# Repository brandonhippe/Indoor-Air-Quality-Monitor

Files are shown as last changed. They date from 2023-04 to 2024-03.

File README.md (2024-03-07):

# 412AirQualityCapstone
2023 Portland State University ECE 412 Air Quality Capstone Project
<br>
<p>
We spend most of our lives indoors, but most of us lack the tools to assess the quality of the air
we breathe in those environments. Personal tools are available, albeit expensive, and must be
inconveniently carried with us along with all the other tools of our daily lives. Instead, we want to
make it easy to instrument buildings, continuously monitor the indoor environment, and report
data back to us. We can make it easy by making cheap, reliable devices that don't need
recharging for a long time. Three features of indoor air are expected to be monitored: 2.5 μm
particle count or PM2.5, carbon dioxide (CO2) concentration, and ventilation air speed.</p>
<br>
<p>
Regarding CO2, Statistically significant decrements occurred in cognitive performance
(decision making, problem resolution) starting at 1000 ppm . It is also a
good proxy for ventilation; high CO2 levels mean the room is poorly ventilated, which increases
the risk of passing airborne diseases such as COVID. After I finish Zoom meeting in a closed
room at home, the CO2 level is often over 1200!</p>
<br>
<p>
Regarding PM2.5, the WHO recommends an upper limit of 5 ug/m3 (microgram per cubic
meter) average annually and 15 ug/m3 average over a 24 hour period. As this project
document is being written, the outdoor air in Portland is over 30 ug/m3!</p>
<br>
<p>
An air speed sensor, or anemometer, can help us calculate how much air is flowing into or out of
a room and help understand why CO2 is high. The system should report an invalid value (e.g.,
not zero because zero airflow is a valid value) if the anemometer is not connected.</p>
<br>
<p>The system will be based on components past capstone teams have successfully incorporated
such as the TI MSP430 (including super low-power sleep modes). In this iteration, we will aim to
replace the closed-source proprietary SmartMesh IP wireless system with the OpenWSN
open-source wireless networking system.</p>
<br>
<h3>Project Goals</h3>
<br>
<p>Produce a fully wireless sensor data logger incorporating as many open-source components as
possible and able to be produced at a very low cost. A particular goal of this project is very low
power performance: sensors, communication system, and the microcontroller should be in as
low a power state as possible when not in use such that batteries need to be changed, at most,
annually. (The lifetime of a smoke detector would be even better!)</p>
<br>
<p>Data should be temporarily logged locally and wirelessly communicated to base station(s) as
appropriate. A stretch goal includes visualization dashboard to present the logged data
graphically for at-a-glance use. The device should be mechanically integrated into as small a
form-factor as is practical and contained in a robust housing appropriate for indoor
environments.</p>

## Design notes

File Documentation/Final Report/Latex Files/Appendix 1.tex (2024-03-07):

\begin{table}[htbp]
  \centering
  \small
  \renewcommand{\arraystretch}{1.2}
  \begin{adjustbox}{max width=\textwidth}
      \begin{tabular}{|l|l|l|r|r|}
        \hline
        Quantity & Model \# and description & Manufacturer & Price per unit & Total Price \\ 
        \hline
        1 & CG-Anem (Wind Sensor With I2C Interface) & Climate Guard & \$23 & \$23 \\ 
        \hline
        1 & SGP30: (eCO$_2$ Sensor) & Adafruit & \$17.50 & \$17.50 \\ 
        \hline
        1 & US-100 Ultrasonic Distance Sensor Module & Adafruit & \$6.95 & \$6.95 \\ 
        \hline
        1 & SPS30 (PM2.5 Sensor)  & Sensirion & \$50.25 & \$50.25 \\ 
        \hline
        4 & P Channel Mosfet & Alpha-Omega & \$0.35 & \$1.40 \\ 
        \hline
        2 & N Channel Mosfet & Alpha-Omega & \$0.33 & \$0.66 \\ 
        \hline
        6 & 47k Resistor & Yageo & \$0.04 & \$0.24 \\ 
        \hline
        3 & 0 ohm Resistor & Yageo & \$0.05 & \$0.15 \\ 
        \hline
        9 & Pin Header & Sullins & \$0.57 & \$5.13 \\ 
        \hline
        2 & Pin Header Male & Molex & \$0.67 & \$1.34 \\ 
        \hline
        1 & MSP-EXP430FR2355 & Texas Instruments & \$15.33 & \$15.33 \\ 
        \hline
        4 & LI18650JL PROTECTED & Jauch Quartz & \$13.05 & \$52.20 \\ 
        \hline
        1 & BK-18650-PC8 (4 cell 18650 battery holder) & MPD & \$8.06 & \$8.06 \\ 
        \hline
        1 & DC9003A-C (SmartMesh) & Analog Devices & \$642 & \$642 \\ 
        \hline
      \end{tabular}
  \end{adjustbox}
\end{table}

\begin{table}[htbp]
  \centering
  \small
  \renewcommand{\arraystretch}{1.2}
  \begin{adjustbox}{max width=\textwidth}
    \begin{tabular}{|l|l|}
        \hline
        Model \# and description & Link \\ \hline
        CG-Anem (Wind Sensor With I2C Interface)          & \url{https://www.tindie.com/products/climateguard/wind-sensor-with-i2c-anemometr-arduino/} \\ \hline
        SGP30: (eCO$_2$ Sensor)                           & \url{https://www.digikey.com/en/products/detail/adafruit-industries-llc/3709/8258468} \\ \hline
        US-100 Ultrasonic Distance Sensor Module          & \url{https://www.digikey.com/en/products/detail/adafruit-industries-llc/4019/9808308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} \\ \hline
        SPS30 (PM2.5 Sensor)                              & \url{https://www.digikey.com/en/products/detail/sensirion-ag/SPS30/9598990} \\ \hline
        P Channel Mosfet                                  & \url{https://www.digikey.com/en/products/detail/alpha-omega-semiconductor-inc/AO3401A/1855773} \\ \hline
        N Channel Mosfet                                  & \url{https://www.digikey.com/en/products/detail/alpha-omega-semiconductor-inc/AO3422/1855787} \\ \hline
        47k Resistor                                      & \url{https://www.digikey.com/en/products/detail/yageo/RC1206FR-0747KL/728931} \\ \hline
        0 ohm Resistor                                    & \url{https://www.digikey.com/en/products/detail/yageo/RC1206JR-070RL/729184} \\ \hline
        Pin Header                                        & \url{https://www.digikey.com/en/products/detail/sullins-connector-solutions/PPPC101LFBN-RC/810182} \\ \hline
        Pin Header Male                                   & \url{https://www.digikey.com/en/products/detail/molex/0022284104/313970} \\ \hline
        MSP-EXP430FR2355                                  & \url{https://www.digikey.com/en/products/detail/texas-instruments/MSP-EXP430FR2355/9491427} \\ \hline
        LI18650JL PROTECTED                               & \url{https://www.digikey.com/en/products/detail/jauch-quartz/LI18650JL-PROTECTED/12396970} \\ \hline
        BK-18650-PC8 (4 cell 18650 battery holder)        & \url{https://www.digikey.com/en/products/detail/mpd-memory-protection-devices/BK-18650-PC8/2330515} \\ \hline
        DC9003A-C (Smart Mesh)                            & \url{https://www.mouser.com/ProductDetail/Analog-Devices/DC9003A-C?qs=ytflclh7QUUd5QPivzMO2w\%3D\%3D} \\ \hline
    \end{tabular}
  \end{adjustbox}
\end{table}
\label{tab:BOM}
Total Price: \$166.88 excluding given parts \$182.21 including MSP430

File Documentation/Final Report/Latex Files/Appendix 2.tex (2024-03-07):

\renewcommand{\thesubsection}{2.\arabic{subsection}}
\subsection{Energia Issues}
Make sure “Energia MSP430 boards” is updated to version 1.0.7 or later by going to Tools, then Board, then Board Manager.
\subsection{Java Runtime Environment error}

To solve this issue, You must save Energia to your C: Folder and open it from there each time. The Desktop Shortcut will keep giving you this error. 

\subsection{Sensor Issues}
Sensors drawing too much power:
\\We removed the power and low power LEDs on all of the sensors used as they were drawing too much.
\\CO2 sensor showing 400 PPM or 55K PPM:
\\Stop calibrating, run it for 30 seconds.

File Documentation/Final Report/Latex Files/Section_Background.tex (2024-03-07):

Our team wanted to make it easy to continuously monitor an indoor environment, and report data back to a host. Our aim was to make monitoring easy by making cheap, reliable devices that do not require frequent recharging. Three features of indoor air quality are expected to be monitored: 2.5 µm particle count or PM2.5, carbon dioxide (CO$_2$) concentration, and local air flow rate.\\
\\
Regarding CO$_2$, statistically significant decrements occurred in cognitive performance
(decision making, problem resolution) starting at 1000 ppm.  CO$_2$  concentration is also a
good proxy for ventilation; high CO$_2$ levels mean the room is poorly ventilated, which increases
the risk of passing airborne diseases such as COVID19.\\
\\
Regarding PM2.5, the WHO recommends an upper limit of 5 µg/m3 (microgram per cubic
meter) average annually and 15 µg/m3 average over a 24 hour period . \\
\\
An air speed sensor, or anemometer, can help us calculate how much air is flowing into or out of
a room and help understand why CO$_2$ and/or PM2.5 is high. \\
\\
The system is based on components past capstone teams have successfully incorporated
such as the TI MSP430 (selected for its particularly low-power sleep modes). In this iteration, a goal was to
replace the closed-source proprietary SmartMesh IP wireless system with the OpenWSN open-source wireless networking system.\\
\\

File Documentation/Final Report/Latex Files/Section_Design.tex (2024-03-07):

When selecting sensors for this project, the team had to select PM2.5 and CO$_2$ sensors that were energy efficient, relatively accurate for our setting, and fit within a budget of \$3,000 for all 10 possible nodes. \\
\\
When selecting the CO$_2$ sensor, the team considered selecting a true CO$_2$ sensor like the SCD30 which would produce very accurate readings yet was more expensive than an ECO2 (estimated CO$_2$) sensor which would prove to be less accurate due to its nature of estimating CO$_2$ based on ethanol and H$_2$ levels in the air. Our team ultimately chose to go with the SGP30 (equivalent CO$_2$) sensor as we are merely sensing elevated levels of carbon dioxide and therefore do not need to get incredibly precise readings. Anything over 1,000 PPM would simply be very high and might constitute an evacuation of room or need for more airflow. \\
\\
\begin{table}[h]
\centering
\begin{tabular}{|l|l|l|}
\hline
Sensor             & SGP 30      & SCD 30                   \\ \hline
Type               & eCO$_2$      & CO$_2$                     \\ \hline
Additional sensors & VOC         & temperature and humidity \\ \hline
Range              & 400-60,000 PPM & 400-10,000 PPM              \\ \hline
Accuracy           & $\pm$15\%      & $\pm$30 PPM +3\%              \\ \hline
Price              & \$17.50      & \$58.95                   \\ \hline
\end{tabular}
\caption{CO$_2$ Sensor Finalists}
\label{tab:CO_2 Sensor Finalists}
\end{table}
\\
\subsection{PM2.5 Sensor}
For the PM2.5 sensor, the team decided to go with the SPS30 as it was the least power hungry among our options at the time. It was also the most readily available, and was sourced from Sensirion like the SGP30 which would cut costs if this product were to be mass produced. The PM2.5 Sensor Finalists table below shows the specific trade offs our team considered when selecting this sensor.\\
\\
\begin{table}[h]
\centering
\resizebox{\textwidth}{!}{%
\begin{tabular}{|l|p{4cm}|p{4cm}|p{4cm}|}
\hline
Sensor                      & PMS5003                                                                & PAS-IN-01                                & SPS30                                    \\ \hline
Range (concentration)       & 0-500 ug/m\textasciicircum{}3            & 0-1500 ug/m\textasciicircum{}3           & 0-1000 ug/m\textasciicircum{}3           \\ \hline
Accuracy                    & ±10\% or ±10 ug/m3, whichever is greater &  ±10\% or ±10 ug/m3, whichever is greater & ±10\% or ±10 ug/m3, whichever is greater \\ \hline
Power Consumption (on)      & $\sim$500mW                                                        & $\sim$350mW                              & $\sim$275mW                              \\ \hline
Price                       & \$39.95                                                                & \$19                                     & \$49.53                                  \\ \hline
Accurate data & 30 seconds                                                           & 15 seconds                               & 10 seconds                               \\ \hline
\end{tabular}
}
\caption{PM2.5 Sensor Finalists}
\label{tab:PM2.5 Sensor Finalists}
\end{table}
\subsection{Anemometer}
When selecting an anemometer, we originally preferred the concept of designing and building an ultrasonic anemometer as it was significantly more energy efficient than hot wire anemometer options. Due to issues with building a custom sensor as well as difficulties with procuring parts in a speedy manner, we decided to pivot to a hot wire anemometer. This selection produced a drastic detriment to our anticipated battery life. We originally calculated that we could complete the project with just 1 battery, however we needed to add 3 more batteries to achieve the same battery life of a year with the substitution of a hot wire anemometer. To accommodate for the increased temperature, we also had to give the part extra space and keep it as far away from our other sensors as possible. We suggest future builds expand upon our ultrasonic anemometer research, implementation and documentation in an attempt to prevent the use of hot wire anemometers in this setting. \\
% Please add the following required packages to your document preamble:
% \usepackage{graphicx}
\begin{table}[h]
\centering
\resizebox{\textwidth}{!}{%
\begin{tabular}{|l|l|l|}
\hline
Sensor                 & Custom Ultrasonic Anemometer & PAS-OUT-01Wind Sensor Rev. C                                 \\ \hline
Range                  & Unknown and size dependent   & 0-60 MPH                                                     \\ \hline
Power consumption (on) & $\sim$14.52mW                & $\sim$150mW                                                  \\ \hline
Accuracy               & Unknown and size dependent   & Can detect "small puff of air at a distance of 18-24 inches" \\ \hline
Price                  & \$7.90                       & \$21.95                                                      \\ \hline
Relative size          & $\sim$25-36 cm apart         & .68" x 1.59" x .25"                                          \\ \hline
\end{tabular}%
}
\caption{Anemometer Sensor Finalists}
\label{tab:Anemometer Sensor Finalists}
\end{table}
\\
\begin{figure}[H]
    \centering
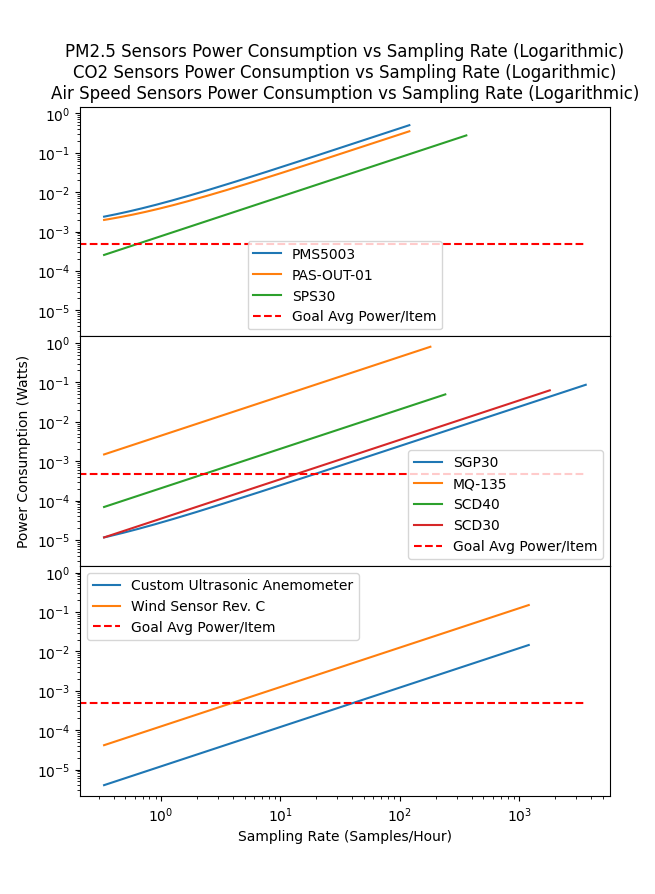
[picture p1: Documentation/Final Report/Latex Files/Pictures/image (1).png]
    
    \caption[Power consumption measurements with sensor options]{Power consumption measurements with sensor options} 
    \label{fig:part1commrin}
\end{figure}
In Figure 2, the team created a python script to calculate the power consumption based on listed values from the specification sheets of the sensors. The python script can be found under the power testing folder in the documentation folder. The python script is titled \texttt{powerEstimation.py}. The link for the team Github page can be found in the project resources section. The red line shows the sampling rate needed to hit 1 year of battery life based on the estimates. \\
\\
%Below are some links to the sites we used when determining the ideal location for
%the sensors Sensor installation. FORMAT LINK
\\
\subsection{Enclosure}
When deciding on our enclosure. We wanted to minimize our SWaP-C, which stands size, weight, power, and cost. For our first iteration, we built a system utilizing Portland State University’s 3D printing. The 3D printer at the time only offered SLA. The helpers at the Electronics Prototyping Lab (EPL) recommended we switch to laser cutting acrylic as it is much cheaper, faster, and is clear. To cut the enclosure, we used MakerCase (https://www.makercase.com/\#/) as recommended by the EPL. The laser cutter utilized at the time of project was the QD-1390. \\
\\
\begin{figure}[H]
    \centering
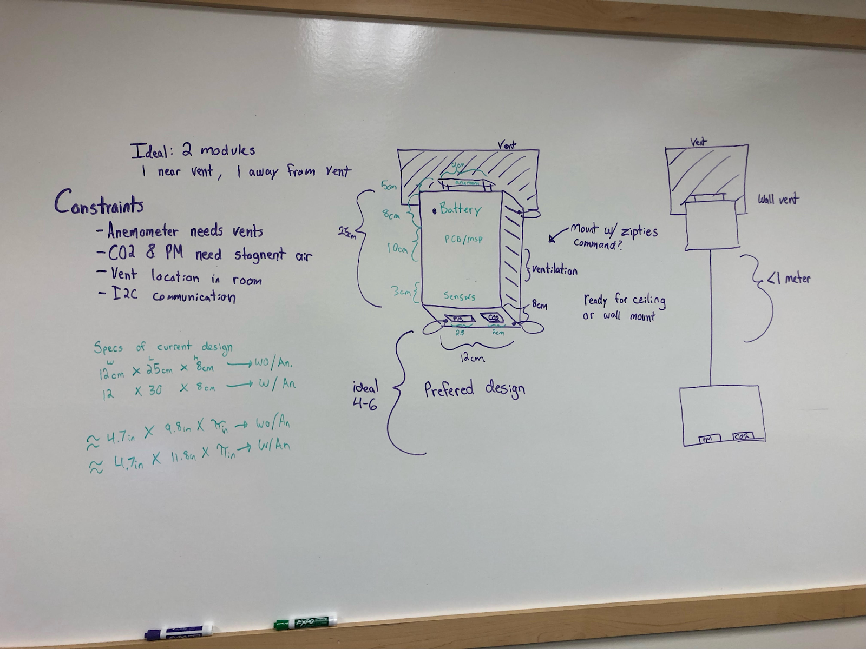
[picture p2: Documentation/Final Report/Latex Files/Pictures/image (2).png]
    
    \caption[Original concepts for enclosure]{Original concepts for enclosure} 
    \label{fig:part1commrin}
\end{figure}
When designing the enclosure, we originally came up with the two ideas shown above. The rightmost diagram represented 2 enclosures separated by an I2C cable. This would allow us to get accurate readings for CO$_2$ and PM2.5 in the bottom enclosure, and accurate anemometer readings in the above enclosure. Having two nodes seperated by an I2C cable would allow for the anemometer to be placed near a vent while the CO$_2$ and PM2.5 sensors could be placed in the desired range for accurate readings. This design proved to be infeasible because we were limited by the maximum 1 meter length for an I2C cable. We switched to the design on the left focusing on increased ventilation and allowing for proper separation of parts to ensure no damage is caused by the batteries. We also aligned the sensors to face downwards while the anemometer could face sideways towards the vent. Final dimensions came out to be 
12 x 25 x 8 cm without an anemometer and
12 x 30 x 8 cm with an anemometer. This design requires several modules to be placed in one room, with an anemometer node being placed in front of an air vent while a second node without an anemometer could be placed in a stagnant area of the room. This accounts for both air entering the room as well as an accurate measurement of the air quality in the room. The non anemometer node should ideally be placed four to six feet above the ground as according the Environmental Protection Agency (EPA) for the most accurate CO$_2$ and PM2.5 readings

\subsection{System Design}
At the highest level view our system design started very simple. We have our microcontroller that communicates and receives data from all of our sensors, we have that microcontroller communicate with smartmesh to send out our measured data, and lastly we have a battery powering it all. We ended up having to make this system more complicated in order to extend our battery life and make the system generally more robustly. We added pmos transistors in order to cut off power and put our sensors in a deeper sleep then their internal circuits would allow. We added nmos transistors in order to perform logic level conversion for our 5V sensors. We added 3.3V and 5V power conversion in order to better supply off of our 3.7V batteries. Lastly, we added further functionality to our circuit with hardware system low battery warnings. Combined we now have a a fair amount of added resistors, voltage dividers, mosfets, and breakouts that allow for a more user friendly experience.
\begin{figure}[H]
    \centering
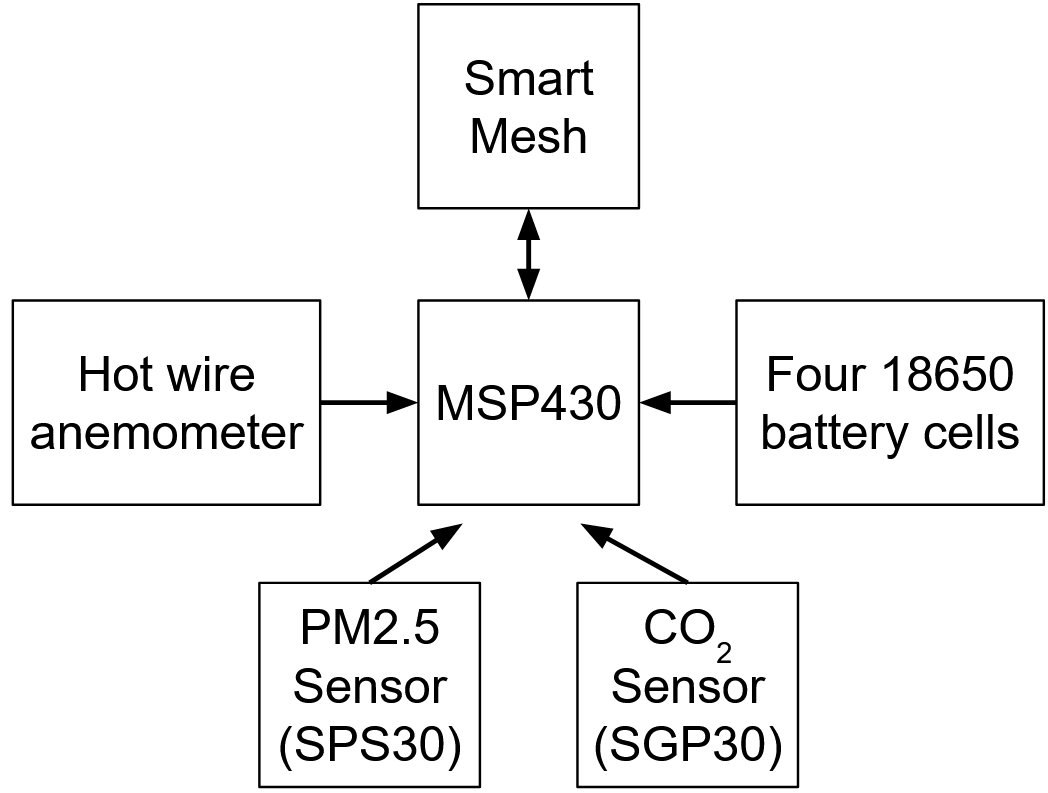
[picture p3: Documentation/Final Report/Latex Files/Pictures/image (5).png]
    
    \caption[Block Diagram of individual Node]{Block Diagram of individual Node} 
    \label{fig:part1commrin}
\end{figure}

\begin{figure}[H]
    \centering
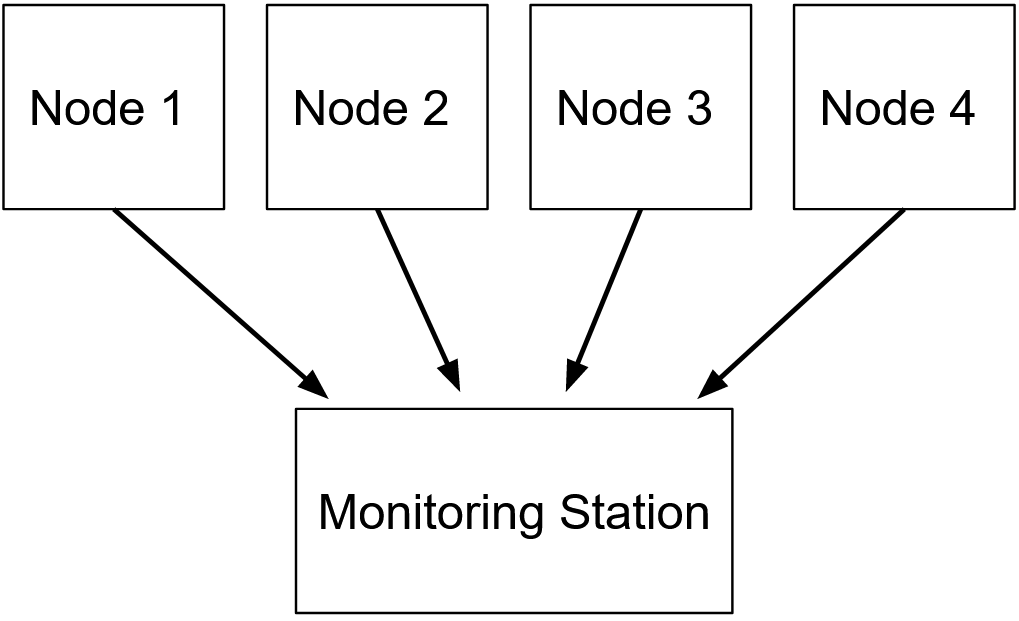
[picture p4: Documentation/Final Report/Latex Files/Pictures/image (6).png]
    
    \caption[Block Diagram of Meshed System]{Block Diagram of Meshed System} 
    \label{fig:part1commrin}
\end{figure}

\subsection{PCB Design}
\begin{figure}[H]
    \centering
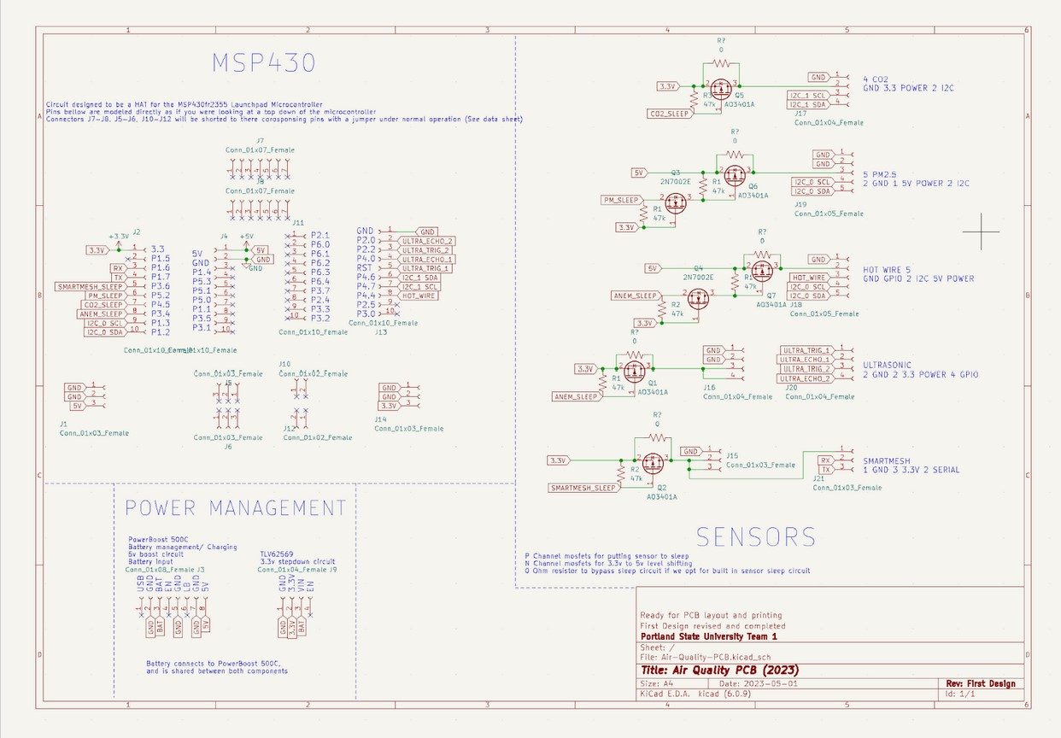
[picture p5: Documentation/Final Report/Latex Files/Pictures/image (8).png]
    
    \caption[PCB Design]{PCB Design} 
    \label{fig:part1commrin}
\end{figure}

For our PCB, we decided that we wanted our system to be as compact and easy to use as possible. In order to make this a reality we made a hat For the MSP430, or in simpler terms a PCB that is placed directly on top of the MSP430 pins. This was a challenge because we were not able to find standard measurements for the MSP430FR2355 microcontroller, and had to take 15 or so measurements using digital calipers. 

Designing a hat as our board design created unique opportunities that allowed us to streamline and simplify connections, and ended up leading to a cleaner looking final design. We were able to position our power management as close to the microcontoller power ports as possible, and place our signal wires extremely close to where the signals originated from, limiting potential losses that we might have had with longer or messier signal routing.

\subsection{Scheduling}
The team Created a followed the following Gantt charts to reflect the schedule for the project beginning in December of 2022 and concluding in June of 2023.
\begin{figure}[H]
    \centering
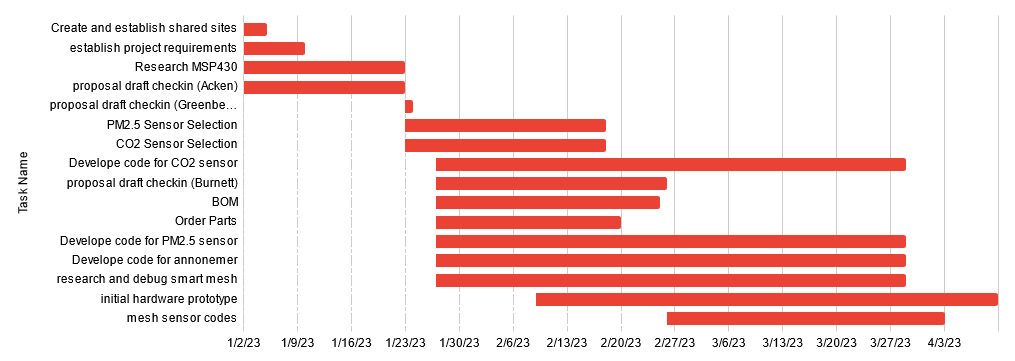
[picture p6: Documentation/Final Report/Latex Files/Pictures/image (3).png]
    
    \caption[Gantt chart for winter term]{Gantt chart for winter term} 
    \label{fig:part1commrin}
\end{figure}
\begin{figure}[H]
    \centering
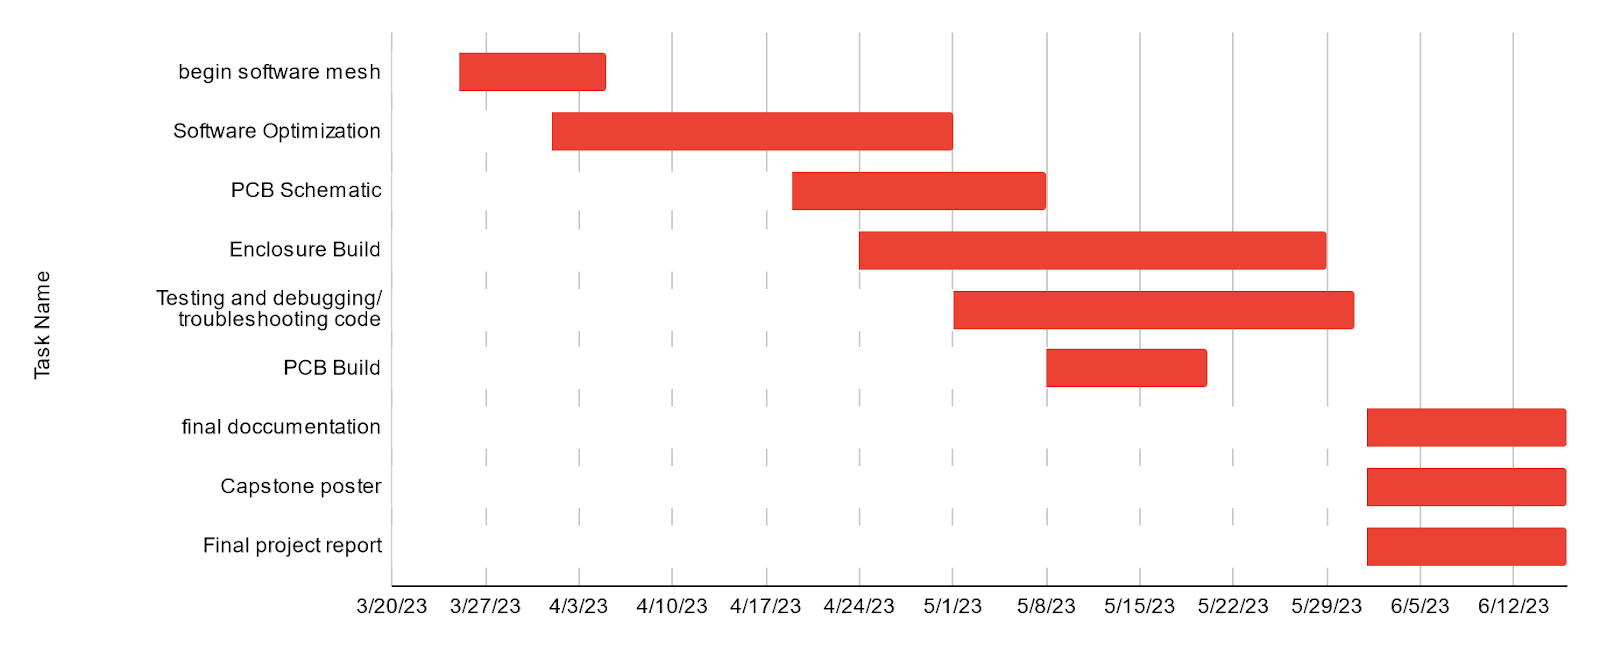
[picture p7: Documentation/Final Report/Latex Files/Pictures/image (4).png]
    
    \caption[Gantt Chart for spring term]{Gantt Chart for spring term} 
    \label{fig:part1commrin}
\end{figure}

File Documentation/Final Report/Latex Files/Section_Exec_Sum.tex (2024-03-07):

Air quality is very important for safe working conditions. In every indoor space there should be a monitoring system for environmental risks and air pollutants such as CO$_2$ and fine particulate matter (PM2.5), as well as ventilation rates. Our team’s goal was to build a device to monitor elevated or dangerous quantities of these pollutants using as many commercial off-shelf components and open-source software as possible. Our aim was to create 3 to 10 wireless, battery powered initial prototypes that each have at least one year life span.\\
\\
This project is sponsored by the Wireless Environmental Sensor Technologies (WEST) Lab in the Electrical and Computer Engineering Department at Portland State, run by Dr. David C. Burnett. The project’s faculty advisor is Dr. John M. Acken.\\
\\
This project will be improving on the project from spring of 2022\cite{leon2023networked} to report readings of carbon dioxide, particulate matter, and airflow in an indoor environemnt instead of N$_2$O, temperature, and humidity in an outdoor environment.\\
\\
The team was successful in the project. We completed the project with 4 working nodes that communicate with each other using SmartMesh IP. The units can achieve a battery life of a year with reasonable capture times. Each unit is also equipped with the SGP30 CO$_2$ sensor, SPS30 PM2.5 sensor, and ClimateGuard Hotwire Anemometer to collect data. The system is housed in a cut acrylic box that can be mounted on walls or ceilings.\\
\\
This report details the background of this project, project requirements, and our approach to tackling this project. We also included appendices that contain the operation manual, issues we faced and solutions, and the components and software we used throughout the project.

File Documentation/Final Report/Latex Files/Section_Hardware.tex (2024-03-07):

\subsection{Part 1: Building PCB}
\begin{enumerate}

\item Go to GitHub Repository and save all the .gbr files under the Air-Quality-PCB folder. 

\begin{figure}[h]
    \centering
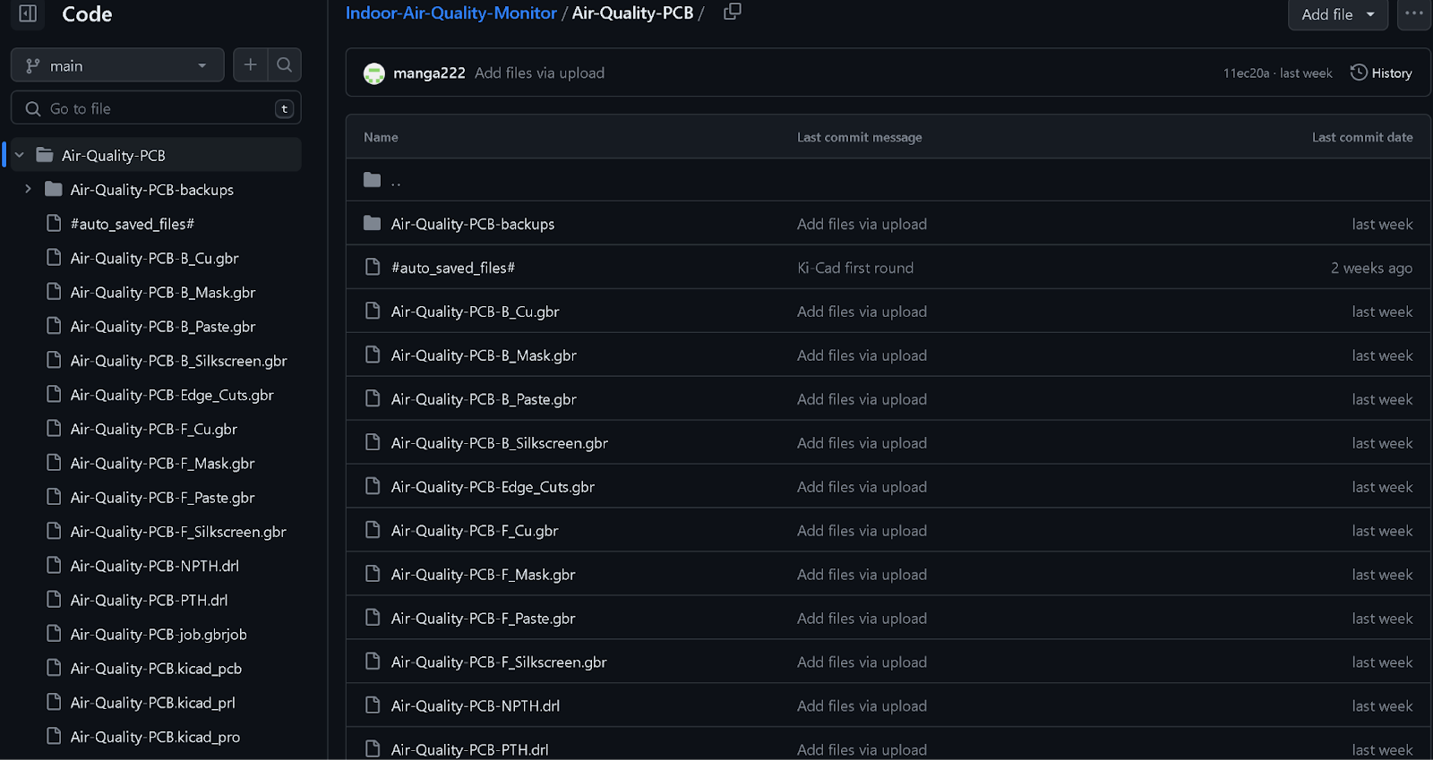
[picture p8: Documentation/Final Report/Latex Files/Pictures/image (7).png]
    
    \caption[GitHub Repository]{GitHub Repository} 
    \label{fig:part1commrin}
\end{figure}

\item Open the website of your PCB manufacturer and go to their ordering page
\item We used JLCPCB for the project as they were the cheapest and fastest at the time. Link can be found in the project resources section
\item Drag and drop all the .gbr files 
\item Select your options 
\item We selected the default options at time but chose to go with faster delivery 
\item Solder on connection points so the MSP430 can be seated onto the PCB
\item Solder pins onto powerboost charger as well as the 3.3V converter 
\item We ended up removing LED (power and Low indicators) since they consumed too much power and were always on
\end{enumerate}

\subsection{Part 2: Building Enclosure}
\begin{enumerate}

\item Using a laser cutter, cut out the file \texttt{box\_v2.dxf}. It is designed to be cut out of $\frac{1}{{8}}$ inch thick acrylic, but any other $\frac{1}{{8}}$ inch thick material should work. For different thickness materials, the enclosure would have to be redesigned. For reference, a 16 inch x 24 inch sheet is enough to cut out parts for one enclosure. Alternatively, a pre-built plastic enclosure of a similar size could be used, with holes cut for sensors at the same size as our enclosure holes.
\item The batteries and anemometer must be placed as far away from the PM2.5 and CO$_2$ sensor as possible. 
\item The PM2.5 and CO$_2$ must be mounted at the bottom of the enclosure to ensure that they are not susceptible to particle build up. Mount the PM2.5 sensor so that the green side is facing out and away from the wall when mounted.
\item Hot glue the sides of the enclosure while placing the components in the box as it is being assembled. Do not hot glue the lid on. Use clear tape to secure the lid.
\end{enumerate}

\subsection{Part 3: Mounting the Enclosure}
\begin{enumerate}
    \item Once the enclosure build is complete, attach 4 Command Picture Hanging Velco Strips, 1 to each corner of the back wall of the enclosure.
    \item Select a wall to mount enclosure to. For the Anemometer enclosure, mount the unit near air source or vent. For enclosures without an anemometer, mount away from doors, windows or vents. Mount enclosures without anemometers approximately 4-6 feet above ground. 
    \item When batteries need to be changed, detach system. Reattach system when batteries are replaced by again securing system to wall via velcro. 
\end{enumerate}

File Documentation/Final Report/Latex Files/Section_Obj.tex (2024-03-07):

The following represent deliverables our team identified as significant to doccument the project:
\begin{itemize}
\item Complete documentation:
\begin{itemize}
\item Project proposal
\item Weekly Progress Reports
\item Final report
\item ECE Capstone Poster Session poster
\end{itemize}
\item Summary project report in the style of an IEEE conference paper
\item Bill of materials
\item System schematic and functional diagram
\item Design files for any custom mechanical components or PCBs
\item Source code
\item Operation guide
\item Demonstration of hardware
\item Three to ten sensor system prototypes
\end{itemize}

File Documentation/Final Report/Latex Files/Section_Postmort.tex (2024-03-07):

In retrospect, we feel our project was very successful. Our team was able to collaborate in order to execute this project. Our team played to each of our specific talents which made for an excellent work environment.

Our team faced a variety of challenges in regards to using MSP430s, SmartMesh, enclosure building and PCB design. Connecting each team member to their respective MSP430 proved to be more challenging than many of us had anticipated. Documentation surrounding MSP430 was scarce and oftentimes unhelpful. Most of our team members needed to delete Energia files and redownload before each use to connect with the MSP430. SmartMesh also had many problems that previous teams have not encountered. Our original ultrasonic anemometer proved to be much harder to work with which is why we switched to the hotwire option despite the huge discrepancy in power use.

The combination of all these problems and our approach to doing each part separately proved unfruitful as we had not built a prototype by the midpoint of the timeline. This is when we switched to dedicating a set time to work on the project weekly, in person, as a team. This proved to accelerate our progress as it allowed us to help each other at roadblocks. We also learned that some of our MSP430s were much more prone to having issues than others. This allowed us to rapidly prototype a working node on the fastest system and MSP430. This also allowed different members to shift rapidly to complete auxiliary projects like reports and presentations.

Many thanks to our industry sponsor and faculty advisor who requested that we present our progress a several times throughout our project as well as requesting an updated Gantt chart weekly. This allowed us to compile our progress and have a clear path at a glance. Weekly meetings with at least 1 of the advisor or sponsor also proved necessary to work through a multitude of problems and is credited to keeping us working on the requirements. 

Documentation was something that we excelled at throughout the project. Notes of weekly meetings were documented on the team’s Trello board. Weekly reports and any documentation was copied to the team’s Google Drive, Github repository, Trello board, and emailed to the advisor and sponsor. We also built a website to host some of this information.

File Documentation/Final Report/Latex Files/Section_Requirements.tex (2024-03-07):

The sensor system must:
\begin{itemize}[label=$\bullet$]
  \item Sense PM2.5 and CO$_2$ often enough and accurately enough to ascertain indoor air quality relevant to occupants
  \item Include at least one node capable of sensing airspeed
  \item Maximize its battery life for sustained operation
  \item Locally store its measurement data
  \item Use as many commercial off-the-shelf components as possible
  \item Have an enclosure
  \item Wirelessly share its measurement data with a central monitoring system with communication range of at least 10 meters
  \item Utilize SmartMesh IP
  \item Have 3 iterations that cost no more than \$1,000 total
\end{itemize}

The sensor system should:
\begin{itemize}[label=$\bullet$]
  \item Include capability for any node to sense airspeed
  \item Have a battery life of at least 1 year
  \item Be open-source to the extent possible when using commercial off-the-shelf components
  \item Upgrade SmartMesh IP to utilize a low-power Wireless Sensor Network (WSN) system like OpenWSN 
  \item Utilize Texas Instruments MSP430/432 class microcontroller unit
  \item Have 10 iterations that cost no more than \$3,000 total
  \item Utilize 18650 lithium-ion battery cell(s)
\end{itemize}

The sensor system may:
\begin{itemize}[label=$\bullet$]
  \item Source all power from a single 18650 battery
  \item Monitor other environmental conditions such as temperature and humidity
  \item Include self-configuration capability to detect which sensors are connected and adjust sampling rates accordingly
  \item Be usable outdoors
  \item Include a visualization dashboard to monitor the data graphically
  \item Be able to incorporate many more (greater than 10) sensor modules
  \item Match the lifetime of a fire detector (approximately 10 years)
\end{itemize}

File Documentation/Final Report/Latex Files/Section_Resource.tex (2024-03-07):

Software links
List of used software and links:
\begin{itemize}
\item Energia (https://energia.nu/download/)
\item Python (https://www.python.org/downloads/)
\item FTDI Drivers (https://ftdichip.com/drivers/)
\item KiCad(https://www.kicad.org/download/)
\item Github Repository (https://github.com/brandonhippe/Indoor-Air-Quality-Monitor) 
\item FreeCAD (https://www.freecad.org/downloads.php) 
\item JLCPCB (https://cart.jlcpcb.com/quote) 
\item MakerCase (https://www.makercase.com)
\end{itemize}
Versions used at time of build:
\begin{itemize}
\item Energia 1.8.10E23
\item Python 3.11
\item KiCad 7.0.2
\item FreeCAD 0.20.2
\end{itemize}

Website: 
https://web.cecs.pdx.edu/~dburnett/capstone2023/

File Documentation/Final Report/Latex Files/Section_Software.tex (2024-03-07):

\subsection{Setting up the Host Node}
\begin{enumerate}
\item Download Python. Links to download as well as versions used at the time can be found in the project resources section of this report. Install matplotlib and PySerial using the command \texttt{pip install <module name>} in a Python terminal.

\begin{figure}[H]
    \centering
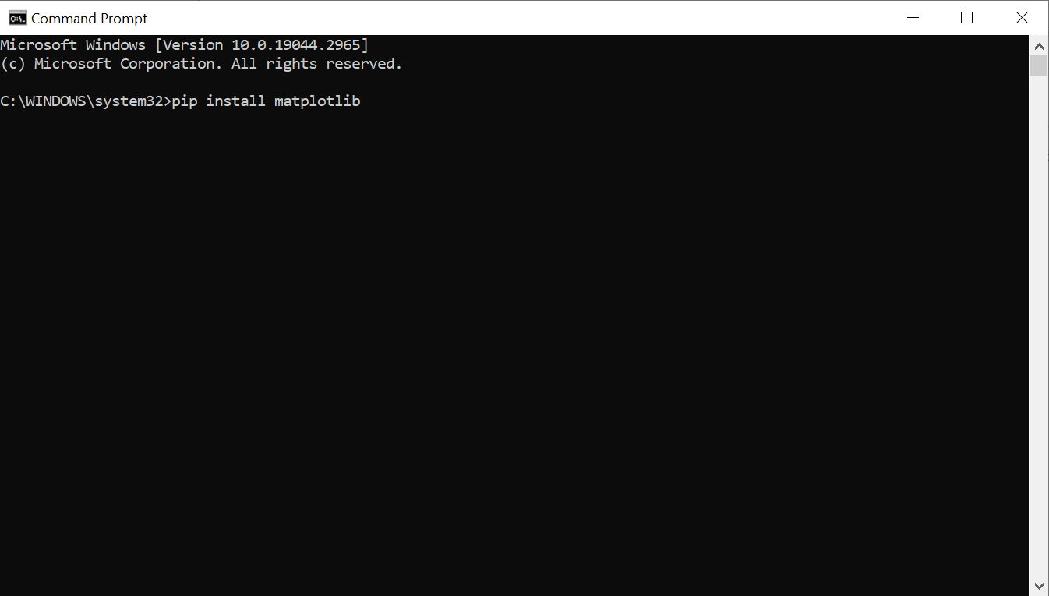
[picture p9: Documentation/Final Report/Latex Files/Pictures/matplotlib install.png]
    
    \caption[Installing matplotlib]{Installing matplotlib} 
    \label{fig:part1commrin}
\end{figure}

\begin{figure}[H]
    \centering
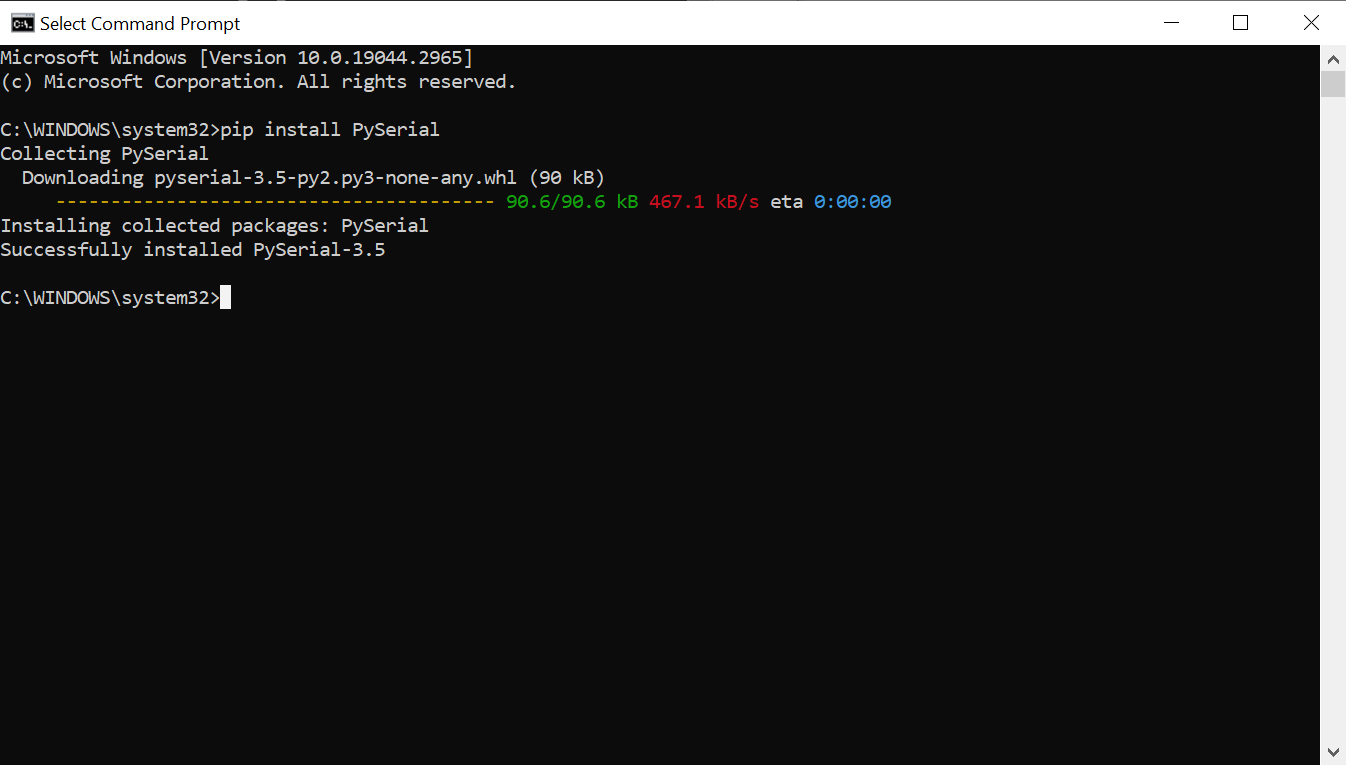
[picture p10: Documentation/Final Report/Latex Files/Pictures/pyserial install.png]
    
    \caption[Installing PySerial]{Installing PySerial} 
    \label{fig:part1commrin}
\end{figure}

\item Clone or download the GitHub repository as a .zip file. If downloaded as a .zip file, extract all of its contents.

\begin{figure}[H]
    \centering
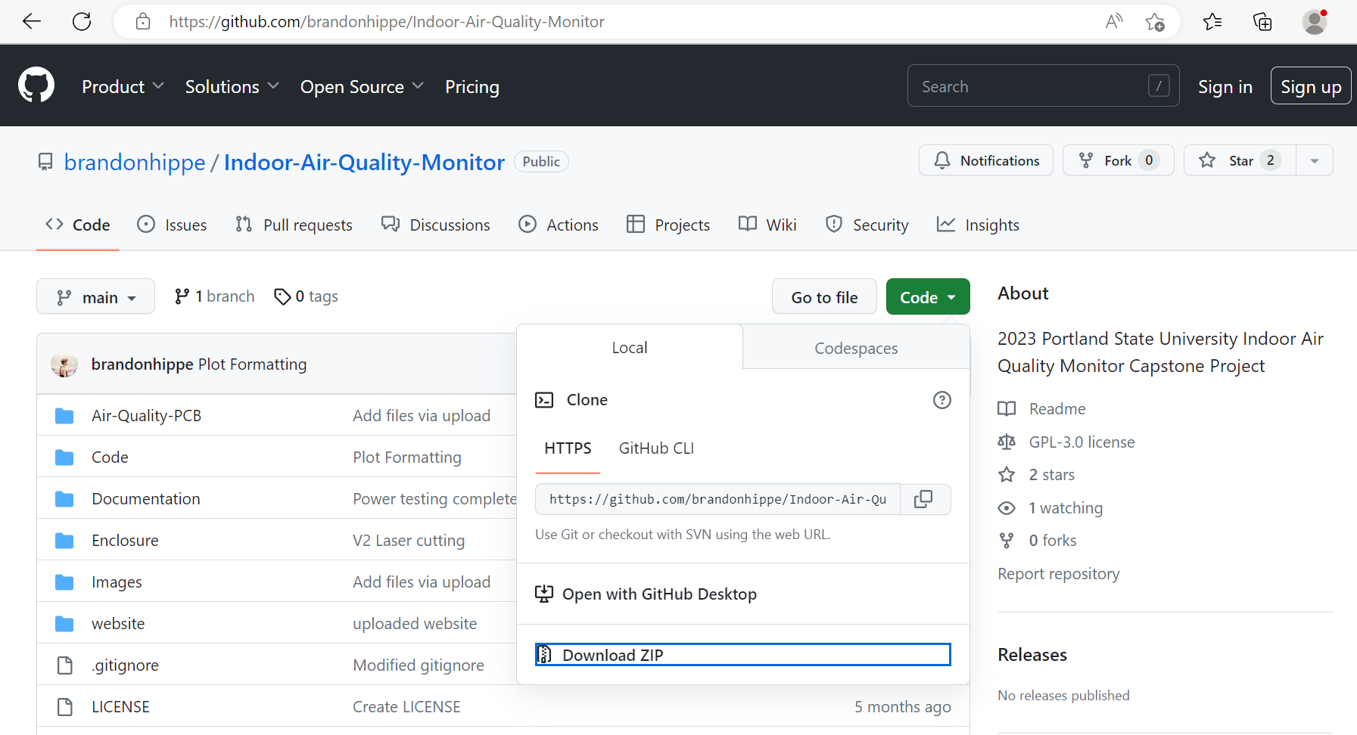
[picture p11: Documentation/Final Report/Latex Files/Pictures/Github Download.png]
    
    \caption[Github Download Page]{Github Download Page} 
    \label{fig:part1commrin}
\end{figure}

\item Open Device Manager and expand the Ports drop-down. Plug the DC2274A-A manager into the computer. Four new COM ports will appear. Take note of the largest of these new ports.

\begin{figure}[H]
    \centering
    
    \caption[Before plugging in manager]{Before plugging in manager} 
    \label{fig:part1commrin}
\end{figure}

\begin{figure}[H]
    \centering
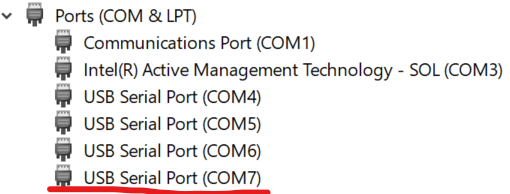
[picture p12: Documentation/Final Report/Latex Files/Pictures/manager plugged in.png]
    
    \caption[After plugging in manager]{After plugging in manager. Note: 4th COM port is underlined} 
    \label{fig:part1commrin}
\end{figure}

\item Navigate to the \texttt{Code/Host Node/app/SensorDataReceiver} folder. Run the \texttt{SensorDataReceiver.py} script. In the popup window, under the port name, type in the COM port from step 3, including "COM." Click connect, and the box should turn green to indicate a successful connection.

\begin{figure}[H]
    \centering
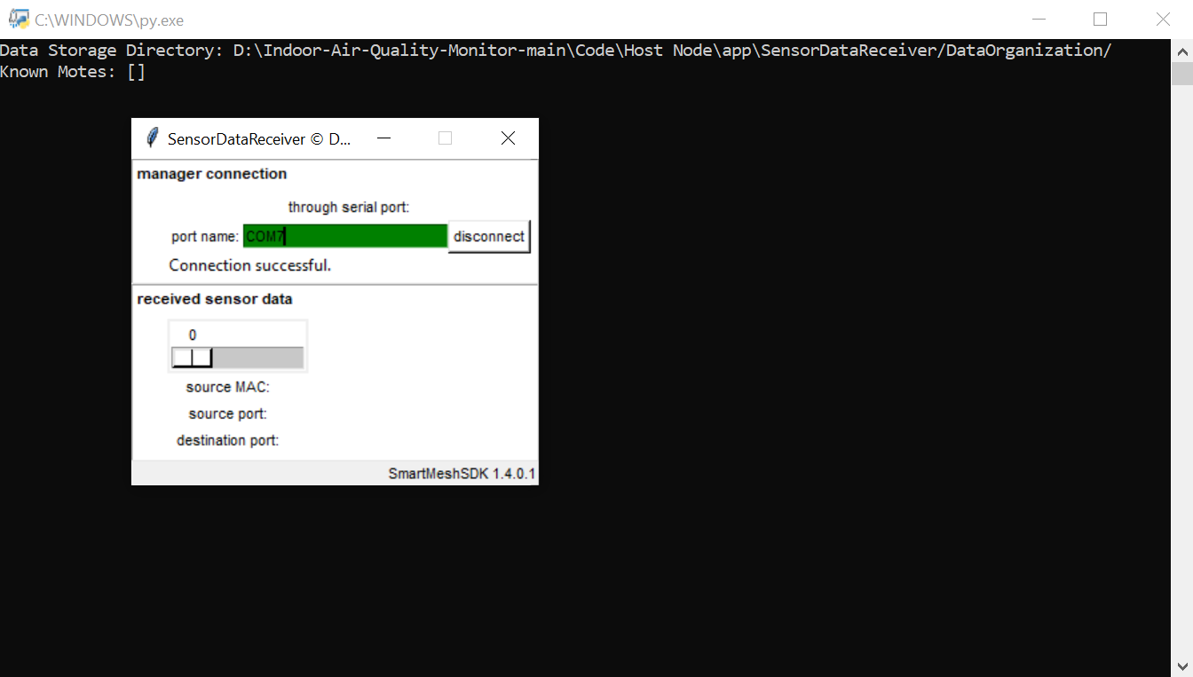
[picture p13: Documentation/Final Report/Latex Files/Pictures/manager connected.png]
    
    \caption[Manager Connected]{Manager Connected} 
    \label{fig:part1commrin}
\end{figure}

\item From the same folder, run the \texttt{iaqGraphing.py} script. A window with three plots should appear on the screen. At the bottom, click the "Plot Example" button. Example data should be plotted in each of the plots.

\begin{figure}[H]
    \centering
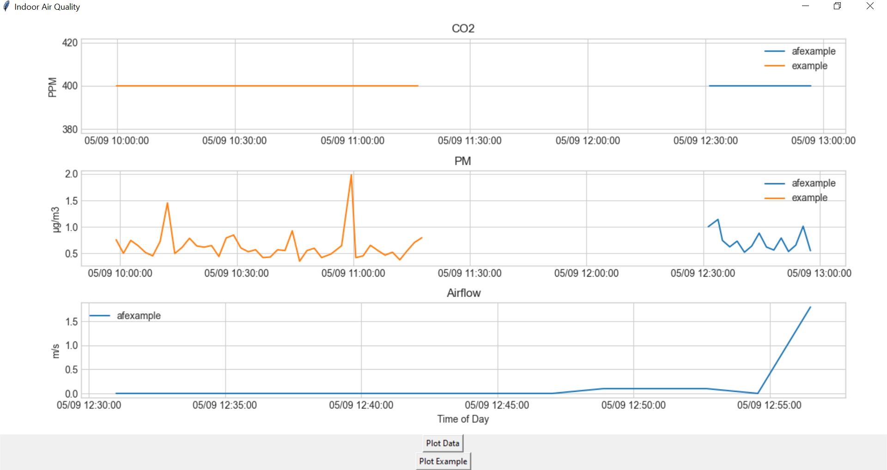
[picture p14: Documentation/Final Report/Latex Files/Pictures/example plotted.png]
    
    \caption[Example data plotted]{Example data plotted} 
    \label{fig:part1commrin}
\end{figure}

\item Now click on the "Plot Data" button. The graph will now plot new data received from the sensors approximately every 10 seconds and display all the data over the last 24 hours.

\begin{figure}[H]
    \centering
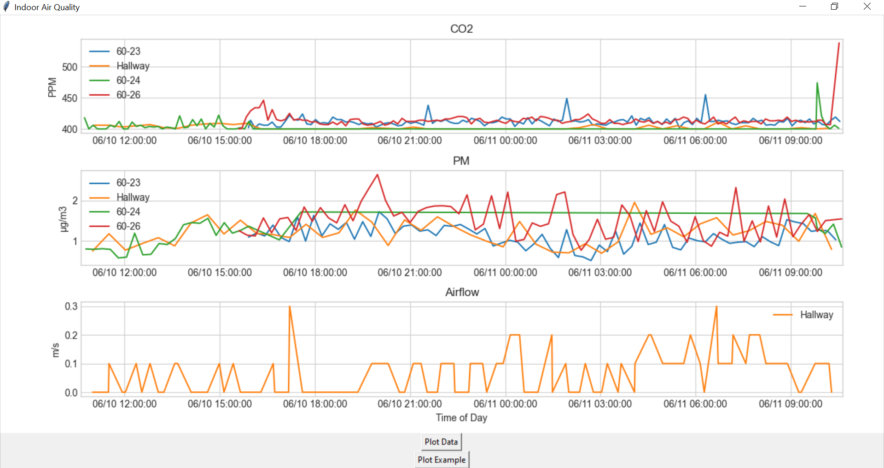
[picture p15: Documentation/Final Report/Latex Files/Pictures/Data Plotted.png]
    
    \caption[Sensor Data Plotted]{Sensor Data Plotted} 
    \label{fig:part1commrin}
\end{figure}

\end{enumerate}

\subsection{Setting up Sensor Nodes}
\begin{enumerate}
\item Download Energia. Links to download as well as versions used at the time can be found in the project resources section of this report.
\item Open the \texttt{Code/Sensor Mote/libraries} folder in the downloaded repository. Copy the contents of this folder into the library folder of your Energia installation (for easiest use, move the Energia folder to the C drive, so the path is something like \texttt{C:\textbackslash energia-1.8.10E23}).

\begin{figure}[H]
    \centering
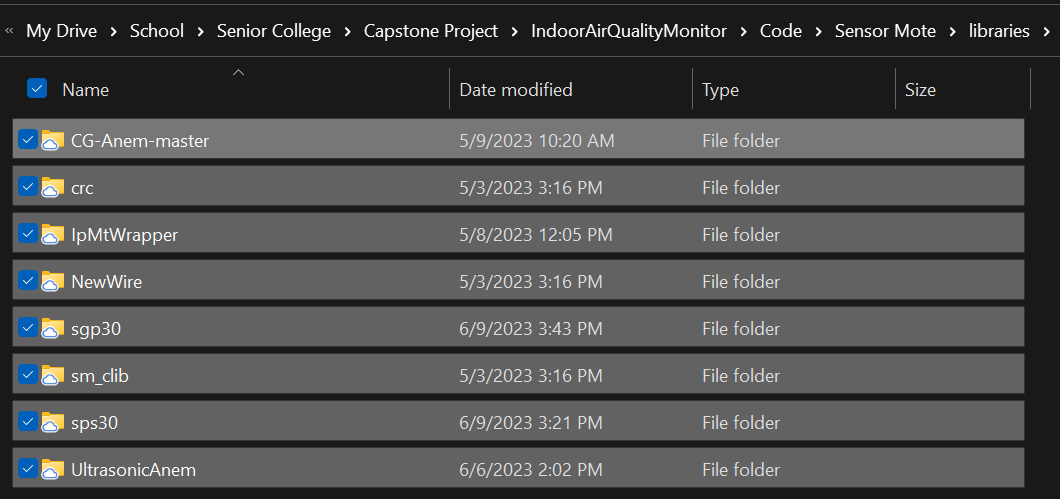
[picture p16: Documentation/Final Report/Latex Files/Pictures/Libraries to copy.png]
    
    \caption[Energia libraries needed]{Energia libraries needed} 
    \label{fig:part1commrin}
\end{figure}

\begin{figure}[H]
    \centering
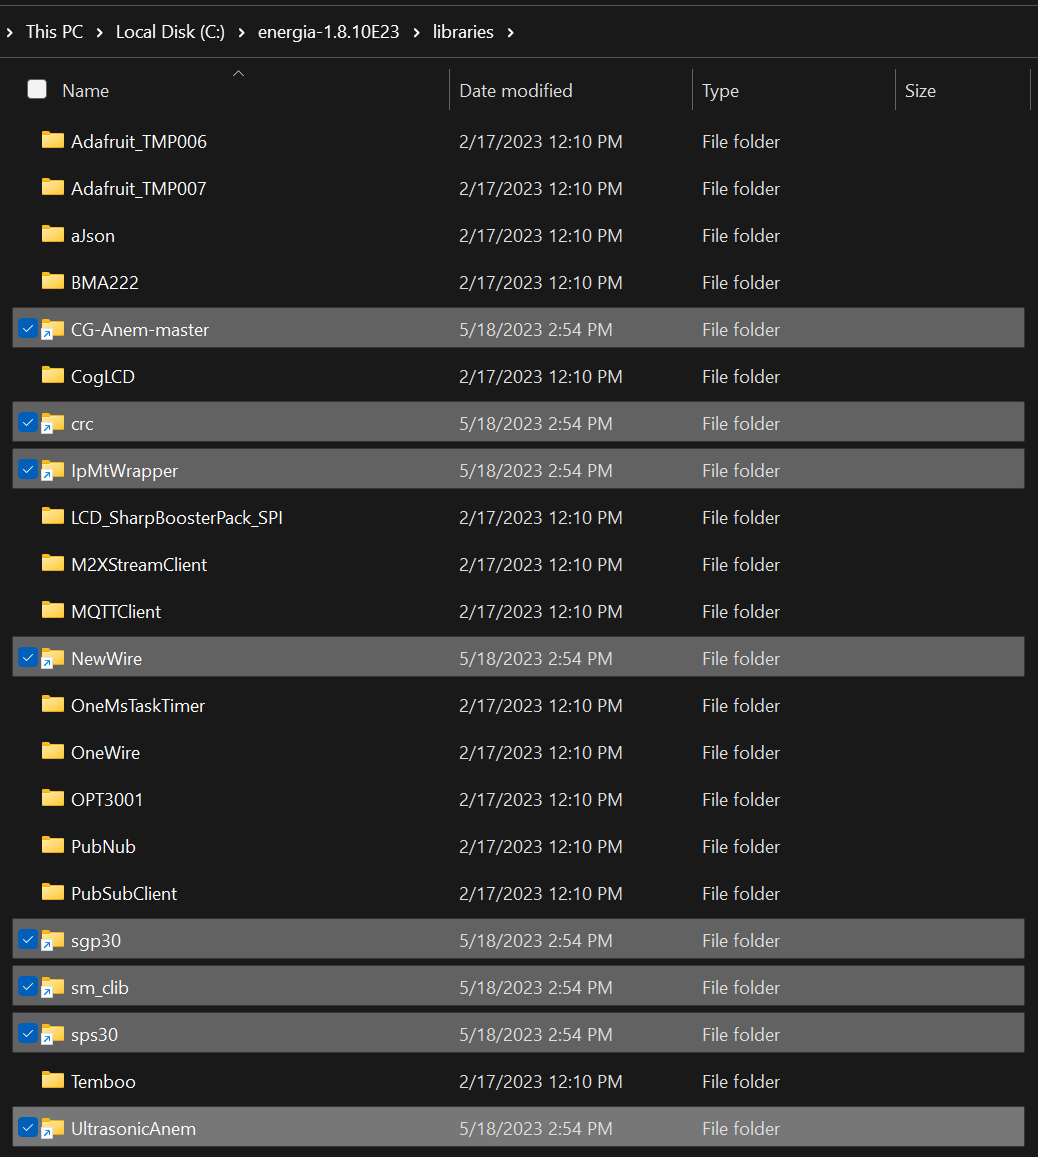
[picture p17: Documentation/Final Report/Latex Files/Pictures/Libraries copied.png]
    
    \caption[Libraries copied]{Libraries copied to \texttt{C:\textbackslash energia-1.8.10E23\textbackslash libraries} folder} 
    \label{fig:part1commrin}
\end{figure}

\item Launch Energia and make sure to select the "MSP-EXP430FR2355LP" in the board section under the Tools tab.

\begin{figure}[H]
    \centering
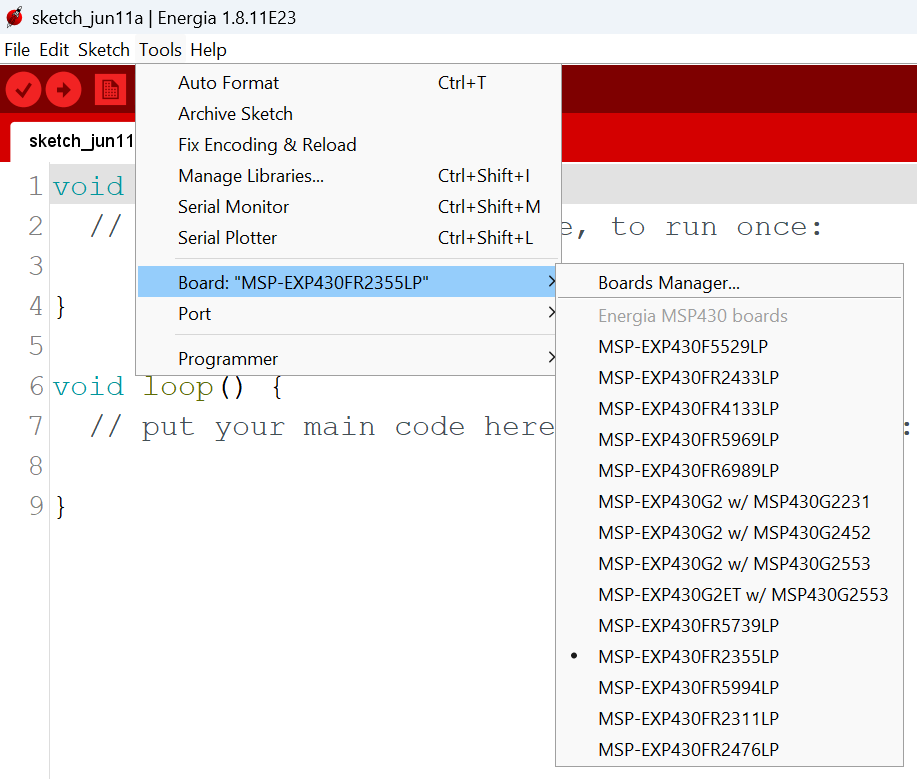
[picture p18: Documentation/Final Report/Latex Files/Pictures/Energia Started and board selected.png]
    
    \caption[MSP430FR2355 Selected]{MSP430FR2355 Selected} 
    \label{fig:part1commrin}
\end{figure}

\item Under File, press open, then navigate to the downloaded repository. Navigate to \texttt{Code/Sensor Mote/indoor\_air\_quality\_v2} and open \texttt{indoor\_air\_quality\_v2.ino}.
\item Click on the red checkmark to verify the code and make sure it compiles without errors.

\begin{figure}[H]
    \centering
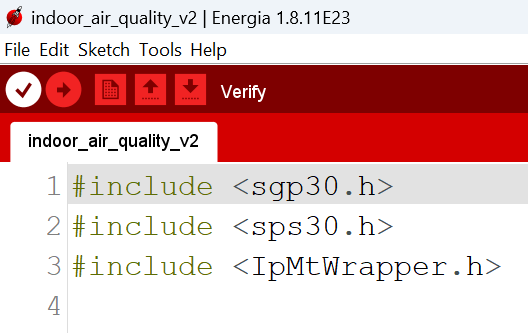
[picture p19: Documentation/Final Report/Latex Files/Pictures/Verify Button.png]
    
    \caption[Verify button]{Verify button} 
    \label{fig:part1commrin}
\end{figure}

\begin{figure}[H]
    \centering
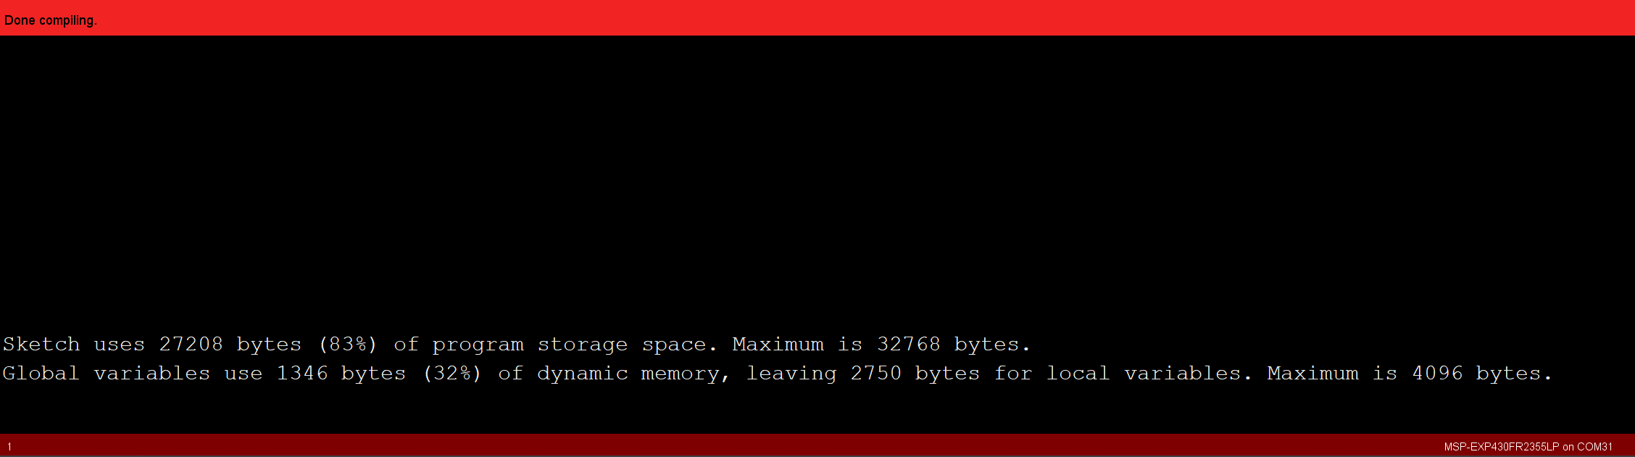
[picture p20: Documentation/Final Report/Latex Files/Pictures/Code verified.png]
    
    \caption[Code compiled]{Code compiled without errors} 
    \label{fig:part1commrin}
\end{figure}

\item Remove the lid of the sensor node.
\item Plug the other end of the USB cable plugged into the MSP430 into the computer.
\item Open Device Manager and check under the Ports drop-down for a device named "MSP Application UART 1" and take note of the COM port number associated with it.

\begin{figure}[H]
    \centering
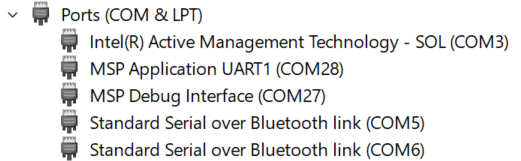
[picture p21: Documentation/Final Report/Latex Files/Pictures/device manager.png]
    
    \caption[MSP430 in device manager]{MSP430 in device manager} 
    \label{fig:part1commrin}
\end{figure}

\item In Energia, select the COM port from step 10 in the Port section under the Tools tab.

\begin{figure}[H]
    \centering
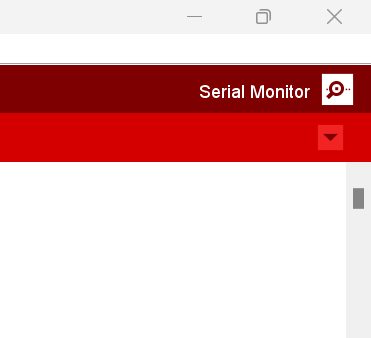
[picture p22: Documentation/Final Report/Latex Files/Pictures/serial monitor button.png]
    
    \caption[Serial monitor button]{Serial monitor button} 
    \label{fig:part1commrin}
\end{figure}

\item Open the Serial Monitor by clicking on the magnifying glass in the top-right corner. Have this visible to see debug output after programming the MSP430.
\item Click the red right arrow next to the checkmark to upload the code to the MSP430.

\begin{figure}[H]
    \centering
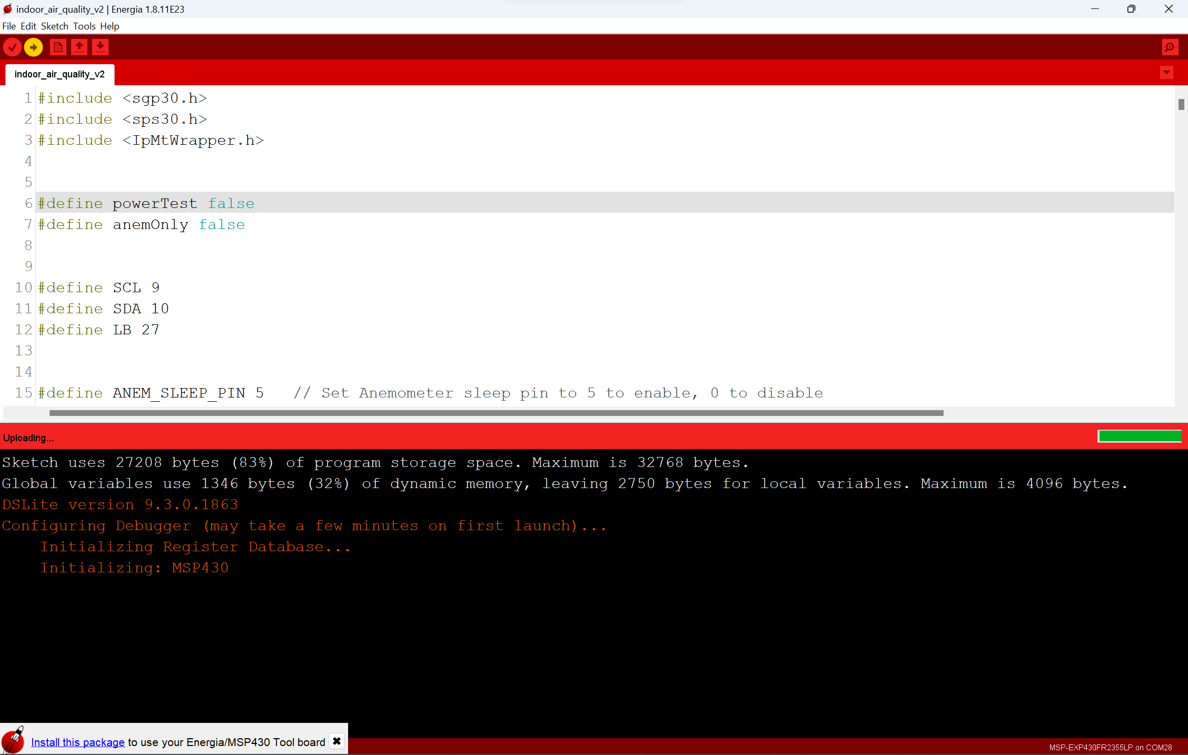
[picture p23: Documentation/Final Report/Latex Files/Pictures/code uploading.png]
    
    \caption[Code uploading to MSP430]{Code uploading to MSP430} 
    \label{fig:part1commrin}
\end{figure}

\item Watch the Serial Monitor. You should see messages related to the SmartMesh system connecting to the host node. Once it connects, you'll see each of the installed sensors take their first measurements and send them to the host node.
\item On the SensorDataReceiver.py terminal, verify that the first measurements from the sensors are received. It is now safe to unplug the USB cable from the computer, place it back in the sensor node, close the sensor node, and mount the node wherever you'd like to collect indoor air quality data.

\begin{figure}[H]
    \centering
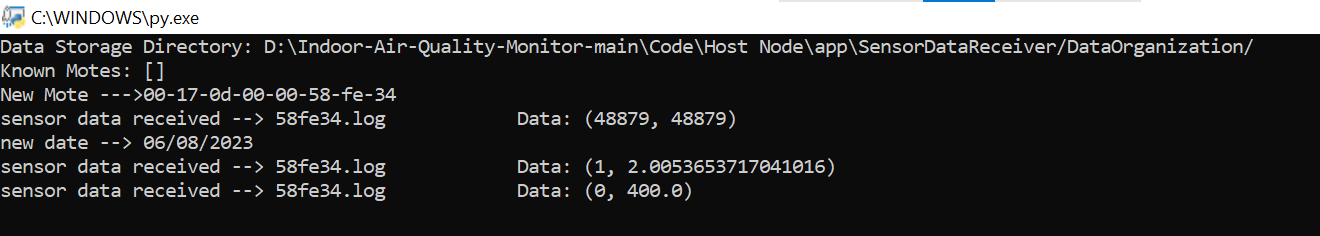
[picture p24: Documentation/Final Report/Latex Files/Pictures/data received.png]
    
    \caption[Data received by host node]{Data received by host node} 
    \label{fig:part1commrin}
\end{figure}

\item Repeat steps 7-14 for any additional sensor nodes.
\end{enumerate}

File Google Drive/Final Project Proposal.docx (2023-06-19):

Open Source Wireless Sensor System for Indoor Air Quality Monitoring

ECE 412 / 413

Sponsor: Dr David Burnett

Advisor: Dr John Acken

Team: Adam Dezay, Manuel Garcia, Brandon Hippe, Mercedes Newton

# Table of Contents

Table of Contents 1

1. Executive Summary 2

2. Background 2

3. Project Overview 2

4. Product Design Specification 3

4.1 Concept of Operation / User stories 3

4.2 Stakeholders 3

4.3 Requirements 4

4.4 Deliverables 5

4.5 Initial Product Design 5

4.6 Verification plans 8

5. Project Management Plan 9

5.1 Timeline, with milestones 9

5.2 Budget and Resources 10

5.3 Intellectual Property Discussion 10

5.4 Team and development process 11

6. Appendices 12

6.1 Configurations sorted by lowest power consumption / sampling rate 12

6.2 CO2 Sensor Comparisons 16

6.3 PM2.5 Sensor Comparisons 17

6.4 Airflow Sensor Comparisons 19

Proposal Outline and Discussion

## 1. Executive Summary

Air quality is very important for safe working conditions. There should be a monitoring system for environmental risks and air pollutants such as CO2 and fine particulate matter (PM2.5), as well as ventilation rates. This can be similar to smoke detectors. This team’s goal is to build a device to monitor elevated or dangerous quantities of these pollutants using as many commercial off-shelf components as possible. The aim is to create 3 to 10 wireless, battery powered initial prototypes that have at least one year life span.

## 2. Background

The team wants to make it easy to continuously monitor an indoor environment, and report data back to a host. The aim is to make it easy by making cheap, reliable devices that don't need recharging for a long time. Three features of indoor air are expected to be monitored: 2.5 μm particle count or PM2.5, carbon dioxide (CO2) concentration, and ventilation air speed.

Regarding CO2, statistically significant decrements occurred in cognitive performance

(decision making, problem resolution) starting at 1000 ppm[^1]. It is also a

good proxy for ventilation; high CO2 levels mean the room is poorly ventilated, which increases

the risk of passing airborne diseases such as COVID.

Regarding PM2.5, the WHO recommends an upper limit of 5 µg/m³ [^2](microgram per cubic

meter) average annually and 15 µg/m³ average over a 24 hour period .

An air speed sensor, or anemometer, can help us calculate how much air is flowing into or out of

a room and help understand why CO2 and/or PM2.5 is high.

The system will be based on components past capstone teams have successfully incorporated

such as the TI MSP430 (including super low-power sleep modes). In this iteration, a goal is to

replace the closed-source proprietary SmartMesh IP wireless system with the OpenWSN open-source wireless networking system.

This project is sponsored by the Wireless Environmental Sensor Technologies (WEST) Lab in the Electrical and Computer Engineering Department at Portland State, run by Dr. David Burnett. The project’s faculty advisor is Dr. John Acken.

## 3. Project Overview

From project description document:

Produce a fully wireless sensor data logger incorporating as many open-source components as

possible and able to be produced at a very low cost. A particular goal of this project is very low

power performance: sensors, communication system, and the microcontroller should be in as

low a power state as much as possible when not in use such that batteries need to be changed, at most, annually. (The lifetime of a smoke detector would be even better!)

Data should be temporarily logged locally and wirelessly communicated to base station(s) as appropriate. A stretch goal includes a visualization dashboard to present the logged data graphically for at-a-glance use. The device should be mechanically integrated into as small a

form-factor as is practical and contained in a robust housing appropriate for indoor

Environments.

The team anticipates the project consisting of two phases:

Phase 1: Select, implement, and assess performance of sensors. In particular this includes

energy consumption characterization, and investigation of whether sensors can be put into deep

sleep mode between use. If their deep sleep mode is deemed not low-power enough, the team will investigate whether they are tolerant to total power disconnect (via, e.g., MOSFET switches)

when not in use. In other words, does it save enough energy to totally disconnect the sensors?

Phase 2: Make it wireless. Incorporate sensor implementations into a complete system that

periodically wakes up, takes measurements, transmits them wirelessly, and goes back to sleep.

This phase will include overall system energy profiling to determine how much battery power will

be required for at least 1 year of operation.

## 4. Product Design Specification

### 4.1 Concept of Operation / User stories

For use, the user should be able to place many sensor systems throughout the environment they want to monitor. The systems should be able to automatically sense their surroundings and communicate their measurements between sensor systems and a central monitoring/data collection system. The sensor systems should be able to be set up and forgotten, requiring little maintenance such as battery charging, for ideally around a year.

### 4.2 Stakeholders

Industry Sponsor : Dr. David Burnett (Principal Investigator of WEST Lab at Portland State University)

Faculty Advisor: Dr. John Acken

Engineers:

- Adam Dezay
- Manuel Garcia
- Brandon Hippe
- Mercedes Newton

Customer: Any business in need of monitoring changing air quality conditions and their employees.

### 4.3 Requirements

The sensor system must:

- Sense PM2.5, CO2 often enough and accurately enough to ascertain indoor air quality relevant to occupants
- Include at least one node capable of sensing airspeed
- Maximize its battery life for sustained operation
- Locally store its measurement data
- Use as many commercial off-shelf components as possible
- Have an enclosure
- Wirelessly share its measurement data with a central monitoring system with communication range of at least 10 meters
- Utilize SmartMesh IP
- Have 3 iterations that cost no more than $1,000 total

The sensor system should:

- Include capability for any node to sense airspeed
- Have a battery life of at least 1 year
- Be open-source to the extent possible when using commercial off-the-shelf components
- Upgrade SmartMesh IP to Utilize a low-power Wireless Sensor Network (WSN) system like OpenWSN
- Utilize Texas Instruments MSP430/432 class microcontroller unit
- Have 10 iterations that cost no more than $3,000 total
- Utilize 18560 lithium ion battery cell/s

The sensor system may:

- Incorporate a single 18650 battery
- Monitor other environmental conditions such as temperature and humidity
- Include self-configuration capability to detect which sensors are connected and adjust sampling rates accordingly
- Be usable outdoors
- Include a visualization dashboard to monitor the data graphically
- Be able to incorporate many more (>10) sensor modules
- Match lifetime of a fire detector (~10 years)

### 4.4 Deliverables

- Complete documentation
  - Project proposal
  - Weekly Progress Reports
  - Final report
  - ECE Capstone Poster Session poster
- Summary project report in the style of an IEEE conference paper as linked to in the "Manuscript Template" section of this page: https://ieee-sensors.org/sensors-letters/
- Bill of materials
- System schematic & functional diagram
- Design files for any custom mechanical components or PCBs
- Source code
- Operation guide
- Demonstration hardware
- Three to ten sensor system prototypes

These deliverables will be shared via Canvas assignment portal if available, otherwise it will be shared with Sponsor and Advisor via email. A combination Google Drive folder and Github repository will also be maintained to have all of the aforementioned documentation.

### 4.5 Initial Product Design

There are a few other open source air quality monitoring systems that already exist, such as EnviroMonitor[^3] and AirGradient[^4]. Our system will be unique in that it is intended to be used as a network of sensor nodes each operating with long battery life.

Our design takes inspiration from smoke detectors. The goal is that each sensor node will be a small, self-contained unit that can be placed somewhere, set up, and then essentially forgotten. The team will design a custom PCB to handle connections between the MCU, sensors, and battery components inside of the node, and all the components will be housed in a custom designed 3d printable enclosure.

The hardware components will include:

- Texas Instruments MSP430/432 class microcontroller unit (MCU)
- 2.5 μm fine particulate matter (PM2.5) sensor
- CO2 sensor (Or equivalent CO2 sensor)
- Optional anemometer
- Custom PCB
- 18650 Lithium Ion Battery Cell(s)

Code for the nodes will be developed using Energia IDE/Code Composer Studio. For the host system, code will be based on the work of the 2022 Capstone team, who developed their host software in Python.

The L1 Block Diagram for the nodes and for the sensor network are as follows:


[Diagram: L1 Block Diagrams]

The team has done some initial research and estimations into power consumption versus sampling rate for each of the researched components. Below are three graphs showing this data, one for each type of sensor. The dotted red line on each graph represents the average power consumption of each sensor to obtain 1 year battery life on a single 18650 Lithium Ion battery cell.


The team has also completed some estimates about whole system battery life for potentially viable sensor configurations. Information on these configurations is available in section 6.1. The only sensors included in this summary are the ones that reach low enough power consumption at any point in the above graphs. Each sensor also has a different sampling rate, which is noted in the information. The configurations are sorted by lowest average power consumption per sampling rate (i.e., lower power consumption is better and sampling more frequently is better).

From these calculations, it should be feasible to reach 1 year battery life, given enough batteries and/or low enough sampling rates.

For the duration of the project, the team is going to be performing cost-benefit analysis on several aspects of our product to determine tradeoffs in battery life as compared to project quality. The first aspect that the team is weighing that has a major impact on our project's battery life is the system’s wake up rate to pull data from our sensors. The team plans on continuing to graph and analyze this data in order to find a comfortable balance. The second important tradeoff is power consumption with respect to the quality of our sensor, where some lower quality sensors project a better energy profile, but trade off accuracy or extra features. The team will be in constant communication with Professor Burnett in order to make sure any decisions made in these respects still align with our project's goals.

### 4.6 Verification plans

To test our project, the team is planning to run a 24-hour test run on our initial batch of 3-4 nodes, and then again later on our final batch. During these tests, which will take place during week 10 of spring quarter, the team hopes to see the data being collected, logged, and transmitted correctly. The team also will be monitoring the power consumption of each node using EnergyTrace. Testing for 24 hours should give us a good sanity check that our design should be able to run continuously for long periods of time, both from a maintenance and battery life standpoint. This test is planned to take place in the WEST Lab in FAB 60-24.

## 5. Project Management Plan

### 5.1 Timeline, with milestones


[Timelines of project - Winter]


[Timeline of Project - Spring]

Full Excel of Gantt Chart (https://github.com/brhttps://github.com/brandonhippe/412AirQualityCapstone/blob/main/Documentation/412_GanttChart.xlsxandonhippe/412AirQualityCapstone/blob/ma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)

### 5.2 Budget and Resources

To start, the budget for this project will be $1000 with the goal of building 3-4 prototype nodes. From there, The total estimate is a cost of $300 per node, with a goal of building 10 nodes for $3000.

The team will be utilizing several spaces on the Portland State University campus including but not limited to: the EPL (Electronics Prototyping Lab) for 3D printing and project assembly, Dr Burnett's research lab for meetings and project assembly, locker space in the Engineering building for project storage, and the third floor lobby of the Fariborz Maseeh Hall building for in person planning/documentation meetings. The team will also utilize Zoom for meetings with our industry sponsor and our faculty advisor. For communication platforms, the team will be using email to communicate with Dr Burnett and Dr Acken, and group communication will be completed via text messages, Discord, and Trello to ensure completion of projects. The team will also use Github as our version control system, with a group Google Drive to share other miscellaneous items.

### 5.3 Intellectual Property Discussion

This sensor system is intended to be open source. The design, including code, schematics, guides, and other necessary design files, will be protected under the GNU General Public License v3.0, and will be freely available on the project’s github repository.

### 5.4 Team and development process

Team Members and Skills/Project Interests:

- Adam Dezay: Documentation, Github, Wiki, Soldering, Gantt Chart, CO2 sensor prototyping.
- Manuel Garcia: KiCad Schematic & Board Layout, Programming, Web Development, General Hardware/Software Hacking, FreeCad, SmartMesh Prototyping
- Brandon Hippe: Coding, Sensor implementation, wireless networking implementation, 3D printing, GUI development in Python and MATLAB, Anemometer prototyping, point of contact with sponsor
- Mercedes Newton: Team captain, Weekly report leader, 3D printing, documentation, soldering, hardware implementation, power calculations, PM2.5 sensor prototyping, private consulting.

The team will be utilizing collaboration tools such as Trello, Github, Google Drive and Zoom. Our point person for communicating with our industry sponsor and advisor is Brandon Hippe, and our team leader is Mercedes Newton.

## 6. Appendices

### 6.1 Configurations sorted by lowest power consumption / sampling rate

1.

PM2.5 Sensors: Sensirion SPS30

Time On: 10 seconds

Time Off: 5990 seconds

Sleep Power %: 0.00%

Percent of Total Power: 30.74%

CO2 Sensors: Sensirion SGP30

Time On: 1 seconds

Time Off: 239 seconds

Sleep Power %: 0.98%

Percent of Total Power: 24.49%

Air Speed Sensors: Custom Ultrasonic Anemometer

Time On: 3 seconds

Time Off: 117 seconds

Sleep Power %: 0.00%

Percent of Total Power: 24.35%

Micro Controllers: MSP430

Time On: 157 seconds

Time Off: 5843 seconds

Sleep Power %: 3.39%

Percent of Total Power: 20.43%

Power Consumption: 1.491 mW

Cost: $81.32

Battery Life on single 18650 cell: 352.11 days

2.

PM2.5 Sensors: Sensirion SPS30

Time On: 10 seconds

Time Off: 5990 seconds

Sleep Power %: 0.00%

Percent of Total Power: 28.98%

CO2 Sensors: Sensirion SCD30

Time On: 2 seconds

Time Off: 298 seconds

Sleep Power %: 0.00%

Percent of Total Power: 26.43%

Air Speed Sensors: Custom Ultrasonic Anemometer

Time On: 3 seconds

Time Off: 117 seconds

Sleep Power %: 0.00%

Percent of Total Power: 22.95%

Micro Controllers: MSP430

Time On: 177 seconds

Time Off: 5823 seconds

Sleep Power %: 3.01%

Percent of Total Power: 21.63%

Power Consumption: 1.581 mW

Cost: $122.77

Battery Life on single 18650 cell: 331.99 days

3.

PM2.5 Sensors: Sensirion SPS30

Time On: 10 seconds

Time Off: 5990 seconds

Sleep Power %: 0.00%

Percent of Total Power: 28.49%

CO2 Sensors: Sensirion SCD40

Time On: 15 seconds

Time Off: 1785 seconds

Sleep Power %: 0.00%

Percent of Total Power: 25.64%

Air Speed Sensors: Custom Ultrasonic Anemometer

Time On: 3 seconds

Time Off: 117 seconds

Sleep Power %: 0.00%

Percent of Total Power: 22.56%

Micro Controllers: MSP430

Time On: 584 seconds

Time Off: 17416 seconds

Sleep Power %: 2.73%

Percent of Total Power: 23.32%

Power Consumption: 1.609 mW

Cost: $113.77

Battery Life on single 18650 cell: 326.30 days

4.

PM2.5 Sensors: Sensirion SPS30

Time On: 10 seconds

Time Off: 5990 seconds

Sleep Power %: 0.00%

Percent of Total Power: 32.90%

CO2 Sensors: Sensirion SGP30

Time On: 1 seconds

Time Off: 239 seconds

Sleep Power %: 0.98%

Percent of Total Power: 26.21%

Air Speed Sensors: Modern Device Wind Sensor Rev. C

Time On: 13 seconds

Time Off: 4187 seconds

Sleep Power %: 0.00%

Percent of Total Power: 33.33%

Micro Controllers: MSP430

Time On: 354 seconds

Time Off: 41646 seconds

Sleep Power %: 9.98%

Percent of Total Power: 7.56%

Power Consumption: 1.393 mW

Cost: $95.37

Battery Life on single 18650 cell: 376.88 days

5.

PM2.5 Sensors: Sensirion SPS30

Time On: 10 seconds

Time Off: 5990 seconds

Sleep Power %: 0.00%

Percent of Total Power: 28.20%

CO2 Sensors: Prana Air CO2 Sensor

Time On: 15 seconds

Time Off: 3285 seconds

Sleep Power %: 0.00%

Percent of Total Power: 27.97%

Air Speed Sensors: Custom Ultrasonic Anemometer

Time On: 3 seconds

Time Off: 117 seconds

Sleep Power %: 0.00%

Percent of Total Power: 22.34%

Micro Controllers: MSP430

Time On: 1990 seconds

Time Off: 64010 seconds

Sleep Power %: 2.94%

Percent of Total Power: 21.50%

Power Consumption: 1.625 mW

Cost: $82.82

Battery Life on single 18650 cell: 323.03 days

6.

PM2.5 Sensors: Sensirion SPS30

Time On: 10 seconds

Time Off: 5990 seconds

Sleep Power %: 0.00%

Percent of Total Power: 31.21%

CO2 Sensors: Sensirion SCD30

Time On: 2 seconds

Time Off: 298 seconds

Sleep Power %: 0.00%

Percent of Total Power: 28.47%

Air Speed Sensors: Modern Device Wind Sensor Rev. C

Time On: 13 seconds

Time Off: 4187 seconds

Sleep Power %: 0.00%

Percent of Total Power: 31.62%

Micro Controllers: MSP430

Time On: 438 seconds

Time Off: 41562 seconds

Sleep Power %: 8.20%

Percent of Total Power: 8.70%

Power Consumption: 1.468 mW

Cost: $136.82

Battery Life on single 18650 cell: 357.54 days

7.

PM2.5 Sensors: Sensirion SPS30

Time On: 10 seconds

Time Off: 5990 seconds

Sleep Power %: 0.00%

Percent of Total Power: 31.11%

CO2 Sensors: Sensirion SCD40

Time On: 15 seconds

Time Off: 1785 seconds

Sleep Power %: 0.00%

Percent of Total Power: 28.00%

Air Speed Sensors: Modern Device Wind Sensor Rev. C

Time On: 13 seconds

Time Off: 4187 seconds

Sleep Power %: 0.00%

Percent of Total Power: 31.51%

Micro Controllers: MSP430

Time On: 1430 seconds

Time Off: 124570 seconds

Sleep Power %: 7.58%

Percent of Total Power: 9.37%

Power Consumption: 1.473 mW

Cost: $127.82

Battery Life on single 18650 cell: 356.36 days

8.

PM2.5 Sensors: Sensirion SPS30

Time On: 10 seconds

Time Off: 5990 seconds

Sleep Power %: 0.00%

Percent of Total Power: 30.86%

CO2 Sensors: Prana Air CO2 Sensor

Time On: 15 seconds

Time Off: 3285 seconds

Sleep Power %: 0.00%

Percent of Total Power: 30.61%

Air Speed Sensors: Modern Device Wind Sensor Rev. C

Time On: 13 seconds

Time Off: 4187 seconds

Sleep Power %: 0.00%

Percent of Total Power: 31.26%

Micro Controllers: MSP430

Time On: 4000 seconds

Time Off: 458000 seconds

Sleep Power %: 9.73%

Percent of Total Power: 7.26%

Power Consumption: 1.485 mW

Cost: $96.87

Battery Life on single 18650 cell: 353.53 days

### 6.2 CO2 Sensor Comparisons

| SGP 30 (https://www.adafruit.com/product/3709) | SCD 30 (https://www.adafruit.com/product/4867)
Type | E CO2 | CO2
Additional sensors | VOC | - Temp - Humidity
Range | 400-60k PPM | 0-40k PPM
Accuracy | ±15% | ±30PPM +3%
Power Consumption (On) | ~86 mW | ~63 mW
Power Consumption (Off) | ~3.6 μW | ~20 mW (likely requires full shutoff)
Price ($) | 17.50 | 58.95
Relative Size | Size of quarter | Double size

Average outdoor PPM is 414 PPM

Cities have PPM between 600-900

OSHA permits up to 5K PPM per 8 hour exposure

40K PPM is where it gets to the deadly range

ANSI recommends below 700 PPM outdoor and 1200 PPM Indoor

Sources:

USDA (https://www.fsis.usda.gov/sites/default/files/media_file/2020-08/Carbon-Dioxide.pdf)

SGP30 Overview/datasheet/tutorial...etc (https://learn.adafruit.com/adafruit-sgp30-gas-tvoc-eco2-mox-sensor/overview)

SCD 30 Overview/datasheet/tutorial...etc (https://learn.adafruit.com/adafruit-scd30)

### 6.3 PM2.5 Sensor Comparisons

| PMS5003 (https://shop.pimoroni.com/products/pms5003-particulate-matter-sensor-with-cable?variant=29075640352851) | PAS-OUT-01 (https://www.pranaair.com/us/air-quality-sensor/outdoor-pm-sensor/) | PAS-IN-01 (https://www.pranaair.com/air-quality-sensor/indoor-pm-sensor/) | SPS30 (https://sensirion.com/products/catalog/SPS30/)
Range (concentration) | 0-500 ug/m³ | 0-31000 ug/m³ | 0-1500 ug/m³ | 0-1000 ug/m³
Accuracy | ±10% or ±10 ug/m³, whichever is greater | ±10% or ±10 ug/m³, whichever is greater | ±1ug/m³, | ±10% or ±10 ug/m³, whichever is greater
Power Consumption (On) | ~500 mW | ~350 mW | ~350mW | ~275 mW
Power Consumption (Off) | ~1 mW (likely requires full shutoff) | 0 mW (no sleep mode, full shut off) | 0 mW (no sleep mode, full shut off) | ~0.2 mW
Price ($) | 39.95 | Request Quote, student discount | Request Quote, student discount | 49.53
Notes | 30 seconds before accurate data, needs calibration every 30 days | 30 seconds before accurate data | 15 seconds before accurate data, | 10 seconds before accurate data

### 6.4 Airflow Sensor Comparisons

| Custom Ultrasonic Anemometer (https://hackaday.com/2013/08/21/ultrasonic-anemometer-for-an-absurdly-accurate-weather-station/) | Wind Sensor Rev. C (https://moderndevice.com/products/wind-sensor)
Type | Ultrasonic | Hotwire
Range | Unknown and depends on size (will build and test) | 0-60 MPH
Accuracy | Unknown and depends on size (will build and test) | Can detect “small puff of air at a distance of 18-24 inches”
Power Consumption (On) | ~14.52 mW | ~150 mW
Power Consumption (Off) | 0 mW (no sleep mode, full shut off)
Price ($) | 7.90 | 21.95
Relative Size | ~25-36 cm apart | .68″ × 1.590″ × .25″
Notes | Requires custom design | 10 second warm-up time

[^1] https://www.co2meter.com/blogs/news/co2-levels-at-home
[^2] https://apps.who.int/iris/bitstream/handle/10665/345329/9789240034228-eng.pdf
[^3] https://www.davisinstruments.com/pages/airlink
[^4] https://www.airgradient.com/

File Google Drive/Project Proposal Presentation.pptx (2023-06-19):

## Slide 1

Open Source Air Quality Monitor Proposal

Adam Dezay, Manny Garcia, Brandon Hippe, and Mercedes Newton

Portland State University Logo

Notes: Adam

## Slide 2

Executive Summary

Executive Summary

We aim to build a device to monitor elevated or dangerous qualities of pollutants such as PM 2.5 and CO2 as well as measuring airspeed using as many open source components as possible. We aim to create 10 wireless, battery powered initial prototypes with at least 1 year of life span.

‹#›

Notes: Adam

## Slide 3

Background

Background

What we’re monitoring

CO2 | Fine Particulate Matter (PM2.5) | Airflow


- The WHO recommends an upper limit of 5 ug/m3 (microgram per cubic meter) average annually and 15 ug/m3 average over a 24 hour period[1] .
- OSHA permits up to 5K PPM per 8 hour exposure with 400-600 being average CO2 [2]
sources
[1]https://www.epa.gov/criteria-air-pollutants/naaqs-table
[2]https://www.fsis.usda.gov/sites/default/files/media_file/2020-08/Carbon-Dioxide.pdf

‹#›

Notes: Adam

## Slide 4

Background

Background

The System

- Based on last year’s capstone project
- Upgrade to OpenWSN wireless system
- Measure CO2 and PM2.5 instead of N2O
- Better Battery life
- 10 working nodes


‹#›

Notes: Adam
The system will be based on components past capstone teams have successfully incorporated such as the TI MSP430 (including super low-power sleep modes).
In this iteration, we will aim to replace the closed-source proprietary SmartMesh IP wireless system with the OpenWSN open-source wireless networking system.

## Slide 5

Section Title / Topic

Project Overview

- Produce a wireless, within budget, and long life project
- A particular goal of this project is very low power performance
- Data should be temporarily logged locally and wirelessly communicated to base station(s) as appropriate.
- A stretch goal includes a visualization dashboard to present the logged data graphically for at-a-glance use.
- The device should be mechanically integrated into as small a form-factor as is practical and contained in a robust housing appropriate for indoor environments.

‹#›

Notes: Adam

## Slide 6

Section Title / Topic

Project Overview

Phase 1

- Select, Implement, and assess performance of sensors
- Particular focuses include power consumption, cost and accuracy

Phase 2

- Make it Wireless
- Incorporate into system that wakes up, takes measurement , transmit wirelessly, then go back to sleep

‹#›

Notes: Mercedes

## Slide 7

Section Title / Topic

Timeline

Winter and Spring Term Project Timelines


‹#›

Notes: Mercedes

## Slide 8

Section Title / Topic

Product Design Specification

Stakeholders

- Industry Sponsor : Dr. David Burnett (Principle Investigator of WEST Lab at Portland State University)
- Faculty Advisor: Dr. John Acken
- Engineers:
  - Adam Dezay
  - Manuel Garcia
  - Brandon Hippe
  - Mercedes Newton
- Customer: Any business in need of monitoring changing air quality conditions and their employees.

‹#›

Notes: Mercedes

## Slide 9

Section Title / Topic

Requirements

Must
- Sense PM2.5, CO2
- Maximize its battery life for sustained operation
- Locally store its measurement data
- Use as many open-source components as possible
Should
- Sense airspeed and direction
- Have a battery life of at least 1 year
- Wirelessly share its measurement data with other sensor systems and central monitoring system
- Be entirely open-source
- Must have an enclosure
May
- Monitor other environmental conditions
- Be usable outdoors
- Include a visualization dashboard to monitor the data graphically

‹#›

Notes: Mercedes

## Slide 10

Section Title / Topic

Specifications

- The sensor system must:
  - Have 3 iterations that cost no more than $1,000 total
- The sensor system should:
  - Have 10 iterations that cost no more than $3,000 total
  - Utilize 18560 lithium ion battery cell/s
  - Utilize Texas Instruments MSP430/432 class microcontroller unit
  - Utilize Smart mesh
  - Utilize Wireless Sensor Network (WSN)
- The sensor may:
  - Be able to incorporate many more (>10) sensor modules
  - Match lifetime of a fire detector (~10 years)

‹#›

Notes: Mercedes

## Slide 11

Section Title / Topic

Deliverables

- Complete documentation
- Project proposal
- Weekly Progress Reports
- Final report
- ECE Capstone Poster Session poster
- Summary project report in the style of an academic paper
- Bill of materials
- System schematic & functional diagram
- Design files for any custom mechanical components or PCBs
- Source code
- Operation guide
- Demonstration hardware
- 10 sensor system prototypes

‹#›

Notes: Brandon

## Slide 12

Section Title / Topic

Initial Product Design

Our design takes inspiration from smoke detectors. The goal is that each sensor node will be a small, self-contained unit that can be placed somewhere, set up, and then essentially forgotten. We will design a custom PCB to handle connections between the MCU, sensors, and battery components inside of the node, and all the components will be housed in a custom designed 3d printable enclosure.
The hardware components will include:
- Texas Instruments MSP430/432 class microcontroller unit (MCU)
- 2.5 μm fine particulate matter (PM 2.5) sensor
- CO2 sensor (or equivalent CO2 sensor)
- Optional anemometer
- Smartmesh networking
- Custom PCB
- 18650 Lithium Ion Battery Cell(s)
Code for the nodes will be developed using Energia IDE/Code Composer Studio. For the host system, we plan to base our code on the work of the 2022 Capstone team, who developed their host software in Python.

‹#›

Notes: Brandon

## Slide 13

Section Title / Topic

L1 Diagram

Node Diagram and Mesh Network Diagram


‹#›

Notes: Brandon

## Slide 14

Section Title / Topic


Sensor Choices

Sensor Power Consumption vs Sampling Rate

We have conducted initial research for each of the different sensors to be incorporated into this device. Taking into consideration active and sleep mode power consumption, the graphs to the right show average power consumption vs sampling rate for each of the sensors under consideration. The red line represents the average power consumption of each sensor necessary to achieve 1 year battery life on a single 18650 cell. Only the sensors that reach this benchmark will be considered for this project.

‹#›

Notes: Brandon

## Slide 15

Section Title / Topic

Sensor Choices (CO2)

| SGP 30 (https://www.adafruit.com/product/3709) | SCD 30 (https://www.adafruit.com/product/4867)
Type | E CO2 | CO2
Additional sensors | VOC | Temp Humidity
Range | 400-60k PPM | 0-40k PPM
Accuracy | ±15% | ±30PPM +3%
Power Consumption (On) | ~86 mW | ~63 mW
Price ($) | 17.50 | 58.95
Relative Size | Size of quarter | Double size
Notes | Can be more accurate with Humidity sensor Uses H2 to get CO2 | 2-1800s sampling range

- Average outdoor PPM is 414 PPM
- Cities have PPM between 600-900
- OSHA permits up to 5K PPM per 8 hour exposure
- 40K PPM is where it gets to the deadly range
- ANSI recommends below 700 PPM outdoor and 1200 PPM Indoor
Sources:
USDA (https://www.fsis.usda.gov/sites/default/files/media_file/2020-08/Carbon-Dioxide.pdf)
SGP30 Overview/datasheet/tutorial...etc (https://learn.adafruit.com/adafruit-sgp30-gas-tvoc-eco2-mox-sensor/overview)
SCD 30 Overview/datasheet/tutorial...etc (https://learn.adafruit.com/adafruit-scd30)

‹#›

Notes: Adam

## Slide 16

Section Title / Topic

Sensor Choices (PM2.5)

| PMS5003 (https://shop.pimoroni.com/products/pms5003-particulate-matter-sensor-with-cable?variant=29075640352851) | PAS-OUT-01 (https://www.pranaair.com/us/air-quality-sensor/outdoor-pm-sensor/) | PAS-IN-01 (https://www.pranaair.com/air-quality-sensor/indoor-pm-sensor/) | SPS30 (https://sensirion.com/products/catalog/SPS30/)
Range (concentration) | 0-500 ug/m³ | 0-31000 ug/m³ | 0-1500 ug/m³ | 0-1000 ug/m³
Accuracy | ±10% or ±10 ug/m³, whichever is greater | ±10% or ±10 ug/m³, whichever is greater | ±1ug/m³, | ±10% or ±10 ug/m³, whichever is greater
Power Consumption (On) | ~500 mW | ~350 mW | ~350mW | ~275 mW
Price ($) | 39.95 | Request Quote, student discount | Request Quote, student discount | 49.53
Notes | 30 seconds before accurate data, needs calibration every 30 days | 30 seconds before accurate data | 15 seconds before accurate data, | 10 seconds before accurate data

‹#›

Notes: Mercedes

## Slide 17

Section Title / Topic


Sensor Choices (Airflow)

| Custom Ultrasonic Anemometer (https://hackaday.com/2013/08/21/ultrasonic-anemometer-for-an-absurdly-accurate-weather-station/) | Wind Sensor Rev. C (https://moderndevice.com/products/wind-sensor)
Type | Ultrasonic | Hotwire
Range | Unknown and depends on size (will build and test) | 0-60 MPH
Accuracy | Unknown and depends on size (will build and test) | Can detect “small puff of air at a distance of 18-24 inches”
Power Consumption (On) | ~14.52 mW | ~150 mW
Price ($) | 7.90 | 21.95
Relative Size | ~25-36 cm apart | .68″ × 1.590″ × .25″
Notes | Requires custom design | 10 second warm-up time


‹#›

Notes: Brandon

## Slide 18

Section Title / Topic

Budget and Resources

To start, the budget for this project will be $1000 with the goal of building 3-4 prototype nodes. From there, we’re estimating a cost of $300 per node, with a goal of building 10 nodes for $3000.
We will be utilizing several spaces on the Portland State University campus including but not limited to: the EPL (Electronics Prototyping Lab) for 3D printing and project assembly, Dr Burnett's research lab for meetings and project assembly, locker space in the Engineering building for project storage, and the third floor lobby of the Fariborz Maseeh Hall building for in person planning/documentation meetings. We will also utilize Zoom for meetings with our industry sponsor and our faculty advisor. For communication platforms, we will be using email to communicate with Dr Burnett and Dr Acken, and group communication will be completed via text messages, Discord, and Trello to ensure completion of projects. We will also use Github as our version control system, with a group Google Drive to share other miscellaneous items.

‹#›

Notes: man

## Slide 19

Section Title / Topic

Verification plans

To test our project, we’re planning to run a 24-hour test run on our initial batch of 3-4 nodes, and then again later on our final batch. During these tests, we hope to see the data being collected, logged, and transmitted correctly. We also will be monitoring the power consumption of each node using EnergyTrace. Testing for 24 hours should give us a good sanity check that our design should be able to run continuously for long periods of time, both from a maintenance and battery life standpoint. This test is planned to take place in the WEST Lab in FAB 60-24.

‹#›

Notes: man

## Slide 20

Section Title / Topic

Intellectual Property

This sensor system is intended to be open source. The design, including code, schematics, guides, and other necessary design files, will be protected under the GNU General Public License v3.0, and will be freely available on the project’s github repository.
The only intellectual property that we may end up using is the smartmesh wireless protocol, as well as their respective development boards. We do however plan on alleviating this issue by switching to OpenWSN which will make our whole project open source.

‹#›

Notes: man

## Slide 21

Section Title / Topic

Team & Development Process

Team Members and Skills/Project Interests:
- Adam Dezay: Documentation, Github, Wiki, Soldering, Gantt Chart.
- Manuel Garcia: KiCad Schematic & Board Layout, Programming, Web Development, General Hardware/Software Hacking, FreeCad
- Brandon Hippe: Coding, Sensor implementation, wireless networking implementation, 3D printing, GUI development in Python and MATLAB, point of contact with sponsor
- Mercedes Newton: Team captain, Weekly report leader, 3D printing, documentation, soldering, hardware implementation, power calculations, private consulting.
We will be utilizing collaboration tools such as Trello, Github, Google Drive and Zoom. Our point person for communicating with our industry sponsor and advisor is Brandon Hippe, and our team leader is Mercedes Newton.

‹#›

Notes: manuel

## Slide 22

Section Title / Topic

Questions we have

We are currently working on gathering more information in order to more concretely define some of the unknowns in our project. As of now our questions that we have are:
- Which programming environment will be the most user friendly and reproducible
- Specific sensors to use to enable long battery life & accurate sensing
- Enclosure design to enable accurate readings, as well as protection

‹#›

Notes: man

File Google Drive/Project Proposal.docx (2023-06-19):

Open Source Wireless Sensor System

ECE 412 / 413

Sponsor: Dr David Burnett

Advisor: Dr John Acken

Team: Adam Dezay, Manuel Garcia, Brandon Hippe, Mercedes Newton

# Table of Contents

Table of Contents 1

1. Executive Summary 2

2. Background 2

3. Project Overview 2

4. Product Design Specification 3

4.1 Concept of Operation / User stories 3

4.2 Stakeholders 3

4.3 Specifications 4

4.4 Requirements 4

4.5 Deliverables 4

4.6 Initial Product Design 5

4.7 Verification plans 9

5. Project Management Plan 10

5.1 Timeline, with milestones 10

5.2 Budget and Resources 11

5.3 Intellectual Property Discussion 12

5.4 Team and development process 12

6. Appendices 13

6.1 Configurations sorted by lowest power consumption / sampling rate 13

6.2 CO2 Sensor Comparisons 16

6.3 PM2.5 Sensor Comparisons 17

6.4 Airflow Sensor Comparisons 18

Proposal Outline and Discussion

## 1. Executive Summary

Air quality is very important for safe working conditions. Just like we use smoke detectors to monitor our environment for risks, we should be able to monitor other air pollutants, such as CO2 and fine particulate matter (PM 2.5), as well as airspeed and direction. Our goal is to build a device to monitor elevated or dangerous quantities of these pollutants using as many open-source components as possible. We aim to create 10 wireless, battery powered initial prototypes that have at least one year life span.

## 2. Background

We want to make it easy to continuously monitor an indoor environment, and report data back to a host. We can make it easy by making cheap, reliable devices that don't need recharging for a long time. Three features of indoor air are expected to be monitored: 2.5 μm particle count or PM2.5, carbon dioxide (CO2) concentration, and ventilation air speed.

Regarding CO2, Statistically significant decrements occurred in cognitive performance

(decision making, problem resolution) starting at 1000 ppm. It is also a

good proxy for ventilation; high CO2 levels mean the room is poorly ventilated, which increases

the risk of passing airborne diseases such as COVID.

Regarding PM2.5, the WHO recommends an upper limit of 5 ug/m3 (microgram per cubic

meter) average annually and 15 ug/m3 average over a 24 hour period .

An air speed sensor, or anemometer, can help us calculate how much air is flowing into or out of

a room and help understand why CO2 and/or PM2.5 is high.

The system will be based on components past capstone teams have successfully incorporated

such as the TI MSP430 (including super low-power sleep modes). In this iteration, we will aim to

replace the closed-source proprietary SmartMesh IP wireless system with the OpenWSN open-source wireless networking system.

This project is sponsored by the Wireless Environmental Sensor Technologies (WEST) Lab in the Electrical and Computer Engineering Department at Portland State, run by Dr. David Burnett. The project’s faculty advisor is Dr. John Acken.

## 3. Project Overview

From project description document:

Produce a fully wireless sensor data logger incorporating as many open-source components as

possible and able to be produced at a very low cost. A particular goal of this project is very low

power performance: sensors, communication system, and the microcontroller should be in as

low a power state as much as possible when not in use such that batteries need to be changed, at most, annually. (The lifetime of a smoke detector would be even better!)

Data should be temporarily logged locally and wirelessly communicated to base station(s) as appropriate. A stretch goal includes a visualization dashboard to present the logged data graphically for at-a-glance use. The device should be mechanically integrated into as small a

form-factor as is practical and contained in a robust housing appropriate for indoor

Environments.

We anticipate the project consisting of two phases:

Phase 1: Select, implement, and assess performance of sensors. In particular this includes

energy consumption characterization, and investigation of whether sensors can be put into deep

sleep mode between use. If their deep sleep mode is deemed not low-power enough, we will

investigate whether they are tolerant to total power disconnect (via, e.g., MOSFET switches)

when not in use. In other words, does it save enough energy to totally disconnect the sensors?

Phase 2: Make it wireless. Incorporate sensor implementations into a complete system that

periodically wakes up, takes measurements, transmits them wirelessly, and goes back to sleep.

This phase will include overall system energy profiling to determine how much battery power will

be required for at least 1 year of operation.

## 4. Product Design Specification

### 4.1 Concept of Operation / User stories

For use, the user should be able to place many sensor systems throughout the environment they want to monitor. The systems should be able to automatically sense their surroundings and communicate their measurements between sensor systems and a central monitoring/data collection system. The sensor systems should be able to be set up and forgotten, requiring little maintenance such as battery charging, for ideally around a year.

### 4.2 Stakeholders

Industry Sponsor : Dr. David Burnett (Principle Investigator of WEST Lab at Portland State University)

Faculty Advisor: Dr. John Acken

Engineers:

- Adam Dezay
- Manuel Garcia
- Brandon Hippe
- Mercedes Newton

Customer: Any business in need of monitoring changing air quality conditions and their employees.

### 4.3 Specifications

The sensor system must:

- Have 3 iterations that cost no more than $1,000 total

The sensor system should:

- Have 10 iterations that cost no more than $3,000 total
- Utilize 18560 lithium ion battery cell/s
- Utilize Texas Instruments MSP430/432 class microcontroller unit
- Utilize Smart mesh
- Utilize Wireless Sensor Network (WSN)

The sensor may:

- Be able to incorporate many more (>10) sensor modules
- Match lifetime of a fire detector (~10 years)

### 4.4 Requirements

The sensor system must:

- Sense PM2.5, CO2
- Maximize its battery life for sustained operation
- Locally store its measurement data
- Use as many open-source components as possible

The sensor system should:

- Sense airspeed and direction
- Have a battery life of at least 1 year
- Wirelessly share its measurement data with other sensor systems and central monitoring system
- Be entirely open-source
- Must have an enclosure

The sensor system may:

- Monitor other environmental conditions
- Be usable outdoors
- Include a visualization dashboard to monitor the data graphically

### 4.5 Deliverables

- Complete documentation
  - Project proposal
  - Weekly Progress Reports
  - Final report
  - ECE Capstone Poster Session poster
- Summary project report in the style of an academic paper
- Bill of materials
- System schematic & functional diagram
- Design files for any custom mechanical components or PCBs
- Source code
- Operation guide
- Demonstration hardware
- 10 sensor system prototypes

### 4.6 Initial Product Design

There are a few other open source air quality monitoring systems that already exist, such as EnviroMonitor and AirGradient. Our system will be unique in that it is intended to be used as a network of sensor nodes each operating with long battery life.

Our design takes inspiration from smoke detectors. The goal is that each sensor node will be a small, self-contained unit that can be placed somewhere, set up, and then essentially forgotten. We will design a custom PCB to handle connections between the MCU, sensors, and battery components inside of the node, and all the components will be housed in a custom designed 3d printable enclosure.

The hardware components will include:

- Texas Instruments MSP430/432 class microcontroller unit (MCU)
- 2.5 μm fine particulate matter (PM 2.5) sensor
- CO2 sensor (Or equivalent CO2 sensor)
- Optional anemometer
- Custom PCB
- 18650 Lithium Ion Battery Cell(s)

Code for the nodes will be developed using Energia IDE/Code Composer Studio. For the host system, we plan to base our code on the work of the 2022 Capstone team, who developed their host software in Python.

The L1 Block Diagram for the nodes and for the sensor network are as follows:


[Diagram: L1 Block Diagrams]

We have done some initial research and estimations into power consumption versus sampling rate for each of the components we have completed research on. Below are three graphs showing this data, one for each type of sensor. The dotted red line on each graph represents the average power consumption of each sensor to obtain 1 year battery life on a single 18650 Lithium Ion battery cell.


We have also completed some estimates about whole system battery life for potentially viable sensor configurations. Information on these configurations is available in section 6.1. The only sensors included in this summary are the ones that reach low enough power consumption at any point in the above graphs. Each sensor also has a different sampling rate, which is noted in the information. The configurations are sorted by lowest average power consumption per sampling rate (E.g lower power consumption is better and sampling more frequently is better)

From these calculations, it should be feasible to reach 1 year battery life, given enough batteries and/or low enough sampling rates.

For the duration of the project we are going to be performing cost-benefit analysis on several aspects of our product to determine tradeoffs in battery life as compared to project quality. The first aspect that we are weighing that has a major impact on our projects battery life is the rate at which we wake up our system and pull data from our sensors. We plan on continuing to graph and analyze this data in order to find a medium we are comfortable with. The second important tradeoff that we are looking into is power consumption in respect to the quality of our sensor, where some lower quality sensors project a better energy profile, but trade off accuracy or extra features. We will be in constant communication with Professor Burnett in order to make sure any decisions made in these respects still align with our project's goals.

### 4.7 Verification plans

To test our project, we’re planning to run a 24-hour test run on our initial batch of 3-4 nodes, and then again later on our final batch. During these tests, we hope to see the data being collected, logged, and transmitted correctly. We also will be monitoring the power consumption of each node using EnergyTrace. Testing for 24 hours should give us a good sanity check that our design should be able to run continuously for long periods of time, both from a maintenance and battery life standpoint. This test is planned to take place in the WEST Lab in FAB 60-24.

## 5. Project Management Plan

### 5.1 Timeline, with milestones


[Timelines of project - Winter]


[Timeline of Project - Spring]

Full Excel of Gantt Chart (https://github.com/brhttps://github.com/brandonhippe/412AirQualityCapstone/blob/main/Documentation/412_GanttChart.xlsxandonhippe/412AirQualityCapstone/blob/ma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)

### 5.2 Budget and Resources

To start, the budget for this project will be $1000 with the goal of building 3-4 prototype nodes. From there, we’re estimating a cost of $300 per node, with a goal of building 10 nodes for $3000.

We will be utilizing several spaces on the Portland State University campus including but not limited to: the EPL (Electronics Prototyping Lab) for 3D printing and project assembly, Dr Burnett's research lab for meetings and project assembly, locker space in the Engineering building for project storage, and the third floor lobby of the Fariborz Maseeh Hall building for in person planning/documentation meetings. We will also utilize Zoom for meetings with our industry sponsor and our faculty advisor. For communication platforms, we will be using email to communicate with Dr Burnett and Dr Acken, and group communication will be completed via text messages, Discord, and Trello to ensure completion of projects. We will also use Github as our version control system, with a group Google Drive to share other miscellaneous items.

### 5.3 Intellectual Property Discussion

This sensor system is intended to be open source. The design, including code, schematics, guides, and other necessary design files, will be protected under the GNU General Public License v3.0, and will be freely available on the project’s github repository.

### 5.4 Team and development process

Team Members and Skills/Project Interests:

- Adam Dezay: Documentation, Github, Wiki, Soldering, Gantt Chart.
- Manuel Garcia: KiCad Schematic & Board Layout, Programming, Web Development, General Hardware/Software Hacking, FreeCad
- Brandon Hippe: Coding, Sensor implementation, wireless networking implementation, 3D printing, GUI development in Python and MATLAB, point of contact with sponsor
- Mercedes Newton: Team captain, Weekly report leader, 3D printing, documentation, soldering, hardware implementation, power calculations, private consulting.

We will be utilizing collaboration tools such as Trello, Github, Google Drive and Zoom. Our point person for communicating with our industry sponsor and advisor is Brandon Hippe, and our team leader is Mercedes Newton.

## 6. Appendices

### 6.1 Configurations sorted by lowest power consumption / sampling rate

1.

PM2.5 Sensors: SPS30

Time On: 10.0 seconds

Time Off: 5990.0 seconds

Sleep Power %: 0.0 %

Percent of Total Power: 30.73968731061792 %

CO2 Sensors: SGP30

Time On: 1.0 seconds

Time Off: 239.0 seconds

Sleep Power %: 0.9819631044825213 %

Percent of Total Power: 24.485669982102426 %

Air Speed Sensors: Custom Ultrasonic Anemometer

Time On: 3.0 seconds

Time Off: 117.0 seconds

Sleep Power %: 0.0 %

Percent of Total Power: 24.345832350009392 %

Micro Controllers: MSP430

Time On: 157.0 seconds

Time Off: 5843.0 seconds

Sleep Power %: 3.386714080587953 %

Percent of Total Power: 20.42881035727026 %

Power Consumption: 0.0014910149498333334 watts

Cost: $81.32

Battery Life on single 18650 cell: 352.10914555798706 days

2.

PM2.5 Sensors: SPS30

Time On: 10.0 seconds

Time Off: 5990.0 seconds

Sleep Power %: 0.0 %

Percent of Total Power: 28.983076061947816 %

CO2 Sensors: SCD30

Time On: 2.0 seconds

Time Off: 298.0 seconds

Sleep Power %: 0.0 %

Percent of Total Power: 26.43256536849641 %

Air Speed Sensors: Custom Ultrasonic Anemometer

Time On: 3.0 seconds

Time Off: 117.0 seconds

Sleep Power %: 0.0 %

Percent of Total Power: 22.95459624106267 %

Micro Controllers: MSP430

Time On: 177.0 seconds

Time Off: 5823.0 seconds

Sleep Power %: 3.0055627374879723 %

Percent of Total Power: 21.629762328493097 %

Power Consumption: 0.0015813826398333336 watts

Cost: $122.77

Battery Life on single 18650 cell: 331.9879621641295 days

3.

PM2.5 Sensors: SPS30

Time On: 10.0 seconds

Time Off: 5990.0 seconds

Sleep Power %: 0.0 %

Percent of Total Power: 35.594227337736676 %

CO2 Sensors: SGP30

Time On: 1.0 seconds

Time Off: 239.0 seconds

Sleep Power %: 0.9819631044825213 %

Percent of Total Power: 28.35254942748567 %

Air Speed Sensors: Wind Sensor Rev. C

Time On: 3.0 seconds

Time Off: 1197.0 seconds

Sleep Power %: 0.0 %

Percent of Total Power: 29.122549639966373 %

Micro Controllers: MSP430

Time On: 42.0 seconds

Time Off: 5958.0 seconds

Sleep Power %: 11.78666394512847 %

Percent of Total Power: 6.930673594811294 %

Power Consumption: 0.0012876619823333332 watts

Cost: $95.37

Battery Life on single 18650 cell: 407.71569495952923 days

4.

PM2.5 Sensors: SPS30

Time On: 10.0 seconds

Time Off: 5990.0 seconds

Sleep Power %: 0.0 %

Percent of Total Power: 33.71825288123783 %

CO2 Sensors: SCD30

Time On: 2.0 seconds

Time Off: 298.0 seconds

Sleep Power %: 0.0 %

Percent of Total Power: 30.7510466276889 %

Air Speed Sensors: Wind Sensor Rev. C

Time On: 3.0 seconds

Time Off: 1197.0 seconds

Sleep Power %: 0.0 %

Percent of Total Power: 27.587661448285495 %

Micro Controllers: MSP430

Time On: 52.0 seconds

Time Off: 5948.0 seconds

Sleep Power %: 9.726029993110862 %

Percent of Total Power: 7.943039042787777 %

Power Consumption: 0.0013593033273333333 watts

Cost: $136.82

Battery Life on single 18650 cell: 386.22726027599697 days

5.

PM2.5 Sensors: SPS30

Time On: 10.0 seconds

Time Off: 5990.0 seconds

Sleep Power %: 0.0 %

Percent of Total Power: 28.486206436466095 %

CO2 Sensors: SCD40

Time On: 15.0 seconds

Time Off: 1785.0 seconds

Sleep Power %: 0.0 %

Percent of Total Power: 25.637585792819483 %

Air Speed Sensors: Custom Ultrasonic Anemometer

Time On: 3.0 seconds

Time Off: 117.0 seconds

Sleep Power %: 0.0 %

Percent of Total Power: 22.561075497681145 %

Micro Controllers: MSP430

Time On: 584.0 seconds

Time Off: 17416.0 seconds

Sleep Power %: 2.7321854445696663 %

Percent of Total Power: 23.315132273033278 %

Power Consumption: 0.0016089658493333332 watts

Cost: $113.77

Battery Life on single 18650 cell: 326.2965464540662 days

6.

PM2.5 Sensors: SPS30

Time On: 10.0 seconds

Time Off: 5990.0 seconds

Sleep Power %: 0.0 %

Percent of Total Power: 33.272272921131076 %

CO2 Sensors: SCD40

Time On: 15.0 seconds

Time Off: 1785.0 seconds

Sleep Power %: 0.0 %

Percent of Total Power: 29.94504562901796 %

Air Speed Sensors: Wind Sensor Rev. C

Time On: 3.0 seconds

Time Off: 1197.0 seconds

Sleep Power %: 0.0 %

Percent of Total Power: 27.222768753652694 %

Micro Controllers: MSP430

Time On: 194.0 seconds

Time Off: 17806.0 seconds

Sleep Power %: 7.957193813706362 %

Percent of Total Power: 9.559912696198278 %

Power Consumption: 0.001377523364333333 watts

Cost: $127.82

Battery Life on single 18650 cell: 381.1187625511377 days

### 6.2 CO2 Sensor Comparisons

| SGP 30 (https://www.adafruit.com/product/3709) | SCD 30 (https://www.adafruit.com/product/4867)
Type | E CO2 | CO2
Additional sensors | VOC | - Temp - Humidity
Range | 400-60k PPM | 0-40k PPM
Accuracy | ±15% | ±30PPM +3%
Power Consumption (On) | ~86 mW | ~63 mW
Price ($) | 17.50 | 58.95
Relative Size | Size of quarter | Double size

Average outdoor PPM is 414 PPM

Cities have PPM between 600-900

OSHA permits up to 5K PPM per 8 hour exposure

40K PPM is where it gets to the deadly range

ANSI recommends below 700 PPM outdoor and 1200 PPM Indoor

Sources:

USDA (https://www.fsis.usda.gov/sites/default/files/media_file/2020-08/Carbon-Dioxide.pdf)

SGP30 Overview/datasheet/tutorial...etc (https://learn.adafruit.com/adafruit-sgp30-gas-tvoc-eco2-mox-sensor/overview)

SCD 30 Overview/datasheet/tutorial...etc (https://learn.adafruit.com/adafruit-scd30)

### 6.3 PM2.5 Sensor Comparisons

| PMS5003 (https://shop.pimoroni.com/products/pms5003-particulate-matter-sensor-with-cable?variant=29075640352851) | PAS-OUT-01 (https://www.pranaair.com/us/air-quality-sensor/outdoor-pm-sensor/) | PAS-IN-01 (https://www.pranaair.com/air-quality-sensor/indoor-pm-sensor/) | SPS30 (https://sensirion.com/products/catalog/SPS30/)
Range (concentration) | 0-500 ug/m³ | 0-31000 ug/m³ | 0-1500 ug/m³ | 0-1000 ug/m³
Accuracy | ±10% or ±10 ug/m³, whichever is greater | ±10% or ±10 ug/m³, whichever is greater | ±1ug/m³, | ±10% or ±10 ug/m³, whichever is greater
Power Consumption (On) | ~500 mW | ~350 mW | ~350mW | ~275 mW
Price ($) | 39.95 | Request Quote, student discount | Request Quote, student discount | 49.53
Notes | 30 seconds before accurate data, needs calibration every 30 days | 30 seconds before accurate data | 15 seconds before accurate data, | 10 seconds before accurate data

### 6.4 Airflow Sensor Comparisons

| Custom Ultrasonic Anemometer (https://hackaday.com/2013/08/21/ultrasonic-anemometer-for-an-absurdly-accurate-weather-station/) | Wind Sensor Rev. C (https://moderndevice.com/products/wind-sensor)
Type | Ultrasonic | Hotwire
Range | Unknown and depends on size (will build and test) | 0-60 MPH
Accuracy | Unknown and depends on size (will build and test) | Can detect “small puff of air at a distance of 18-24 inches”
Power Consumption (On) | ~14.52 mW | ~150 mW
Price ($) | 7.90 | 21.95
Relative Size | ~25-36 cm apart | .68″ × 1.590″ × .25″
Notes | Requires custom design | 10 second warm-up time

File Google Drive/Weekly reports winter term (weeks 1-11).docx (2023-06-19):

The following represents the 11 weekly reports we, Team 1, have submitted to our Industry Sponsor and Academic Advisor. The reports below are presented in the original form with the respective week and date bolded for easy viewing.

Team 1 Open Source Air Quality Monitoring

Week 1: January 2nd 2022 - January 9th 2022

Sponsor: Dr David Burnett

Advisor: Dr John Acken

Team Members: Adam Dezay, Manuel Garcia, Brandon Hippe, Mercedes Newton

Team Review:

- Team established meeting times.
  - Team will meet with John Acken every Monday at 4:30.
  - Team will meet independently every Tuesday at 6:35.
- Team scheduled a meeting for Monday January 16th with Dr. Burnett to discuss questions and project proposals.
- Team established a shared drive, github and trello for record keeping and collaboration.
- Team curated questions and discussed our project proposal in preparation for our first meeting with Dr. Burnett. Questions listed below:
  - What percent accuracy do we require for our CO2 sensor?
  - Should we use Eco2 to estimate CO2 or a Real CO2 sensor?
  - Can we use the other microcontroller or should we use MSP430?
- Team conducted initial research and began brainstorming potential solutions.

Individual Review

Adam Dezay: Agreed to create wiki for team Github.

Brandon Hippe: Began python script for component power consumption estimations.

Manuel Garcia: Conducted initial research and began weighting benefits of specific components.

Mercedes Newton: Curated team Report.

Team 1 Open Source Air Quality Monitoring

Week 2: January 10th 2022 - January 17th 2022

Sponsor: Dr David Burnett

Advisor: Dr John Acken

Team Members: Adam Dezay, Manuel Garcia, Brandon Hippe, Mercedes Newton

Team Review:

- Team further curated questions and discussed our project proposal in preparation for our first meeting with Dr. Burnett. Questions listed below:
  - Size constraints? (Will affect battery life)
  - Sensor accuracy requirements, Eco2 vs Real CO2?
    - Our current constraints are that the Ec02 sensors we have looked into require extensive autocalibration and would have too long of start ups for a low power application.
  - Anemometer implementation?
    - Indoor applications will have low air speed so traditional anemometers might not make sense unless we placed it in an air duct.
  - Micro controller requirements?
    - We are currently looking at the esp32 because it has built in wifi and a deep sleep.
  - Web server preferences?
    - Current thoughts are to use a raspberry pi, running a web server, that we are able to access remotely.
  - Should we use open WSN and if so what microcontroller should be implemented?
    - Our team would prefer not to.
  - What is our budget? What will be provided by our sponsor?
    - We will require a maximum of $300 to create 1 unit, factoring varying prices and component requirements.
- Team conducted research and began brainstorming potential solutions.
- Team discussed power consumption in components
- Team developed rough draft of project proposal
- Team delegated tasks for the current week with emphasis on the project proposal and research, specific tasks are listed below.

Individual Review

Adam Dezay: Developing project Gantt chart, documented project in the project proposal

Manuel Garcia: Conducted initial research and began weighting benefits of specific components, assisted in documenting projects in the project proposal.

Brandon Hippe: Further developed python script for component power consumption estimations, sensor research, assisted in documenting project in the project proposal

Mercedes Newton: Curated team Report, further documented project in the project proposal

Team 1 Open Source Air Quality Monitoring

Week 3: January 16th 2022 - January 23th 2022

Sponsor: Dr David Burnett

Advisor: Dr John Acken

Team Members: Adam Dezay, Manuel Garcia, Brandon Hippe, Mercedes Newton

Team Review:

This week, we met with Dr. Burnett for the first time

- After our first class meeting and meeting with our industry advisor, our team has come to the following decisions
  - We must produce 3 prototypes, with a chance of producing the initially requested 10 due to funding.
  - We shall further research and discuss how frequently our sensors take in data as informed by power requirements.
  - Spreadsheet and protocol was established for obtaining equipment from both Dr. Burnett’s lab and the EPL.
  - Team established another meeting time and workshop time.
  - Team assigned Brandon as point person and Mercedes as leader.
  - Team created a discord for communication.
- Gantt chart was revised to be more informative.
- Using a CO2 vs ECO2 sensor is still being debated.
- Team assigned each member with a sensor to specialize in.
- Team finished rough draft of project proposal
- Team delegated tasks for the current week with emphasis on the research and planning.

Individual Review

Adam Dezay: Created and revised gantt chart during team meeting, began CO2 sensor research

Manuel Garcia: Continued Smart mesh and kicad research

Brandon Hippe: Finished python component power analysis script. Graphs and text outputs are available on github. Started basic tests on viability of custom ultrasonic anemometer, will continue and develop final anemometer pending results.

Mercedes Newton: Reached out to faculty about HVAC system used at PSU, began PM sensor research. Organized team trello/documentation.

Team 1 Open Source Air Quality Monitoring

Week 4: January 23rd 2022 - January 30th 2022

Sponsor: Dr. David Burnett

Advisor: Dr. John Acken

Team Members: Adam Dezay, Manuel Garcia, Brandon Hippe, Mercedes Newton

Team Review:

- Team submitted project proposal draft to Dr. Acken.
- Team reviewed rough draft of the project proposal and made adjustments according to the feedback from Dr. Acken.
- Team submitted rough draft of project proposal to Andrew Greenberg before our final review.
- Team received feedback from Dr. Elliott Gall in regards to HVAC systems in PSU.
- Team delegated tasks for the current week with emphasis on the research.
- Continued HVAC research and discussed the possibility of scheduling a tour with engineering building facilities, this will be a topic during our 4:30 meeting with Dr. Acken.
- Checked with EPL for parts availability, found sensors not available. How should we go about purchasing sensors? We’re currently building spreadsheet(s) with our necessary components, would we be able to send that information to Dr. Burnett for him to order?

Individual Review

Adam Dezay: Continued CO2 sensor research.

Manuel Garcia: Continued Smart mesh and kicad research.

Brandon Hippe: Started basic tests on viability of custom ultrasonic anemometer. Continues to develop final anemometer pending results.

Mercedes Newton: Reached out to faculty about HVAC system used at PSU, continued PM sensor research. Organized team trello/documentation.

Team 1 Open Source Air Quality Monitoring

Week 5: January 31st 2022 - February 6th 2022

Sponsor: Dr. David Burnett

Advisor: Dr. John Acken

Team Members: Adam Dezay, Manuel Garcia, Brandon Hippe, Mercedes Newton

Team Review:

- Team submitted project proposal to Dr. Burnett.
- Team prepared project proposal presentation for Dr. Acken.
- Team continued prototype sensor/smartmesh development.
- Checked part availability in the EPL.

Individual Review

Adam Dezay: Continued CO2 sensor research. Worked on presentation.

Manuel Garcia: Continued Smart mesh and kicad research. Worked on presentation.

Brandon Hippe: Continued ultrasonic anemometer research and design. Worked on presentation.

Mercedes Newton: Continued PM sensor research. Organized team trello/documentation. Worked on presentation.

Team 1 Open Source Air Quality Monitoring

Week 6: February 6th 2022 - February 13th 2022

Sponsor: Dr. David Burnett

Advisor: Dr. John Acken

Team Members: Adam Dezay, Manuel Garcia, Brandon Hippe, Mercedes Newton

Team Review:

- Conducted first team check in with professor Greenberg.
- Further solidified sensor choices, aim to order sensors during Monday meeting.
- Looked into alternate microcontrollers that would fit our application better.
- Worked on getting example code working on our MSP 430s
- Working towards getting list of components ready to purchase
- Making final tweaks to project proposal before submission by Friday noon

Questions for moving forward

- Can we get the template for submitting order requests so we can order components soon?
- Is there any chance of using the STM32 L series chip?
- When is our next meeting with Dr. Burnett?

Individual Review

Adam Dezay: Continued CO2 sensor research. Updated wiki

Manuel Garcia: Continued Smart mesh and kicad research, worked on initial MSP430/ Energia / Code Composer Studio setup, Researched other microcontrollers that may fit our application better

Brandon Hippe: Continued to develop final anemometer pending results.

Mercedes Newton: Continued PM sensor research. Organized team trello/documentation.

Team 1 Open Source Air Quality Monitoring

Week 7: February 13th 2022 - February 20th 2022

Sponsor: Dr. David Burnett

Advisor: Dr. John Acken

Team Members: Adam Dezay, Manuel Garcia, Brandon Hippe, Mercedes Newton

Team Review:

- Conducted first in person team check in with Dr. Burnett.
- Solidified sensor choices.
- Worked on getting example code working on our MSP 430.
- Achieved working MSP 430/energia on ¾ team member computers.
- Created a list of components ready to purchase.
- Making final tweaks to the project proposal before submission by Monday the 20th.

Individual Review

Adam Dezay: Continued CO2 sensor research, decided on SGP30, worked on final project proposal, updated Wiki, Started on CO2 code, Updated final proposal.

Manuel Garcia: Continued Smart mesh and kicad research, worked on initial MSP430/ Energia / Code Composer Studio setup, assisted teammates with MSP 430.

Brandon Hippe: Continued to develop final anemometer pending results, organized ordering spreadsheet, updated proposal, assisted teammates with MSP 430.

Mercedes Newton: Continued PM sensor research, decided on SPS30. Organized team trello/documentation.

Team 1 Open Source Air Quality Monitoring

Week 8: February 20th 2022 - February 27th 2022

Sponsor: Dr. David Burnett

Advisor: Dr. John Acken

Team Members: Adam Dezay, Manuel Garcia, Brandon Hippe, Mercedes Newton

Team Review:

- Worked on getting example code working on our MSP 430.
- Achieved working MSP 430/energia on ¾ team member computers.
- Enhanced gantt chart
- Submitted final project proposal
- Began parts ordering process
- Discussed potential of moving team meetings to better accommodate schedules.
- Canceled in person friday meeting due to ice and snow
- Waiting on order to arrive

Individual Review

Adam Dezay: Continued CO2 sensor research, decided on SGP30, worked on final project proposal, updated Wiki, Started on CO2 code, Updated final proposal.

Manuel Garcia: Continued Smart mesh and kicad research, worked on initial MSP430/ Energia / Code Composer Studio setup, assisted teammates with MSP 430.

Brandon Hippe: Continued to develop final anemometer pending results, organized ordering spreadsheet, updated proposal, assisted teammates with MSP 430.

Mercedes Newton: Continued PM sensor research, decided on SPS30. Organized team trello/documentation.

Team 1 Open Source Air Quality Monitoring

Week 9: February 28th 2022 - March 6th 2022

Sponsor: Dr. David Burnett

Advisor: Dr. John Acken

Team Members: Adam Dezay, Manuel Garcia, Brandon Hippe, Mercedes Newton

Team Review:

- All 4 members have access to Energia
- Ordered and received all sensors
- Began working individually on sensors/components
  - Adam - CO2
  - Manuel - SmartMesh
  - Brandon - Anemometer
  - Mercedes - PM

Upcoming week:
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

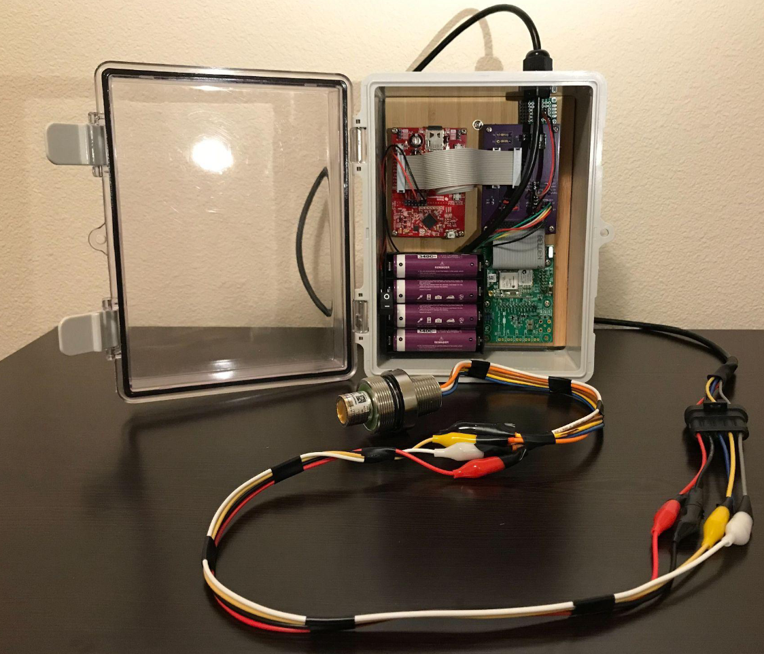
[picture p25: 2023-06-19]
Documentation/Final Report/Latex Files/Pictures/prevproj.png

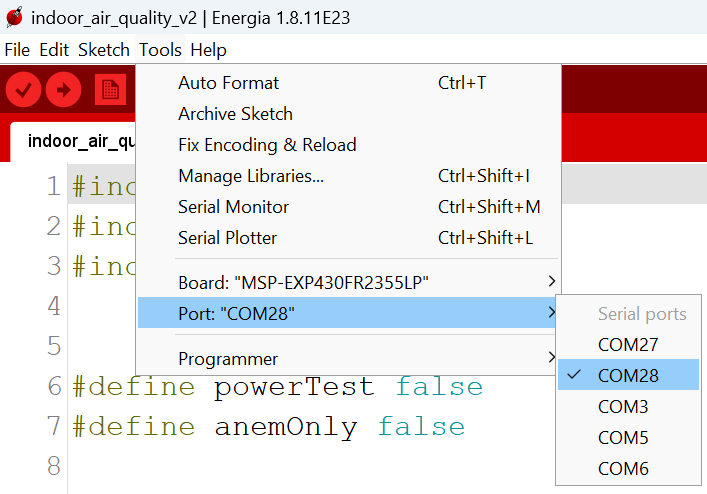
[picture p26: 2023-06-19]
Documentation/Final Report/Latex Files/Pictures/COM port selected.png

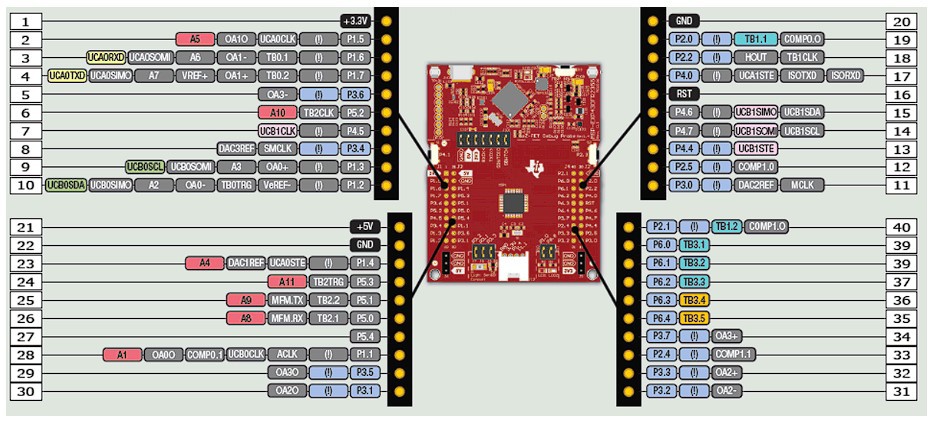
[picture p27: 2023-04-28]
Google Drive/website/PICS/pinout.jpg

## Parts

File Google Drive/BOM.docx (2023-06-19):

Quantity | Manufacturer | Model # | Link | Description | Price ($) | Notes
1 | Modern Device | Wind Sensor Rev. C | https://moderndevice.com/products/wind-sensor | Ultrasonic Anemometer Verification | 21.95
1 | AdaFruit | SGP30 | https://www.digikey.com/en/products/detail/adafruit-industries-llc/3709/8258468 | eCO2 Sensor | 17.5
1 | AdaFruit | US-100 Ultrasonic Distance Sensor Module | https://www.digikey.com/en/products/detail/adafruit-industries-llc/4019/9808308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 | Ultrasonic Anemometer | 6.95
1 | Sensirion | SPS30 | https://www.digikey.com/en/products/detail/sensirion-ag/SPS30/9598990 | PM 2.5 Sensor | 50.25
20 | Alpha-Omega | P-channel mosfet | https://www.digikey.com/en/products/detail/alpha-omega-semiconductor-inc/AO3401A/1855773 | | 0.346
10 | Alpha-Omega | N-Channel mosfet | https://www.digikey.com/en/products/detail/alpha-omega-semiconductor-inc/AO3422/1855787 (https://www.adafruit.com/product/4711) | | 0.331
40 | Yageo | 47k resistor | https://www.digikey.com/en/products/detail/yageo/RC1206FR-0747KL/728931 | | 0.038
40 | Yageo | 0 ohm resistor | https://www.digikey.com/en/products/detail/yageo/RC1206JR-070RL/729184 | | 0.05
30 | Sullins | Pin Header | https://www.digikey.com/en/products/detail/sullins-connector-solutions/PPPC101LFBN-RC/810182 | | 0.57
8 | Molex | Pin Header Male | https://www.digikey.com/en/products/detail/molex/0022284104/313970 | | 0.67

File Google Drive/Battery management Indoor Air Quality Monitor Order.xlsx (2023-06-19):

Item description | Quantity | Unit price ($) | Link to item on vendor website | Notes (optional)
P-channel mosfet | 20 | 0.346 | https://www.digikey.com/en/products/detail/alpha-omega-semiconductor-inc/AO3401A/1855773 (https://www.adafruit.com/product/1944)
N-Channel mosfet | 10 | 0.331 | https://www.digikey.com/en/products/detail/alpha-omega-semiconductor-inc/AO3422/1855787 (https://www.adafruit.com/product/4711)
47k resistor | 40 | 0.038 | https://www.digikey.com/en/products/detail/yageo/RC1206FR-0747KL/728931
0 ohm resistor | 40 | 0.05 | https://www.digikey.com/en/products/detail/yageo/RC1206JR-070RL/729184
Pin Header | 30 | 0.57 | https://www.digikey.com/en/products/detail/sullins-connector-solutions/PPPC101LFBN-RC/810182
Pin Header Male | 8 | 0.67 | https://www.digikey.com/en/products/detail/molex/0022284104/313970

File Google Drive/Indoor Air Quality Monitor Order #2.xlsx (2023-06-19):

Item description | Quantity | Unit price ($) | Link to item on vendor website | Notes (optional)
Wind Sensor with I2C | 1 | 23 | https://www.tindie.com/products/climateguard/wind-sensor-with-i2c-anemometr-arduino/#specs
Breadboard to JST-ZHR Cable - 5-pin x 1.5mm Pitch | 4 | 3.5 | https://www.sparkfun.com/products/15108 | For PM2.5 Sensor

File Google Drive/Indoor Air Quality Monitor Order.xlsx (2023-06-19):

Item description | Quantity | Unit price ($) | Link to item on vendor website | Notes (optional)
Wind Sensor Rev. C | 1 | 21.95 | https://moderndevice.com/products/wind-sensor | Ultrasonic Anemometer Verification
SGP30 | 4 | 17.5 | https://www.digikey.com/en/products/detail/adafruit-industries-llc/3709/8258468 | eCO2 Sensor
US-100 Ultrasonic Distance Sensor Module | 8 | 6.95 | https://www.digikey.com/en/products/detail/adafruit-industries-llc/4019/9808308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 | Ultrasonic Anemometer
SPS30 | 3 | 50.25 | https://www.digikey.com/en/products/detail/sensirion-ag/SPS30/9598990 | PM 2.5 Sensor

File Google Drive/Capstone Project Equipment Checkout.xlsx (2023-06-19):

Item | Amount | By | Picture
MSP430 | 1 | Adam
MSP430 | 1 | Brandon
MSP430 | 1 | Mercedes
MSP430 | 1 | Manny
Smart Mesh Board | 1 | Manny
Fan | 1 | Brandon
Wall AC to Molex Adapter | 1 | Brandon

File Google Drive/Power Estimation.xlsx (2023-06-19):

Micro Controllers | (Time on and Time off not necessary)
Name | Cost | Typical Power Consumption (On) | Voltage (On) | Typical Current (On) |  | Typical Power Consumption (Off) | Voltage (Off) | Typical Current (Off) |  | Notes
MSP430 (https://www.ti.com/tool/MSP-EXP430FR2355#tech-docs) | 12.99 |  | 3.3 V | 142 uA |  |  | 3.3 V | 1.43 uA |  | Calculated using Active Mode Supply Current per MHz
STM32 (https://www.st.com/en/microcontrollers-microprocessors/stm32-ultra-low-power-mcus.html#documentation) | 12.99 |  | 3.3 V | 185 uA |  |  | 3.3 V | 1.4 uA |  | Cost is a placeholder
PM2.5 Sensors
Name | Cost | Typical Power Consumption (On) | Voltage (On) | Typical Current (On) | Time (On) | Typical Power Consumption (Off) | Voltage (Off) | Typical Current (Off) | Time (Off) | Notes
Plantower PMS5003 (https://www.adafruit.com/product/3686) | 39.95 |  | 5 V | 100 mA | 30 s |  | 5 V | 200 uA | 270 s | Stable data 30sec after startup
Prana Air PAS-OUT-01 (https://www.pranaair.com/us/air-quality-sensor/outdoor-pm-sensor/) | 19 |  | 5 V | 70 mA | 30 s |  | 5 V | 200 uA | 270 s | Assuming stable data after 30 sec
Sensirion SPS30 (https://sensirion.com/products/catalog/SPS30/) | 42.93 |  | 5 V | 55 mA | 10 s |  | 0 V | 0 uA | 5990 s
Prana Air PAS-IN-01 (https://www.pranaair.com/air-quality-sensor/indoor-pm-sensor/) | 19 |  | 5 V | 70 mA | 15 s |  | 5 V | 0 uA | 270 s | Assuming stable data after 30 sec
CO2 Sensors
Name | Cost | Typical Power Consumption (On) | Voltage (On) | Typical Current (On) | Time (On) | Typical Power Consumption (Off) | Voltage (Off) | Typical Current (Off) | Time (Off) | Notes
Sensirion SGP30 (https://www.adafruit.com/product/3709) | 17.5 |  | 1.8 V | 48.2 mA | 1 s |  | 1.8 V | 2 uA | 299 s | eCO2
MQ-135 (https://www.makerfabs.com/mq135-gas-sensor-for-air-quality.html) | 1.5 | 800 mW |  |  | 20 s |  | 0 V | 0 mA | 280 s | eCO2
Sensirion SCD40 (https://www.adafruit.com/product/5187) | 49.95 |  | 3.3 V | 15 mA | 15 s |  | 0 V | 0 mA | 1785 s | True CO2
Sensirion SCD30 (https://www.adafruit.com/product/4867) | 58.95 |  | 3.3 V | 19 mA | 20 s |  | 0 V | 0 mA | 298 s | True CO2
Prana Air CO2 Sensor (https://www.pranaair.com/air-quality-sensor/carbon-dioxide-co2-sensor/) | 19 |  | 5 V | 20 mA | 15 s |  | 0 V | 0 mA | 285 s | True CO2
Air Speed Sensors
Name | Cost | Typical Power Consumption (On) | Voltage (On) | Typical Current (On) | Time (On) | Typical Power Consumption (Off) | Voltage (Off) | Typical Current (Off) | Time (Off) | Notes
Custom Ultrasonic Anemometer (https://www.digikey.com/en/products/detail/adafruit-industries-llc/4007/9857020) | 7.9 |  | 3.3 V | 4.4 mA | 3 s |  | 0 V | 0 mA | 87 s | The wind gust peak is usually averaged over 3 seconds (historical from the time constant of cup anemometers).
Modern Device Wind Sensor Rev. C (https://moderndevice.com/products/wind-sensor) | 21.95 |  | 5 V | 30 mA | 13 s |  | 0 V | 0 mA | 1187 s | Dynamically adjust sensor rate with airspeed (need to do HVAC research)

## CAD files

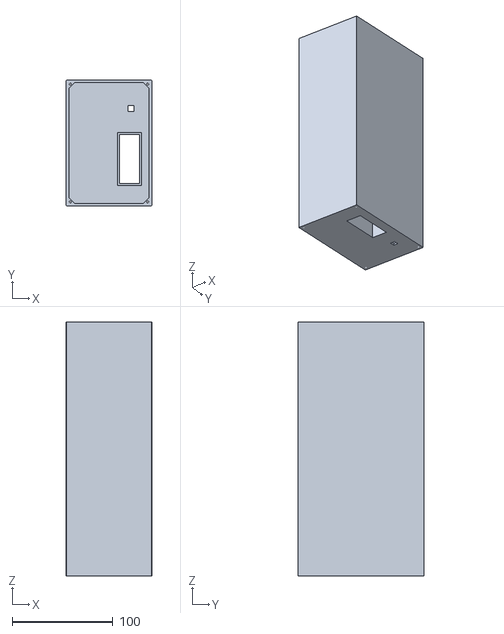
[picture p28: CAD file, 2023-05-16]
Enclosure/EnclosurePrintWHoles.stl
85.0 x 125.0 x 252.5

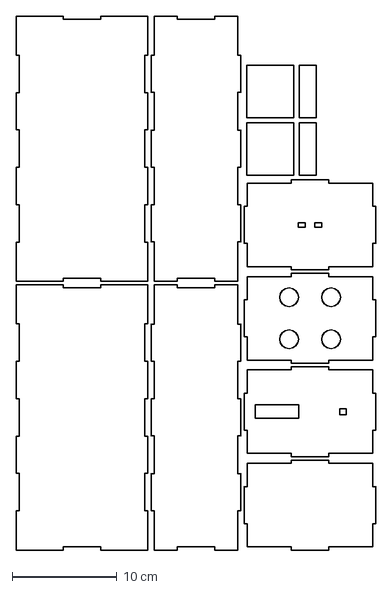
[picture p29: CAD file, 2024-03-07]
Enclosure/box_v2.dxf
34.3 x 50.9 cm

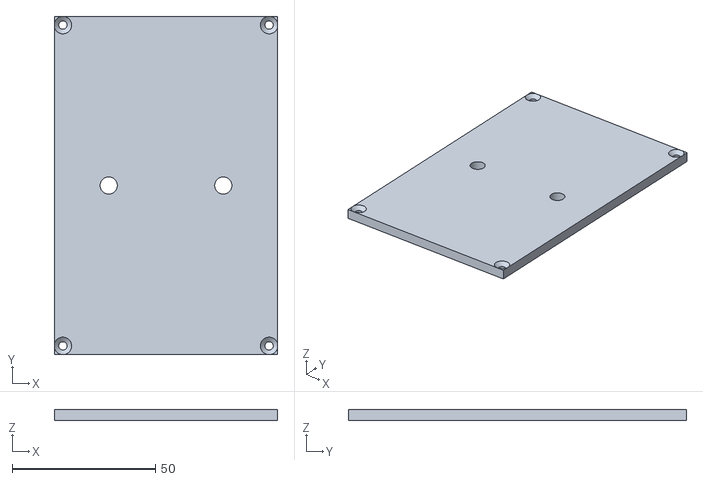
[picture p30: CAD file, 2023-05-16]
Enclosure/2holeLid.stl
78.0 x 118.0 x 4.00

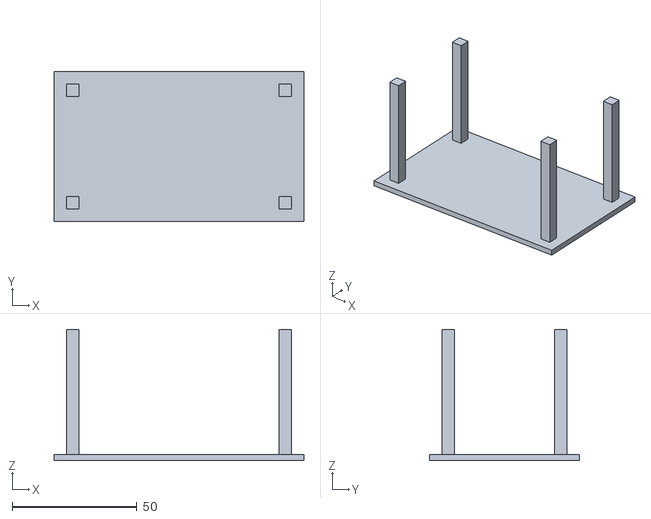
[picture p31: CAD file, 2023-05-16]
Enclosure/TableOnly.stl
100.0 x 60.0 x 52.5

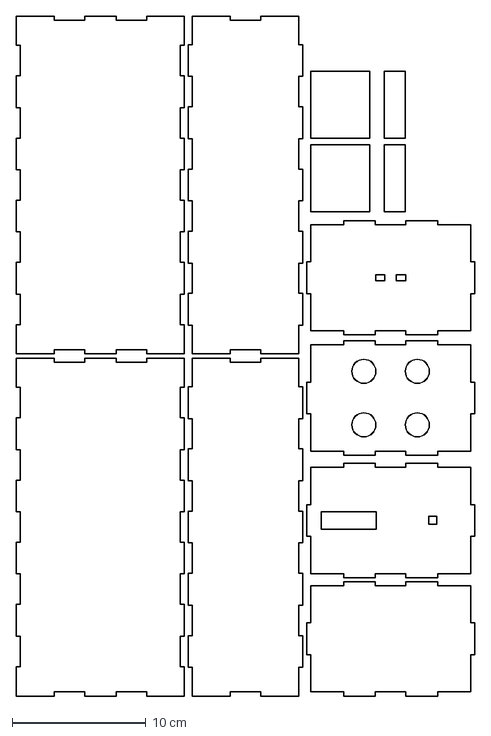
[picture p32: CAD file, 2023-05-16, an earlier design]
Enclosure/box.dxf
34.2 x 50.8 cm

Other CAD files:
Enclosure/PlainLid.stl
Enclosure/4holeLid.stl

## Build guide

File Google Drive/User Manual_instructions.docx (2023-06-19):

# Software

1. Download Energia, KiCAD, and FreeCAD. Links to download as well versions used at the time can be found in Appendix ????
2. Open Github Repository (https://github.com/brandonhippe/412AirQualityCapstone). Open the Code folder then add all the folders inside the Libraries folder inside the Energia libraries folder
3. Launch Energia and make sure to select the “MSP - EXP430FR2355LP” in the board section under the Tools tab
4. Upload the code found in the sensor code folder to Energia

# Hardware

Part 1: Building Enclosure

1. Go to GitHub Repository and save all the files saved under the Enclosure folder.

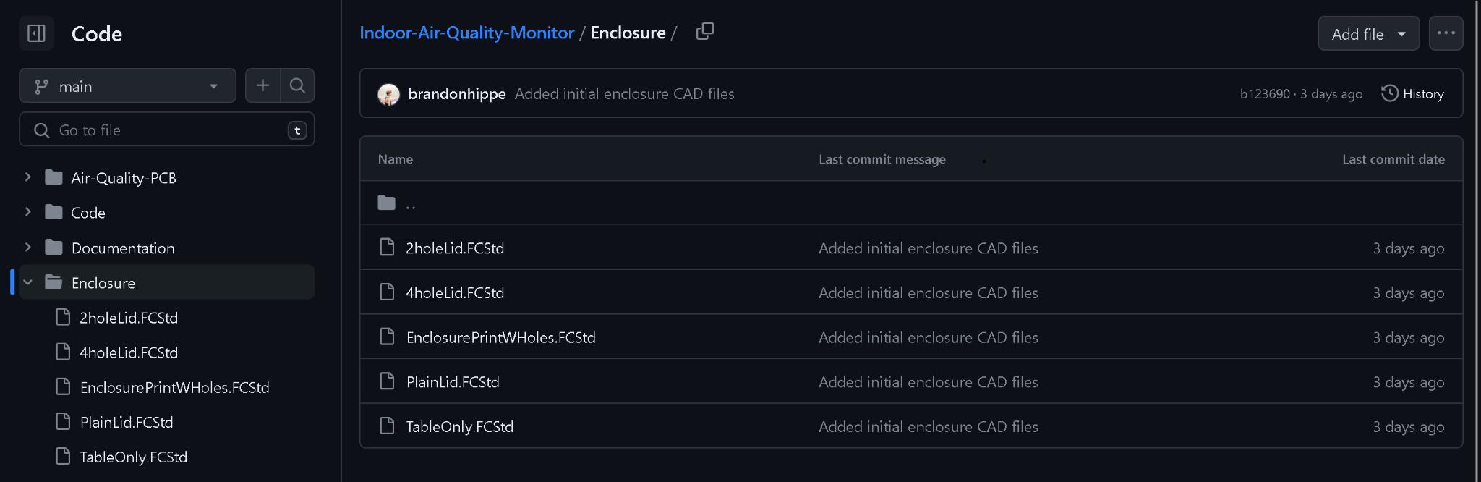
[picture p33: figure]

2. Open Files using FreeCAD to make any adjustments and print them to your 3D printer using the appropriate format for that printer
3. Assemble parts together once they finish printing

Part 2: Building PCB

1. Go to GitHub Repository and save all the .gbr files under the Air-Quality-PCB folder.

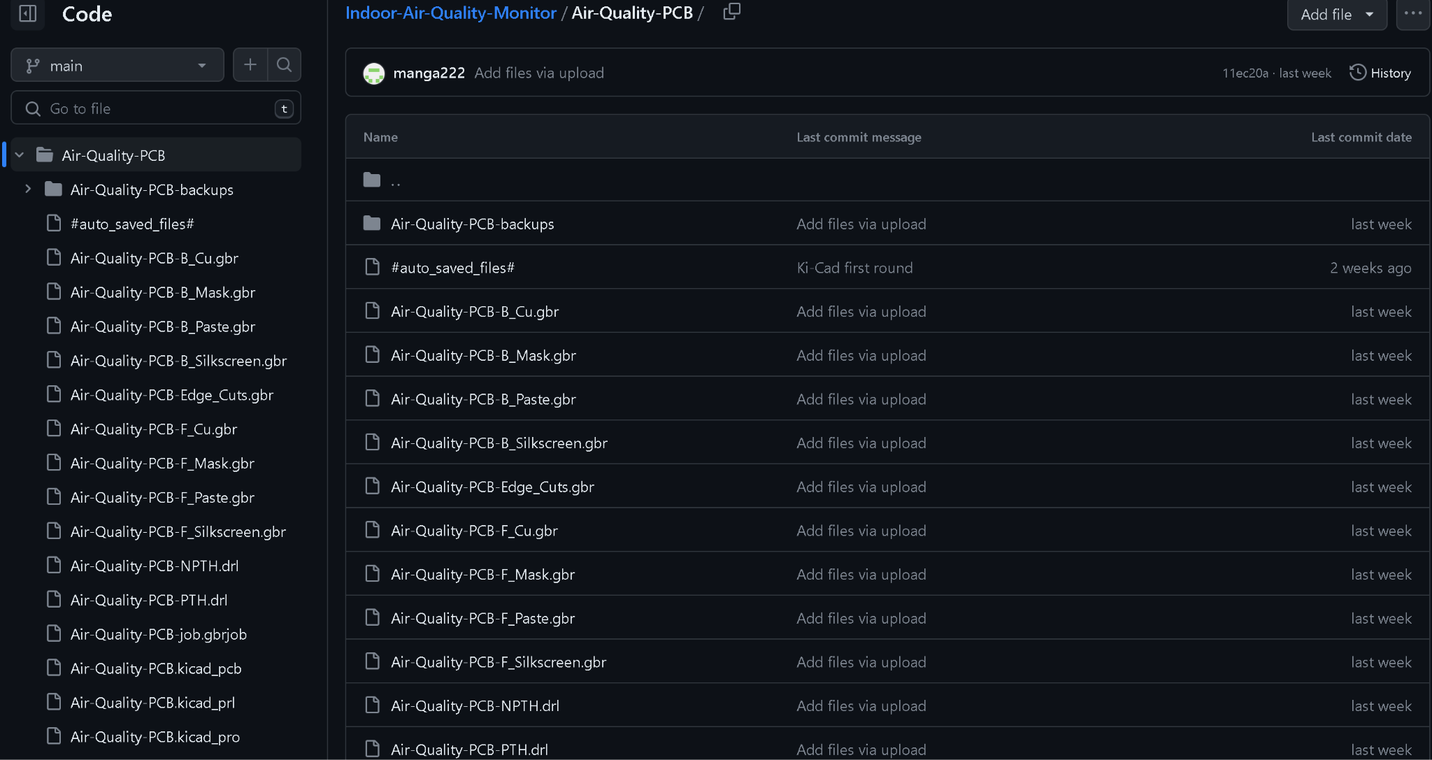
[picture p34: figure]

2. Open the website of your PCB manufacturer and go to their ordering page
  a. We used JLCPCB for the project as they were the cheapest and fastest at the time. Link can be found in Appendix ????
3. Drag and drop all the .gbr files
4. Select your options
  a. We selected the default options at time but chose to go with faster delivery
5. Solder on connection points so the MSP430 can be seated onto the PCB
6. Solder pins onto powerboost charger as well as the 3.3 converter
  a. We ended up removing LED(power and Low indicators) since they consumed too much power and were always on

## Appendix A: Troubleshooting

## Energia Issues

### Java Runtime Environment error

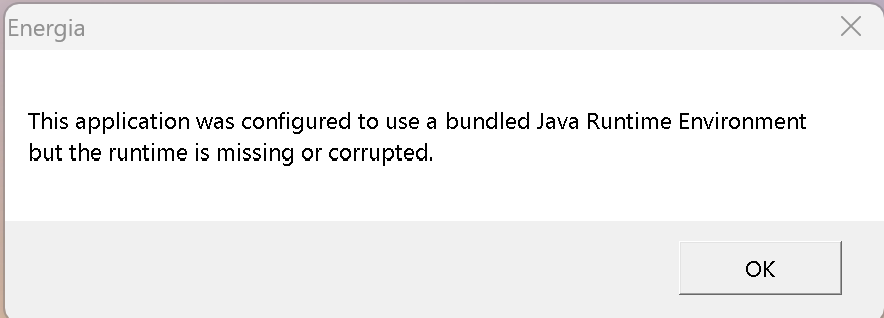
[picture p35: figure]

Solution:

To solve this issue, You must save Energia to your C: Folder and open it from there each time. The Desktop Shortcut will keep giving you this error.

Appendix B: Software links

List of used software and links:

1. Energia (https://energia.nu/download/)
2. KiCad(https://www.kicad.org/download/)
3. Github Repository(https://github.com/brandonhippe/412AirQualityCapstone)
4. FreeCAD (https://www.freecad.org/downloads.php)
5. JLCPCB (https://cart.jlcpcb.com/quote)

Versions used at time of build:

1. Energia 1.8.10E23
2. KiCad 7.0.2
3. FreeCAD 0.20.2

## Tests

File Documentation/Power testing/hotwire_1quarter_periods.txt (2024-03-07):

Battery Life with Anemometer: 92.16 days
Micro Com: MSP430FR2355 + SmartMesh IP
	Period: 51840.0 sec
	Percent of total power: 10.37%
PM2.5 Sensor: Sensirion SPS30
	Period: 1920.0 sec
	Percent of total power: 44.74%
	Percent of component power consumed in sleep: 0.00%
CO2 Sensor: Sensirion SGP30
	Period: 1620.0 sec
	Percent of total power: 44.90%
	Percent of component power consumed in sleep: 0.00%

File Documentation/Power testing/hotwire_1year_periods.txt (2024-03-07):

Battery Life with Anemometer: 366.56 days
Micro Com: MSP430FR2355 + SmartMesh IP
	Period: 397800.0 sec
	Percent of total power: 42.44%
PM2.5 Sensor: Sensirion SPS30
	Period: 11700.0 sec
	Percent of total power: 29.20%
	Percent of component power consumed in sleep: 0.00%
CO2 Sensor: Sensirion SGP30
	Period: 10200.0 sec
	Percent of total power: 28.36%
	Percent of component power consumed in sleep: 0.00%

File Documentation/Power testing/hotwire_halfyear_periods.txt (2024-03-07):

Battery Life with Anemometer: 183.14 days
Micro Com: MSP430FR2355 + SmartMesh IP
	Period: 263520.0 sec
	Percent of total power: 21.00%
PM2.5 Sensor: Sensirion SPS30
	Period: 4320.0 sec
	Percent of total power: 39.51%
	Percent of component power consumed in sleep: 0.00%
CO2 Sensor: Sensirion SGP30
	Period: 3660.0 sec
	Percent of total power: 39.49%
	Percent of component power consumed in sleep: 0.00%

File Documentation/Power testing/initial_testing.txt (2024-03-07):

Battery Life without Anemometer: 365.50 days
Micro Controller: MSP430FR2355
	Period: 1487400.0 sec
	Percent of total power: 9.96%
Communication: SmartMesh Mote
	Period: 4440.0 sec
	Percent of total power: 0.23%
	Percent of component power consumed in sleep: 78.05%
PM2.5 Sensor: Sensirion SPS30
	Period: 20100.0 sec
	Percent of total power: 45.10%
	Percent of component power consumed in sleep: 38.11%
CO2 Sensor: Sensirion SGP30
	Period: 4440.0 sec
	Percent of total power: 44.71%
	Percent of component power consumed in sleep: 17.08%

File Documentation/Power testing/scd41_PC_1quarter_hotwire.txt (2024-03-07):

Battery Life without Anemometer: 92.46 days
Micro Com: MSP430FR2355 + SmartMesh IP
	Period: 6300.0 sec
	Percent of total power: 19.58%
PM2.5 Sensor: Sensirion SPS30
	Period: 2100.0 sec
	Percent of total power: 41.03%
	Percent of component power consumed in sleep: 0.00%
CO2 Sensor: Sensirion SCD41
	Period: 900.0 sec
	Percent of total power: 39.39%
	Percent of component power consumed in sleep: 0.00%

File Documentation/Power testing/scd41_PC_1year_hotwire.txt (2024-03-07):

Battery Life without Anemometer: 365.67 days
Micro Com: MSP430FR2355 + SmartMesh IP
	Period: 1579200.0 sec
	Percent of total power: 79.91%
PM2.5 Sensor: Sensirion SPS30
	Period: 33600.0 sec
	Percent of total power: 10.14%
	Percent of component power consumed in sleep: 0.00%
CO2 Sensor: Sensirion SCD41
	Period: 14100.0 sec
	Percent of total power: 9.94%
	Percent of component power consumed in sleep: 0.00%

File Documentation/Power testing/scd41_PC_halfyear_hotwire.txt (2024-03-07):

Battery Life without Anemometer: 183.31 days
Micro Com: MSP430FR2355 + SmartMesh IP
	Period: 39780.0 sec
	Percent of total power: 39.44%
PM2.5 Sensor: Sensirion SPS30
	Period: 3060.0 sec
	Percent of total power: 30.55%
	Percent of component power consumed in sleep: 0.00%
CO2 Sensor: Sensirion SCD41
	Period: 2340.0 sec
	Percent of total power: 30.01%
	Percent of component power consumed in sleep: 0.00%

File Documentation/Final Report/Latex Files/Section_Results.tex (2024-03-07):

\begin{figure}[H]
    \centering
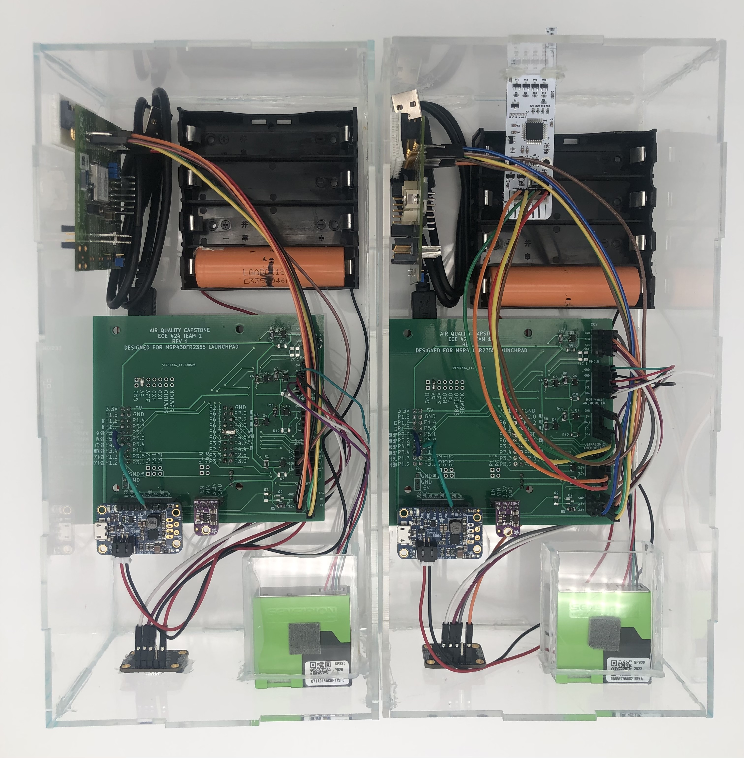
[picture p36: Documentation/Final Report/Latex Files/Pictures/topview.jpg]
    
    \caption[Top view of the node]{Top view of the nodes} 
    \label{fig:results}
\end{figure}
Our project was successful in satisfying all requirements. Our team was able to build 4 working nodes that all communicate using SmartMesh. The CO$_2$ and PM2.5 sensors are working properly within the acrylic enclosure built. The tables below show estimations of how often we can collect and publish data based on how long we want our batteries to last. The captured intervals can be modified using only 1 line in the code for the system. As shown in the power consumption figure, the hot wire anemometer is the most power hungry part of this project. We recommend that teams look into using an alternative option like the ultrasonic anemometer.\\\\
% Please add the following required packages to your document preamble:
% \usepackage{graphicx}
\begin{table}[h]
\centering
\resizebox{\textwidth}{!}{%
\begin{tabular}{|l|l|l|l|}
\hline
Sensor & 3 Months Battery Life & 6 Months Battery Life & 1 Year Battery Life \\ \hline
CO$_2$  & 8 min 30 sec (510 sec)     & 18 min (1,080 sec)     & 37 (2,220 sec)       \\ \hline
PM2.5  & 16 min (960 sec)      & 34 min (2,040 sec)      & 72 min (4,320 sec)       \\ \hline
\end{tabular}%
}
\caption{Component Measurement Periods for 3 month, 6 month, and 1 year battery life for units without anemometer
}
\label{tab:no annemometer}
\end{table}

% Please add the following required packages to your document preamble:
% \usepackage{graphicx}
\begin{table}[htbp]
\centering
\resizebox{\textwidth}{!}{%
\begin{tabular}{|l|l|l|l|}
\hline
Sensor             & 3 Months Battery Life & 6 Months Battery Life & 1 Year Battery Life \\ \hline
CO$_2$             & 27 min (1,620 sec)     & 61 min (3,660 sec)     & 170 min (10,200 sec) \\ \hline
PM2.5              & 32 min (1,920 sec)     & 72 min (4,320 sec)    & 195 min (11,700 sec) \\ \hline
Hotwire Anemometer & 14 min 38 sec (878 sec)      & 33 min (1,980 sec)     & 90 min 50 sec (5,450 sec)   \\ \hline
\end{tabular}%
}
\caption{Component Measurement Periods for 3 month, 6 month, and 1 year battery life for units with a hot wire anemometer
}
\label{tab:hot annemometer}
\end{table}

% Please add the following required packages to your document preamble:
% \usepackage{graphicx}
\begin{table}[htbp]
\centering
\resizebox{\textwidth}{!}{%
\begin{tabular}{|l|l|l|l|}
\hline
Sensor                & 3 Months Battery Life & 6 Months Battery Life & 1 Year Battery Life \\ \hline
CO$_2$                & 12 min (720 sec)      & 25 min (1,500 sec)     & 51 (3,060 sec)       \\ \hline
PM2.5                 & 22 min (1,320 sec)     & 48 min (2,880 sec)     & 105 min (6,330) sec  \\ \hline
Ultrasonic Anemometer & 10 sec                & 20 sec                & 40 sec              \\ \hline
\end{tabular}%
}
\caption{Component Measurement Periods for 3 month, 6 month, and 1 year battery life for units with an ultrasonic anemometer
}
\label{tab:no annemometer}
\end{table}
% Please add the following required packages to your document preamble:
% \usepackage{graphicx}
\begin{table}[htbp]
\centering
\resizebox{\textwidth}{!}{%
\begin{tabular}{|l|l|l|l|}
\hline
Configuration         & 3 Months Battery Life & 6 Months Battery Life & 1 Year Battery Life \\ \hline
Without Annemometer   & $\sim$820 KB          & $\sim$810 KB          & $\sim$700 KB        \\ \hline
Ultrasonic Anemometer & $\sim$16.15 MB        & $\sim$16.14 MB        & $\sim$16.27 MB      \\ \hline
Hotwire Anemometer    & $\sim$370 KB          & $\sim$334 KB          & $\sim$258 KB        \\ \hline
\end{tabular}%
}
\caption{ Log file sizes after draining batteries for each configuration set to 3 month, 6 month, and 1 year battery life
}
\label{tab:CONFIG OF ALL}
\end{table}

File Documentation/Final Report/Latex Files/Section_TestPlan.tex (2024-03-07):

\subsection{Power Consumption}
As we were building the modules, we tested the power consumption of the parts to determine what sensor measurement periods would allow us to achieve 3 months, 6 months, and 1 year battery life. The following is how we tested our power consumption.
\newline \newline
Equipment needed: Joulescope JS110, Breadboard Prototype w/battery management circuitry
\newline Values needed:
\begin{enumerate}
\item Combined MSP430 and SmartMesh power consumption during sleep (no sensors active \& SmartMesh inactive)
\item Combined CO$_2$, MSP430, and SmartMesh charge consumption for a CO$_2$ measurement
\item CO$_2$ power consumption while sleeping between measurements
\item Combined PM2.5, MSP430, and SmartMesh charge consumption for a PM2.5 measurement
\item PM2.5 power consumption while sleeping between measurements
\item Combined Anemometer, MSP430, and SmartMesh charge consumption for an airspeed measurement for both Ultrasonic and Hot wire anemometers
\item Anemometer power consumption while sleeping between measurements
\end{enumerate}
Instructions for Combined MSP430 and SmartMesh power consumption during sleep:
\begin{enumerate}
\item Unplug all sensors from system, and unplug 5V, 3.3V, and RXD jumpers from EnergyTrace System on MSP430
\item Set up power supply and Joulescope to supply 3.7V to battery management circuitry, with the Joulescope set up to monitor current consumption to the battery management circuitry
\item Set up host SmartMesh node
\item Change line 6 from \texttt{\#define powerTest false} to \texttt{\#define powerTest true}, if necessary
\item Run \texttt{indoor\_air\_quality\_v2.ino}
\item Turn on power supply
\item Ensure node connects to host node, and transmits two packets consisting of (48879, 48879)
\item Turn off power supply
\item Start collecting data on Joulescope
\item Turn on power supply
\item Let \textasciitilde5-10 packets of (48879, 48879) transmit to host node
\item Stop data collection on Joulescope
\item Analyze JouleScope data, and obtain average power consumption from the low, flat portions of the graph (when the MCU is in sleep). Store this number in the Power Consumption Test Results google sheet under \texttt{Typical Power Consumption (off)} for \texttt{Micro Com}. Make sure to include correct units with prefix (e.g. mW for milliWatts, uW for microWatts)

\end{enumerate}
Instructions for Combined Sensor, MSP430, and SmartMesh charge consumption, along with Sensor sleep power consumption
\begin{enumerate}
\item Unplug all sensors, except sensor under test, from breadboard, and unplug 5V, 3.3V, and RXD jumpers from EnergyTrace System on MSP430
\item Set up power supply and Joulescope to supply 3.7V to battery management circuitry, with the Joulescope set up to monitor current consumption to the battery management circuitry
\item Set up host SmartMesh node
\item Turn on power supply
\item Run \texttt{indoor\_air\_quality\_v2.ino}
\item Change line 6 from \texttt{\#define powerTest false} to \texttt{\#define powerTest true}, if necessary
\item Ensure node connects to host node, and transmits one packet consisting of (48879, 48879), followed by sensor initialization and one packet of sensor data
\item Turn off power supply
\item Start collecting data on Joulescope
\item Turn on power supply
\item Let \textasciitilde5-10 packets of sensor data transmit to host node
\item Stop data collection on Joulescope
\item Analyze JouleScope data, and obtain average charge consumption from the higher portions of the graph, which should be approximately the same amount of time as the time needed for that sensor to collect its data (\textasciitilde15 seconds CO2, \textasciitilde30 seconds PM2.5, \textasciitilde10 seconds Hot Wire Anemometer, \textasciitilde6 seconds Ultrasonic Anemometer). Store this number in the Power Consumption Test Results google sheet under \texttt{Charge Consumed (On)} for that sensor. Make sure to include correct units (e.g. mC for milliCoulombs, uC for microCoulombs)
\item Using the same JouleScope data, obtain average power consumption from the lower, flat portions of the graph (when the sensor is asleep). Take this number and subtract the power consumption obtained for the MSP430 and SmartMesh sleep power consumption. Store this number in the Power Consumption Test Results google sheet under \texttt{Typical Power Consumption (off)} for that sensor. Make sure to include correct units with prefix (e.g. mW for milliWatts, uW for microWatts)
\end{enumerate}
Instructions for calculating sensor measurement periods
\begin{enumerate}
\item Export the Power Consumption Test Results google sheet. Save it as \texttt{Power Consumption Test Results - Power Consumption.csv} in the directory \\\texttt{/Documentation/Power Testing}
\item Run the python script \texttt{powerData.py}. Follow the prompts it gives you. It will calculate the measurement periods for each sensor, and display other useful information about the components power consumption.
\item If you would like, there are a few easy to edit values in the \texttt{powerData.py} script. These are available in the first \textasciitilde20 lines of the program, and are as follows:
\begin{itemize}
    \item \texttt{BAT\_MAH}: capacity of your battery(s), in mAh (milliAmp\-hours)
    \item \texttt{BAT\_VOLT}: nominal voltage of your battery(s), in volts
    \item \texttt{BAT\_NUM}: number of battery(s), if wired in parallel
    \item \texttt{MAX\_T}: maximum allowable sensor measurement period, in hours
    \item \texttt{GOAL\_DAYS}: Goal battery life, in days
\end{itemize}
\end{enumerate}
\newpage

\subsection{Long--term testing}
After finishing the sensor nodes, we set them up in the rooms used by the WEST Lab.  The host node was set up on the presentation system, with the graphing script visible on the presentation TV. The four sensor nodes were set up in each of the rooms (60--23, 60--24, 60--26) and the hallway outside of the lab.

\begin{figure}[H]
    \centering
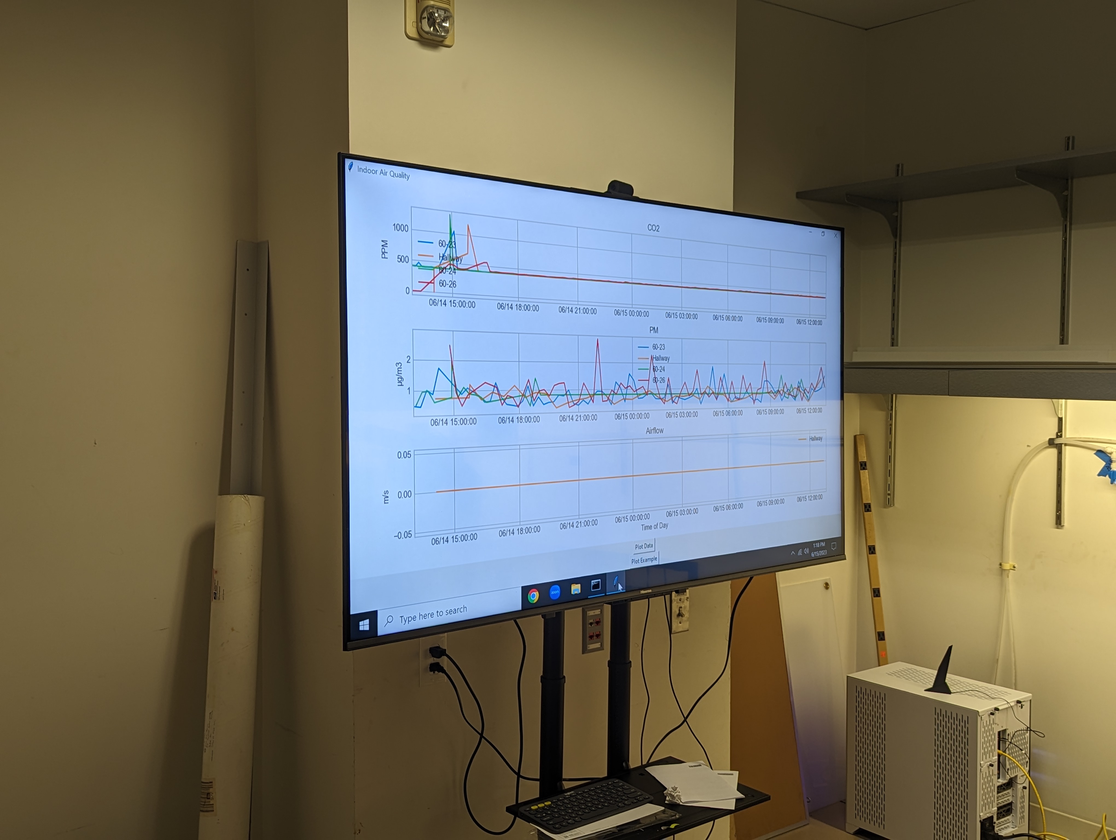
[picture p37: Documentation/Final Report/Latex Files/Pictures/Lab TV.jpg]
    
    \caption[Graphing script running on Lab TV]{Graphing script running on Lab TV}
    \label{fig:Graphing script running on Lab TV}
\end{figure}

\begin{figure}
    \centering
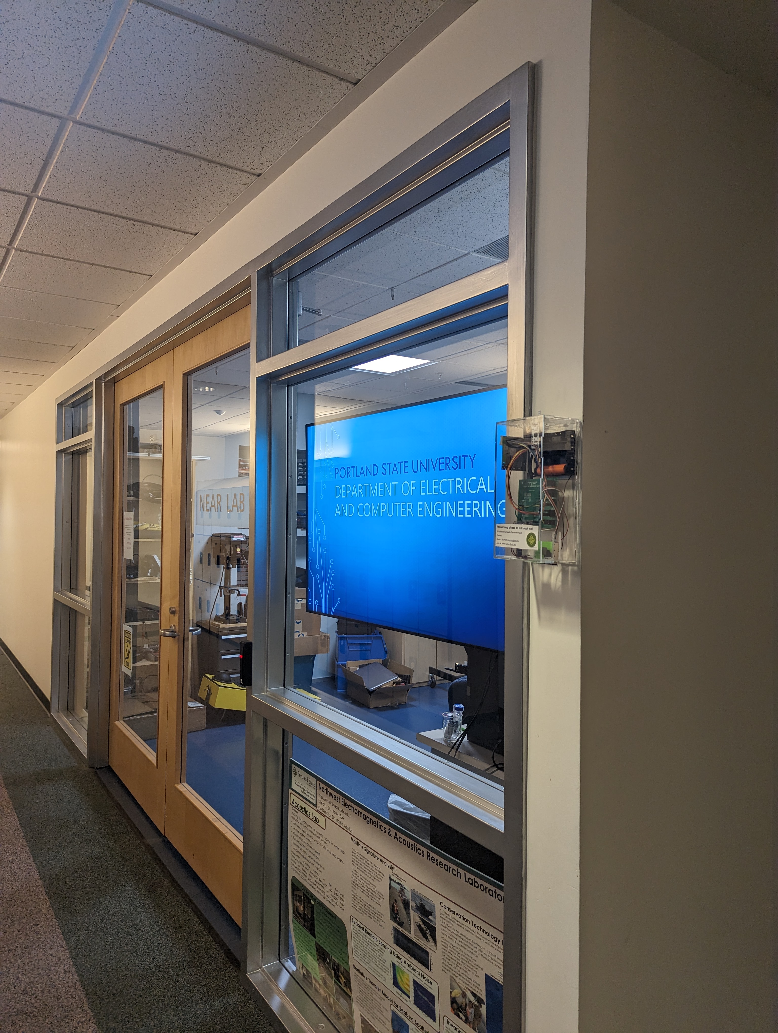
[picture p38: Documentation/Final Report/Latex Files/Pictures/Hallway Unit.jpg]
    
    \caption[Unit in FAB Basement Hallway]{Unit in FAB Basement Hallway}
    \label{fig:Unit in FAB Basement Hallway}
\end{figure}

\begin{figure}
    \centering
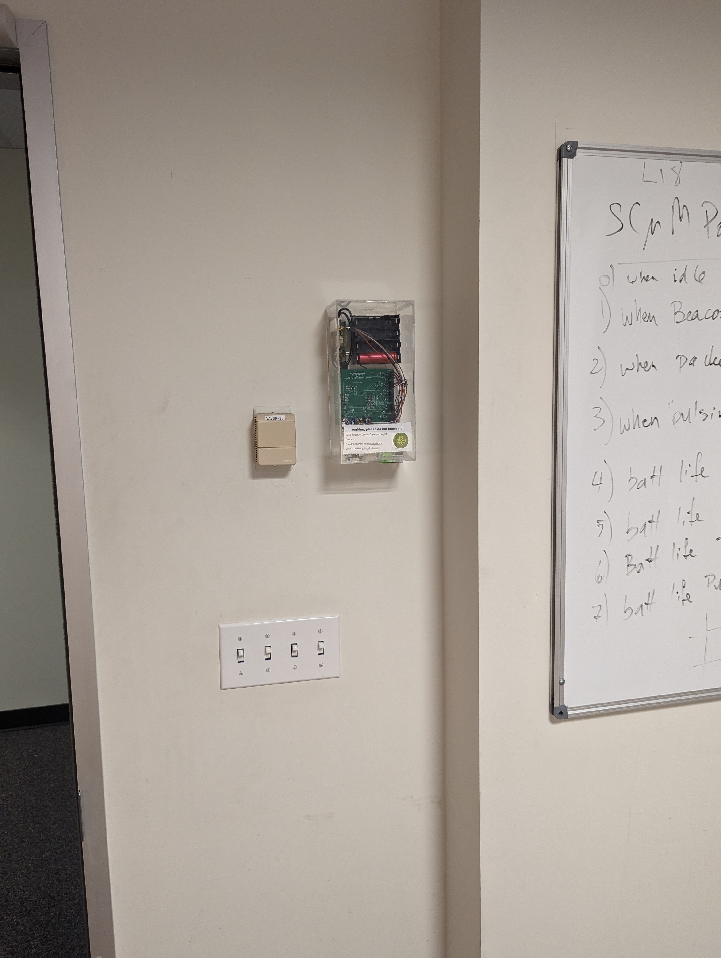
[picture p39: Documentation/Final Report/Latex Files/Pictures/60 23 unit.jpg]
    
    \caption[Unit in FAB 60--23]{Unit in FAB 60--23}
    \label{fig:Unit in FAB 60--23}
\end{figure}

\begin{figure}
    \centering
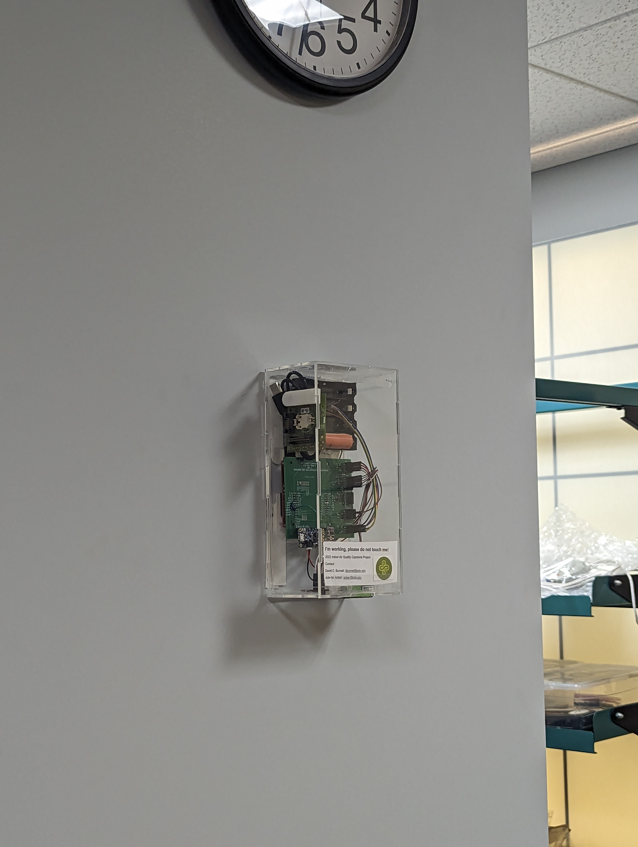
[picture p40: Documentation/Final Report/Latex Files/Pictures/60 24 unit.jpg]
    
    \caption[Unit in FAB 60--24]{Unit in FAB 60--24}
    \label{fig:Unit in FAB 60--24}
\end{figure}

\begin{figure}
    \centering
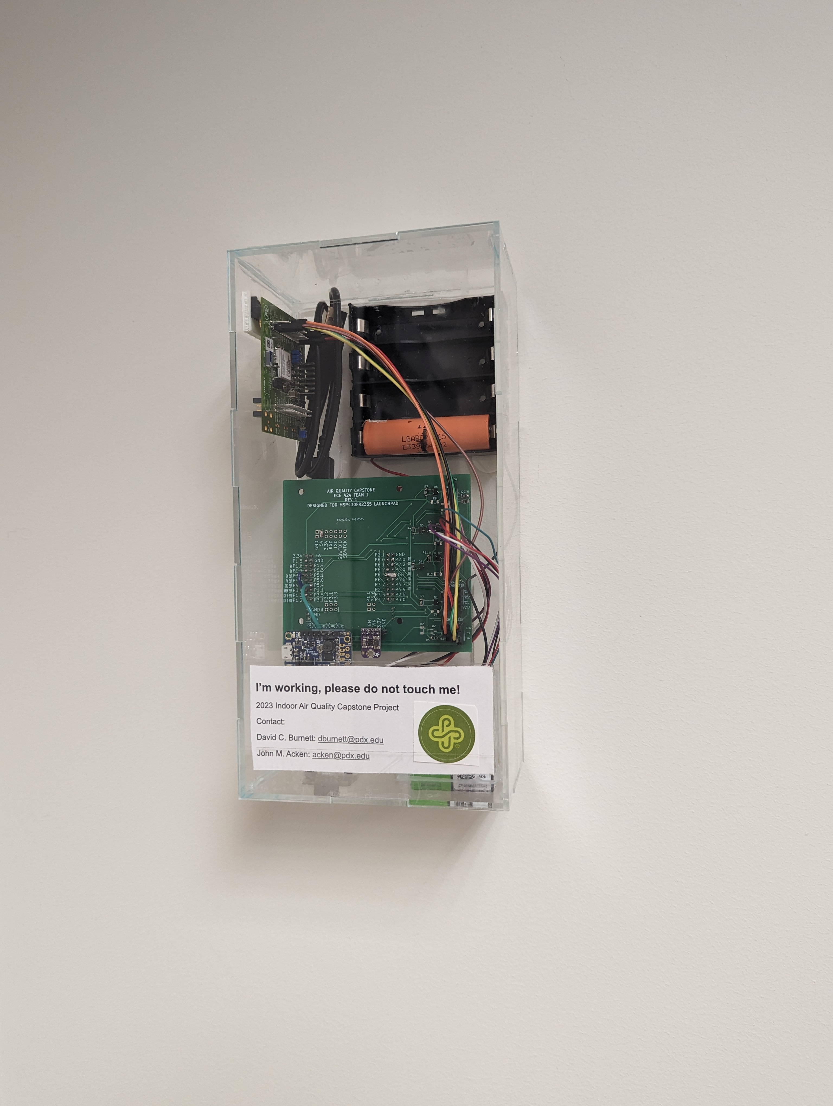
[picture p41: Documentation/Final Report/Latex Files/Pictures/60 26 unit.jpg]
    
    \caption[Unit in FAB 60--26]{Unit in FAB 60--26}
    \label{fig:Unit in FAB 60--26}
\end{figure}

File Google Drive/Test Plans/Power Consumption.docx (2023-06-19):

Power Consumption Test Plan

Equipment needed: Joulescope JS110, Breadboard Prototype w/battery management circuitry

Values needed:

1. Combined MSP430 and SmartMesh power consumption during sleep (no sensors active & SmartMesh inactive)
2. Combined CO2, MSP430, and SmartMesh charge consumption for a CO2 measurement
3. CO2 power consumption while sleeping between measurements
4. Combined PM2.5, MSP430, and SmartMesh charge consumption for a PM2.5 measurement
5. PM2.5 power consumption while sleeping between measurements
6. Combined Anemometer, MSP430, and SmartMesh charge consumption for an airspeed measurement for both Ultrasonic and Hot Wire anemometers
7. Anemometer power consumption while sleeping between measurements

Instructions for Combined MSP430 and SmartMesh power consumption during sleep:

1. Unplug all sensors from system, and unplug 5V, 3.3V, and RXD jumpers from EnergyTrace System on MSP430
2. Set up power supply and Joulescope to supply 3.7V to battery management circuitry, with the Joulescope set up to monitor current consumption to the battery management circuitry
3. Set up host SmartMesh node
4. Change line 6 from #define powerTest false to #define powerTest true, if necessary
5. Run “indoor_air_quality_v2.ino”
6. Turn on power supply
7. Ensure node connects to host node, and transmits two packets consisting of (48879, 48879)
8. Turn off power supply
9. Start collecting data on Joulescope
10. Turn on power supply
11. Let ~5-10 packets of (48879, 48879) transmit to host node
12. Stop data collection on Joulescope
13. Analyze JouleScope data, and obtain average power consumption from the low, flat portions of the graph (when the MCU is in sleep). Store this number in the Power Consumption Test Results google sheet under “Typical Power Consumption (off)” for “Micro Com”. Make sure to include correct units with prefix (e.g. mW for milliWatts, uW for microWatts)

Instructions for Combined Sensor, MSP430, and SmartMesh charge consumption, along with Sensor sleep power consumption

1. Unplug all sensors, except sensor under test, from breadboard, and unplug 5V, 3.3V, and RXD jumpers from EnergyTrace System on MSP430
2. Set up power supply and Joulescope to supply 3.7V to battery management circuitry, with the Joulescope set up to monitor current consumption to the battery management circuitry
3. Set up host SmartMesh node
4. Turn on power supply
5. Run “indoor_air_quality_v2.ino”
6. Change line 6 from #define powerTest false to #define powerTest true, if necessary
7. Ensure node connects to host node, and transmits one packet consisting of (48879, 48879), followed by sensor initialization and one packet of sensor data
8. Turn off power supply
9. Start collecting data on Joulescope
10. Turn on power supply
11. Let ~5-10 packets of sensor data transmit to host node
12. Stop data collection on Joulescope
13. Analyze JouleScope data, and obtain average charge consumption from the higher portions of the graph, which should be approximately the same amount of time as the time needed for that sensor to collect its data (~15 seconds CO2, ~30 seconds PM2.5, ~10 seconds Hot Wire Anemometer, ~3 seconds Ultrasonic Anemometer). Store this number in the Power Consumption Test Results google sheet under “Charge Consumed (On)” for that sensor. Make sure to include correct units (e.g. mC for milliCoulombs, uC for microCoulombs)
14. Using the same JouleScope data, obtain average power consumption from the lower, flat portions of the graph (when the sensor is asleep). Take this number and subtract the power consumption obtained for the MSP430 and SmartMesh sleep power consumption. Store this number in the Power Consumption Test Results google sheet under “Typical Power Consumption (off)” for that sensor. Make sure to include correct units with prefix (e.g. mW for milliWatts, uW for microWatts)

Instructions for calculating sensor measurement periods

1. Export the Power Consumption Test Results google sheet. Save it as "Power Consumption Test Results - Power Consumption.csv" in the directory /Documentation/Power Testing
2. Run the python script “powerData.py”. Follow the prompts it gives you. It will calculate the measurement periods for each sensor, and display other useful information about the components power consumption.
3. If you would like, there are a few easy to edit values in the “powerData.py” script. These are available in the first ~20 lines of the program, and are as follows:
  a. BAT_MAH: capacity of your battery(s), in mAh (milliAmp-hours)
  b. BAT_VOLT: nominal voltage of your battery(s), in volts
  c. BAT_NUM: number of battery(s), if wired in parallel
  d. MAX_T: maximum allowable sensor measurement period, in hours
  e. GOAL_DAYS: Goal battery life, in days

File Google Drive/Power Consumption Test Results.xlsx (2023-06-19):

Component | Name | Charge Consumed (On) | Period (minimum) | Typical Power Consumption (Off) | Notes
Micro Com | MSP430FR2355 + SmartMesh IP | 0 C | 0 s | 1.2068575 mW | On characteristics included with other component(s)
PM2.5 Sensor | Sensirion SPS30 | 2.76223 C | 30 s | 0 W
CO2 Sensor | Sensirion SGP30 | 1.386024 C | 30 s | 0 W
Anemometer | ClimateGuard Anemometer | 1.67447 C | 20 s | 0 W

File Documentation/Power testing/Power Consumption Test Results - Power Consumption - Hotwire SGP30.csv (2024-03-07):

Component | Name | Charge Consumed (On) | Period (minimum) | Typical Power Consumption (Off) | Notes
Micro Com | MSP430FR2355 + SmartMesh IP | 0 C | 0 s | 2.33285 mW | On characteristics included with other component(s)
PM2.5 Sensor | Sensirion SPS30 | 5.04858 C | 30 s | 0 W
CO2 Sensor | Sensirion SGP30 | 4.27486 C | 30 s | 0 W
Anemometer | ClimateGuard Anemometer | 1.67447 C | 20 s | 0 W

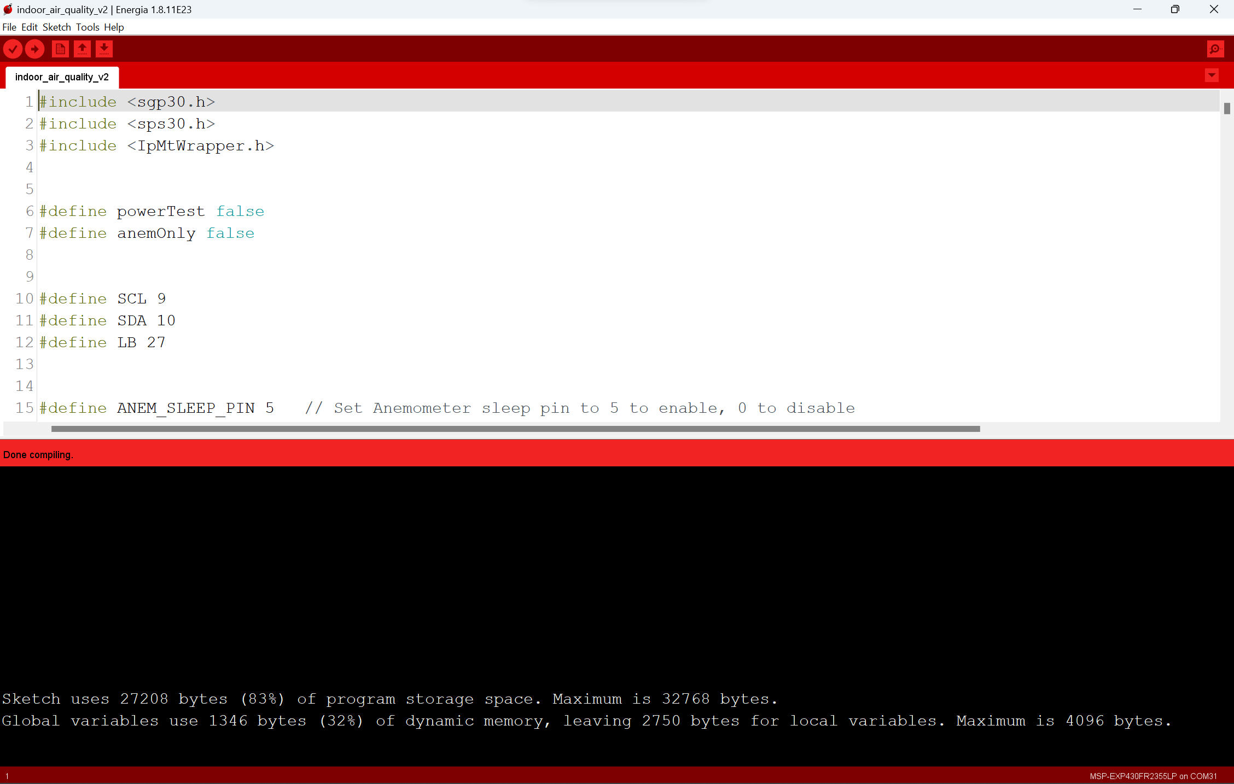
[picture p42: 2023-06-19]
Google Drive/Photos/Code verified.png

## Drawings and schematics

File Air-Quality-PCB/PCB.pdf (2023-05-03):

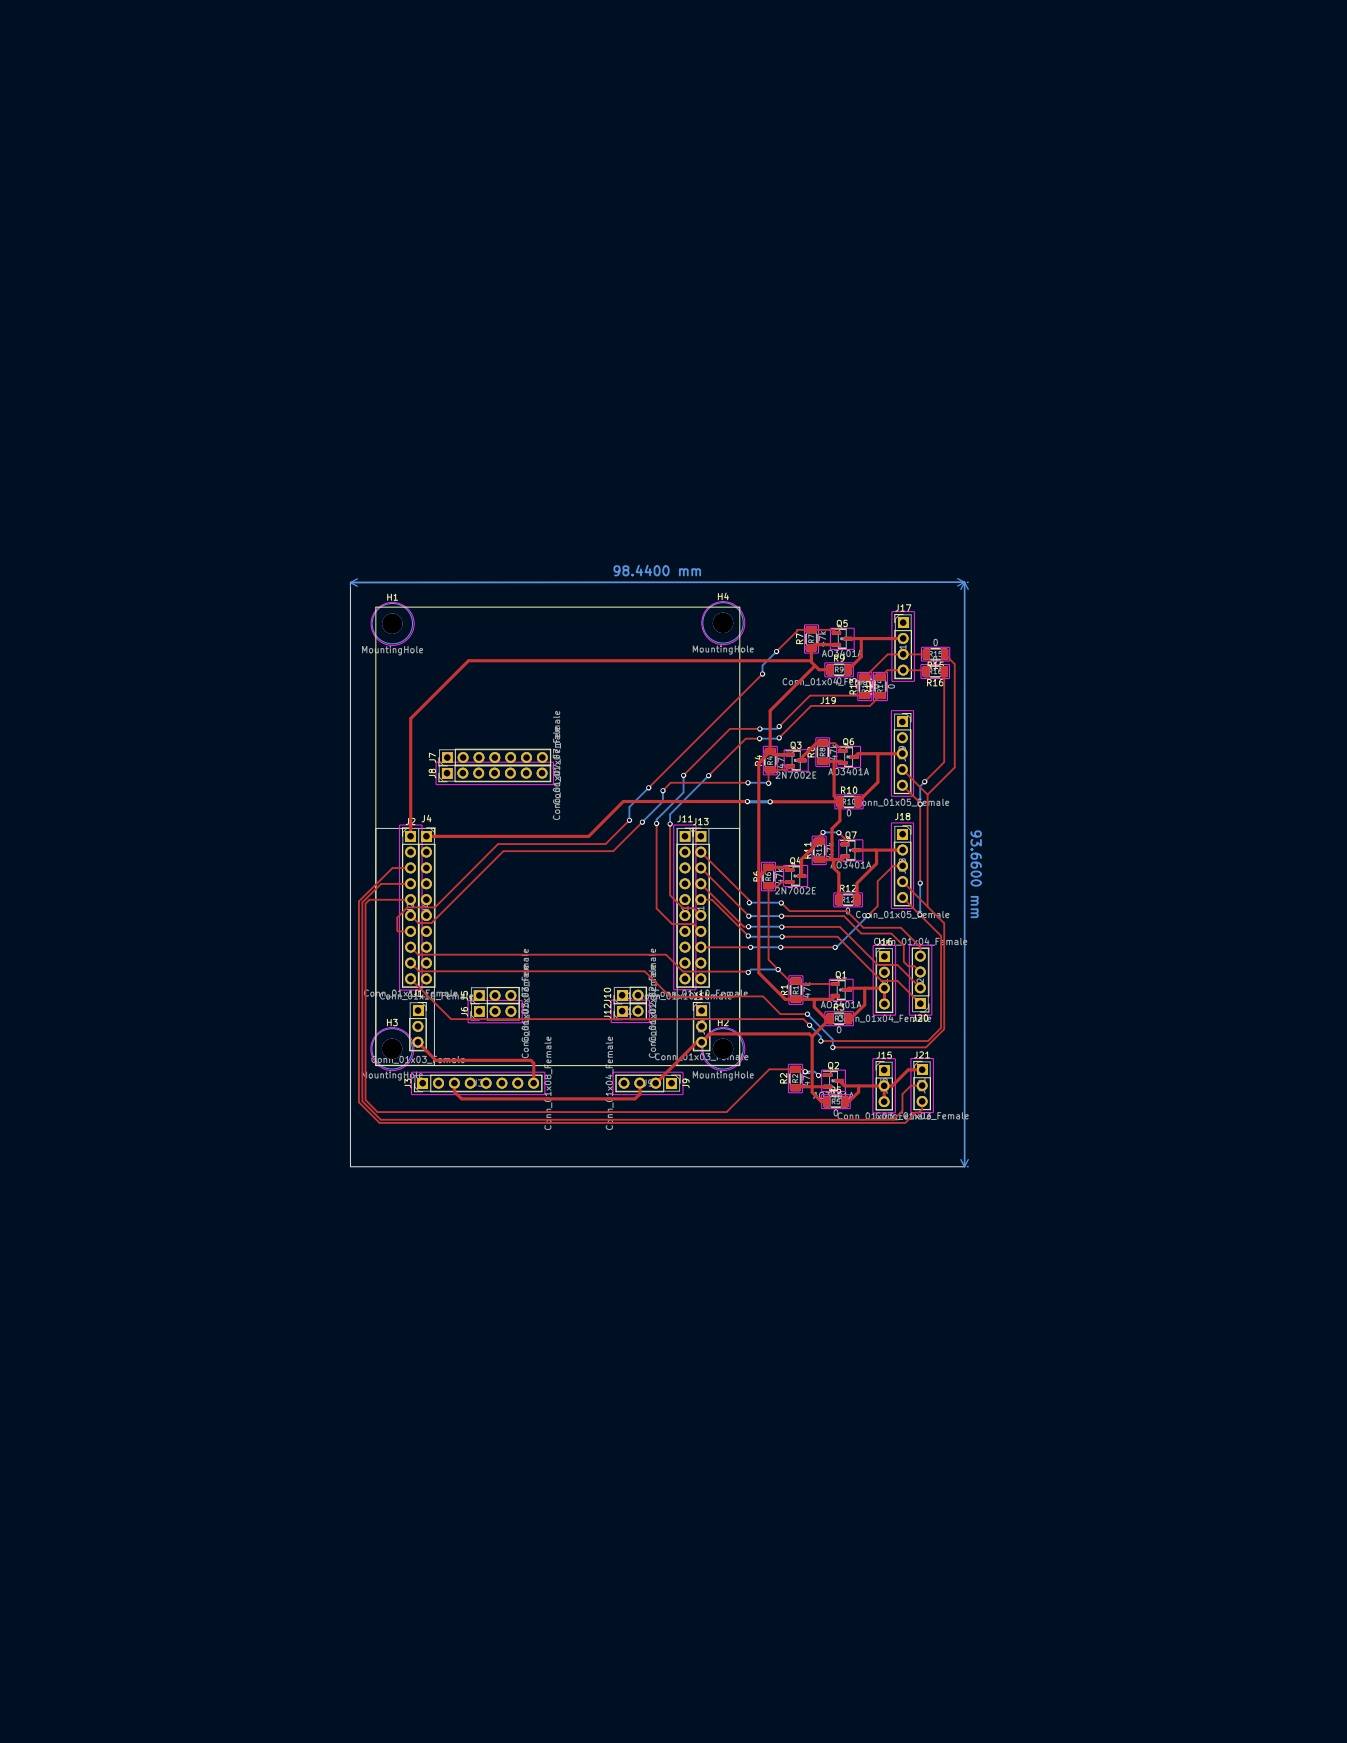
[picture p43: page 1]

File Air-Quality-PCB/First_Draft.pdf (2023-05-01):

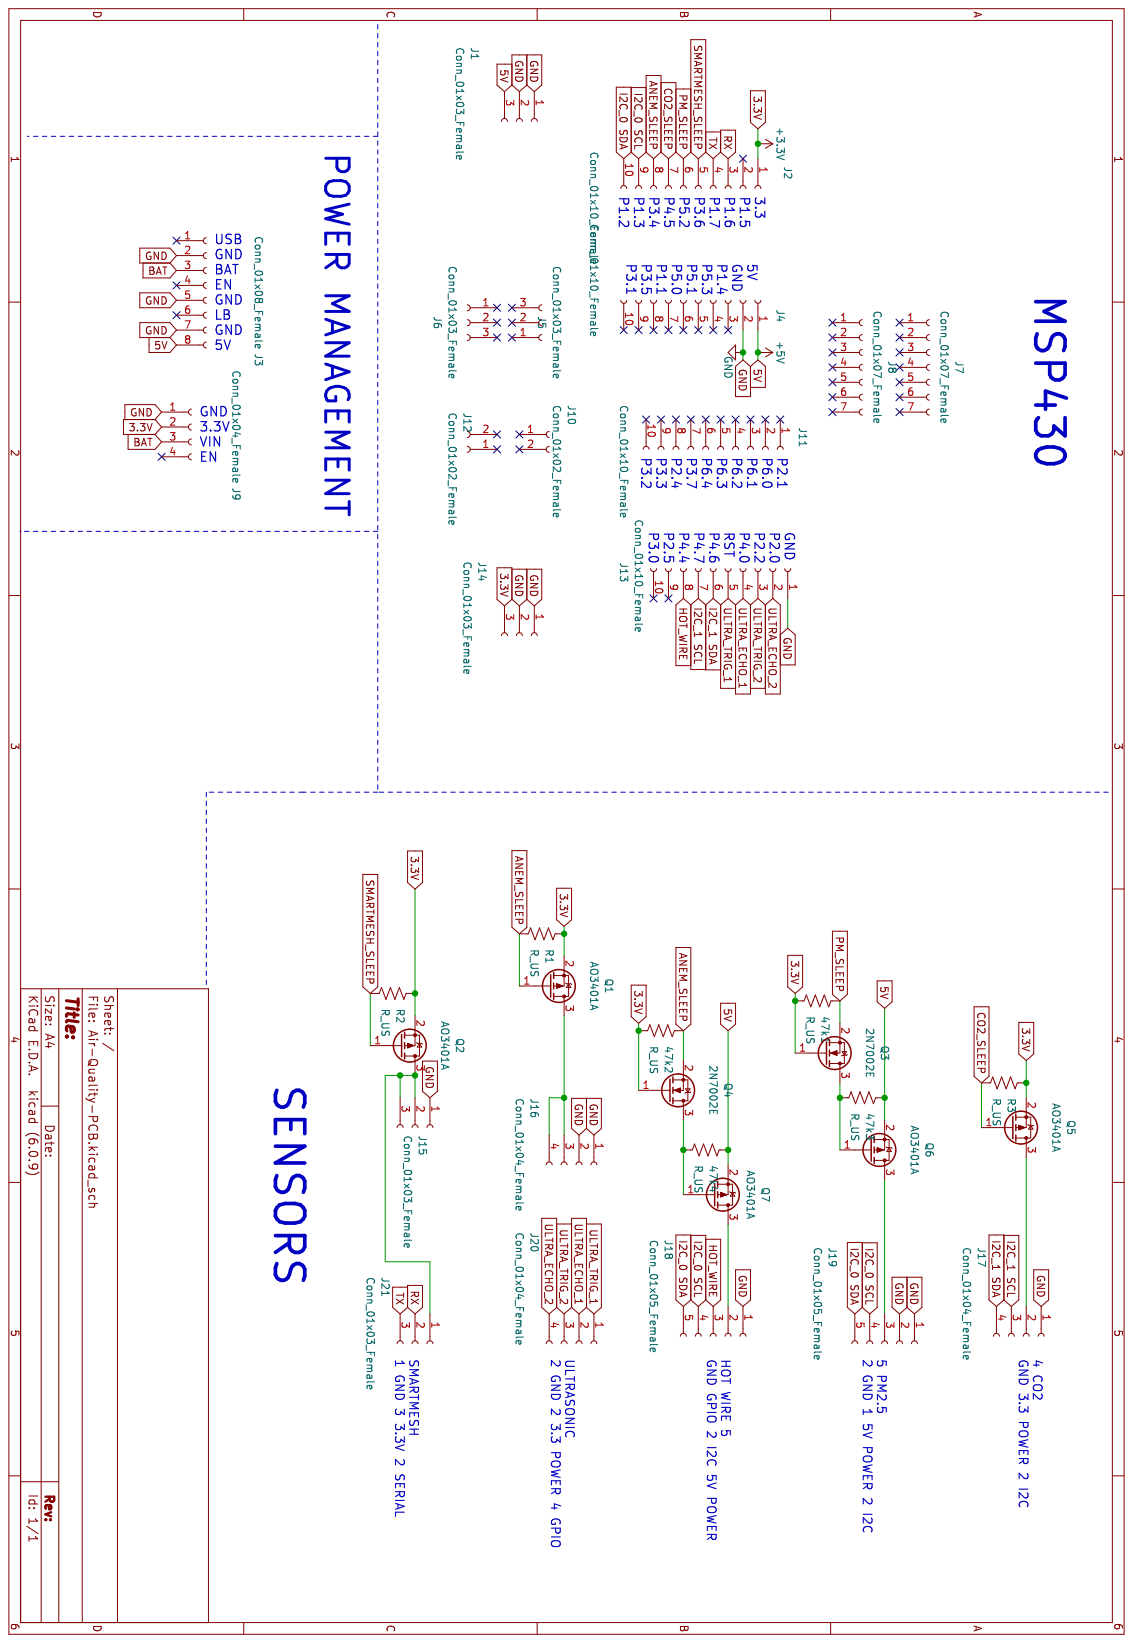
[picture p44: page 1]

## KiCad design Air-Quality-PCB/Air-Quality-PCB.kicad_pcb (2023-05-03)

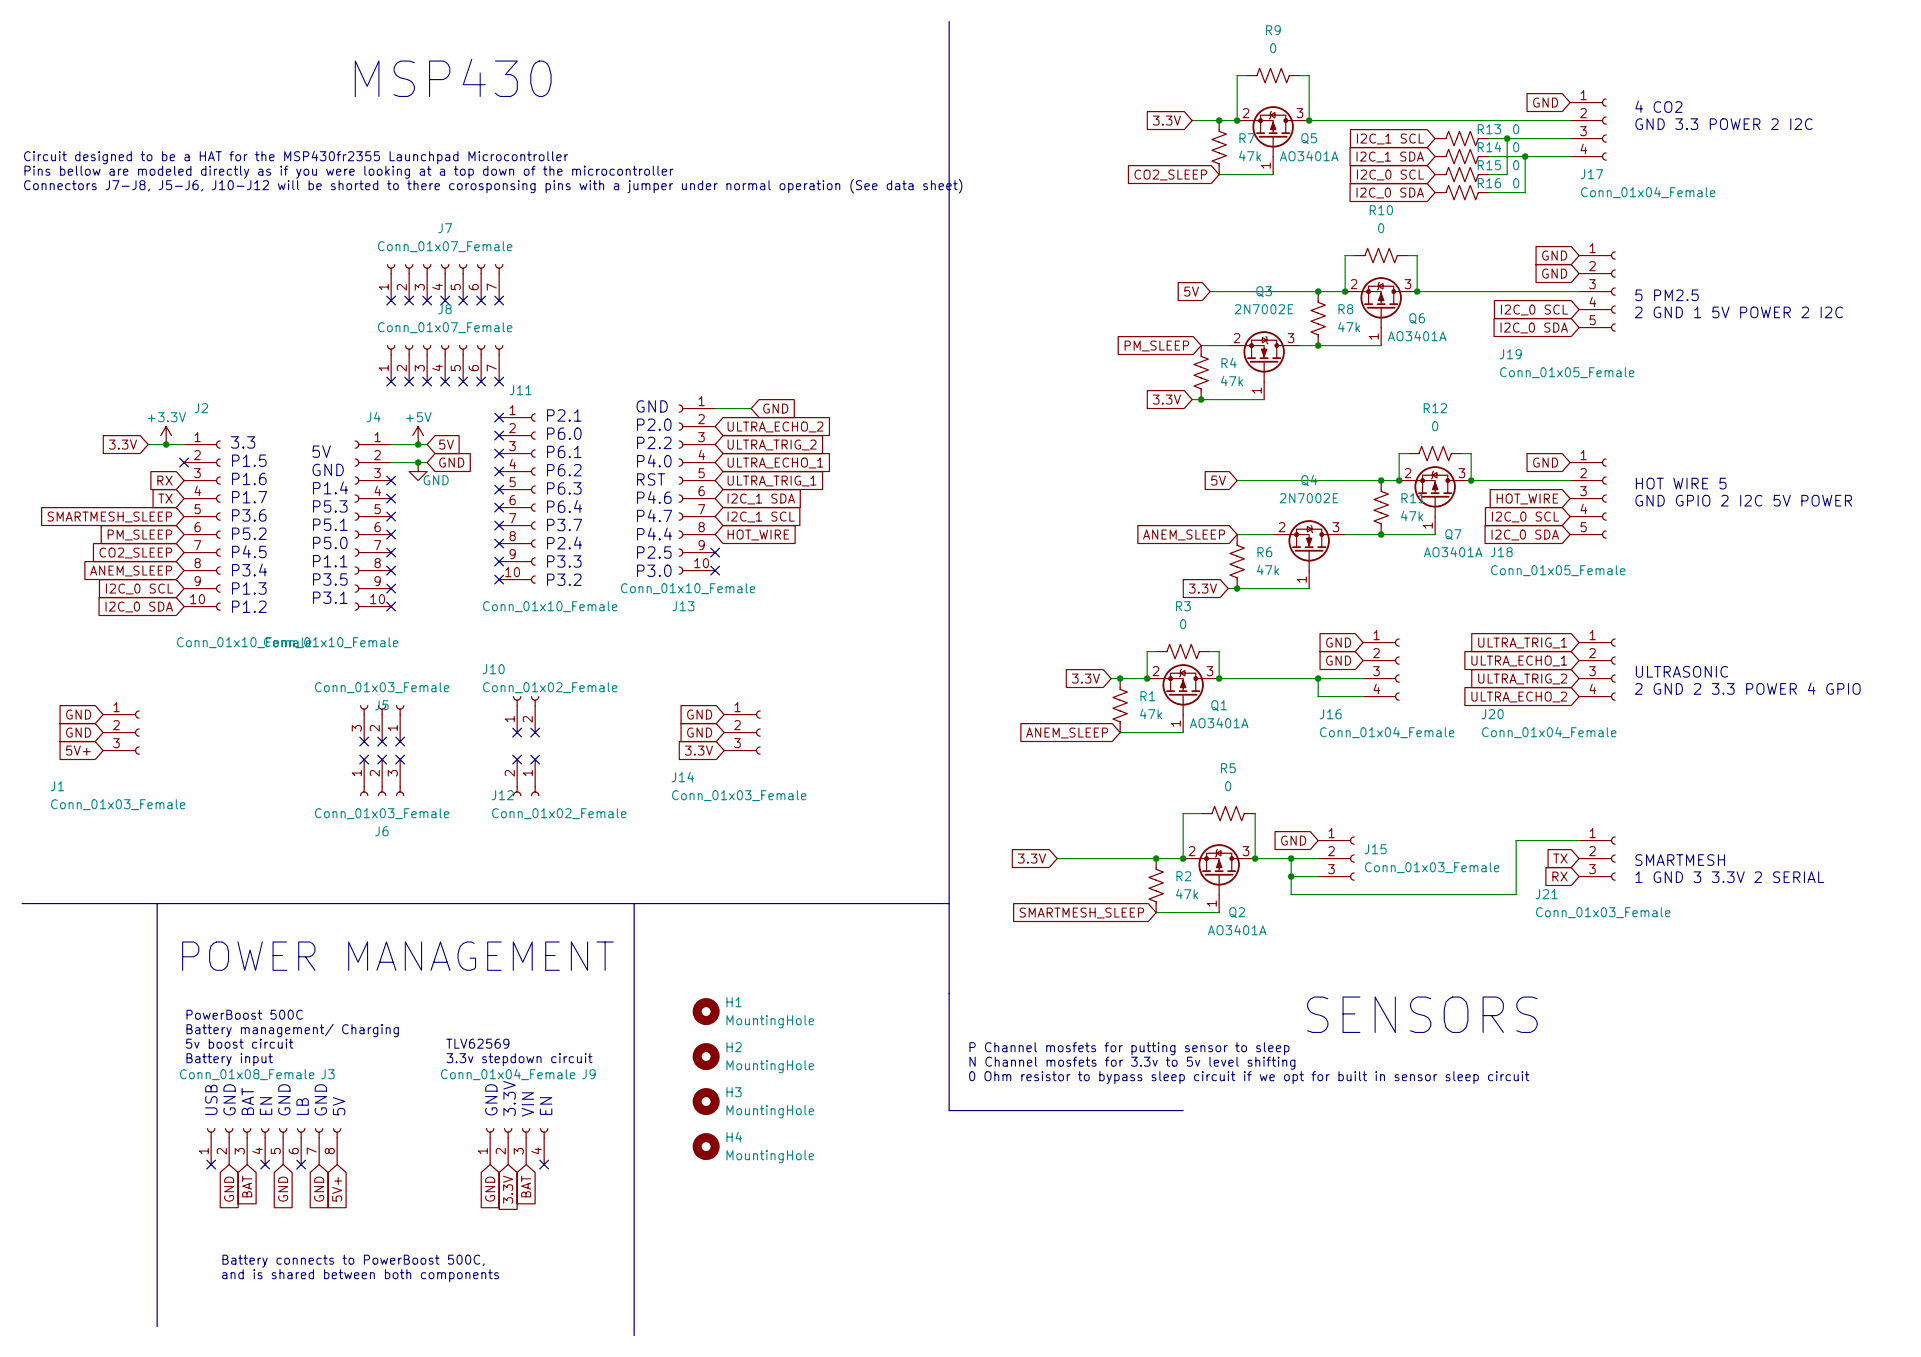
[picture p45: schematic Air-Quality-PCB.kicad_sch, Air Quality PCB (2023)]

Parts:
H1, H2, H3, H4: MountingHole; MountingHole_3.2mm_M3
J1: Conn_01x03_Female; PinSocket_1x03_P2.54mm_Vertical
J2, J13: Conn_01x10_Female; PinHeader_1x10_P2.54mm_Vertical
J3: Conn_01x08_Female; PinHeader_1x08_P2.54mm_Vertical
J4, J11: Conn_01x10_Female; PinSocket_1x10_P2.54mm_Vertical
J5, J6, J14, J15, J21: Conn_01x03_Female; PinHeader_1x03_P2.54mm_Vertical
J7, J8: Conn_01x07_Female; PinHeader_1x07_P2.54mm_Vertical
J9, J16, J17, J20: Conn_01x04_Female; PinHeader_1x04_P2.54mm_Vertical
J10, J12: Conn_01x02_Female; PinHeader_1x02_P2.54mm_Vertical
J18, J19: Conn_01x05_Female; PinSocket_1x05_P2.54mm_Vertical
Q1, Q2, Q5, Q6, Q7: AO3401A; SOT-23
Q3, Q4: 2N7002E; SOT-23
R1, R2, R4, R6, R7, R8, R11: 47k; R_1206_3216Metric
R3, R5, R9, R10, R12, R13, R14, R15, R16: 0; R_1206_3216Metric

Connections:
3.3V: J2.1, J9.2, J14.3, Q1.2 (S), Q2.2 (S), Q3.1 (G), Q4.1 (G), Q5.2 (S), R1.1, R2.1, R3.1, R4.2, R5.1, R6.2, R7.1, R9.1
5V: J4.1, Q6.2 (S), Q7.2 (S), R8.1, R10.1, R11.1, R12.1
5V+: J1.3, J3.8
ANEM_SLEEP: J2.8, Q1.1 (G), Q4.2 (S), R1.2, R6.1
BAT: J3.3, J9.3
CO2_SLEEP: J2.7, Q5.1 (G), R7.2
GND: J1.1, J1.2, J3.2, J3.5, J3.7, J4.2, J9.1, J13.1, J14.1, J14.2, J15.1, J16.1, J16.2, J17.1, J18.1, J19.1, J19.2
HOT_WIRE: J13.8, J18.3
I2C_0 SCL: J2.9, J18.4, J19.4, R15.1
I2C_0 SDA: J2.10, J18.5, J19.5, R16.1
I2C_1 SCL: J13.7, R13.1
I2C_1 SDA: J13.6, R14.1
unnamed: J15.2, J15.3, J21.1, Q2.3 (D), R5.2
unnamed: J16.3, J16.4, Q1.3 (D), R3.2
unnamed: J17.2, Q5.3 (D), R9.2
unnamed: J17.3, R13.2, R15.2
unnamed: J17.4, R14.2, R16.2
unnamed: J18.2, Q7.3 (D), R12.2
unnamed: J19.3, Q6.3 (D), R10.2
unnamed: Q3.3 (D), Q6.1 (G), R8.2
unnamed: Q4.3 (D), Q7.1 (G), R11.2
PM_SLEEP: J2.6, Q3.2 (S), R4.1
RX: J2.3, J21.3
SMARTMESH_SLEEP: J2.5, Q2.1 (G), R2.2
TX: J2.4, J21.2
ULTRA_ECHO_1: J13.4, J20.2
ULTRA_ECHO_2: J13.2, J20.4
ULTRA_TRIG_1: J13.5, J20.1
ULTRA_TRIG_2: J13.3, J20.3

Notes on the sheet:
Battery connects to PowerBoost 500C, and is shared between both components
GND 3.3V VIN EN
P2.1 P6.0 P6.1 P6.2 P6.3 P6.4 P3.7 P2.4 P3.3 P3.2
SENSORS
3.3 P1.5 P1.6 P1.7 P3.6 P5.2 P4.5 P3.4 P1.3 P1.2
GND P2.0 P2.2 P4.0 RST P4.6 P4.7 P4.4 P2.5 P3.0
5V GND P1.4 P5.3 P5.1 P5.0 P1.1 P3.5 P3.1
4 CO2 GND 3.3 POWER 2 I2C 5 PM2.5 2 GND 1 5V POWER 2 I2C HOT WIRE 5 GND GPIO 2 I2C 5V POWER ULTRASONIC 2 GND 2 3.3 POWER 4 GPIO SMARTMESH 1 GND 3 3.3V 2 SERIAL
TLV62569 3.3v stepdown circuit
USB GND BAT EN GND LB GND 5V
Circuit designed to be a HAT for the MSP430fr2355 Launchpad Microcontroller Pins bellow are modeled directly as if you were looking at a top down of the microcontroller Connectors J7-J8, J5-J6, J10-J12 will be shorted to there corosponsing pins with a jumper under normal operation (See data sheet)
MSP430
P Channel mosfets for putting sensor to sleep N Channel mosfets for 3.3v to 5v level shifting 0 Ohm resistor to bypass sleep circuit if we opt for built in sensor sleep circuit
PowerBoost 500C Battery management/ Charging 5v boost circuit Battery input
POWER MANAGEMENT

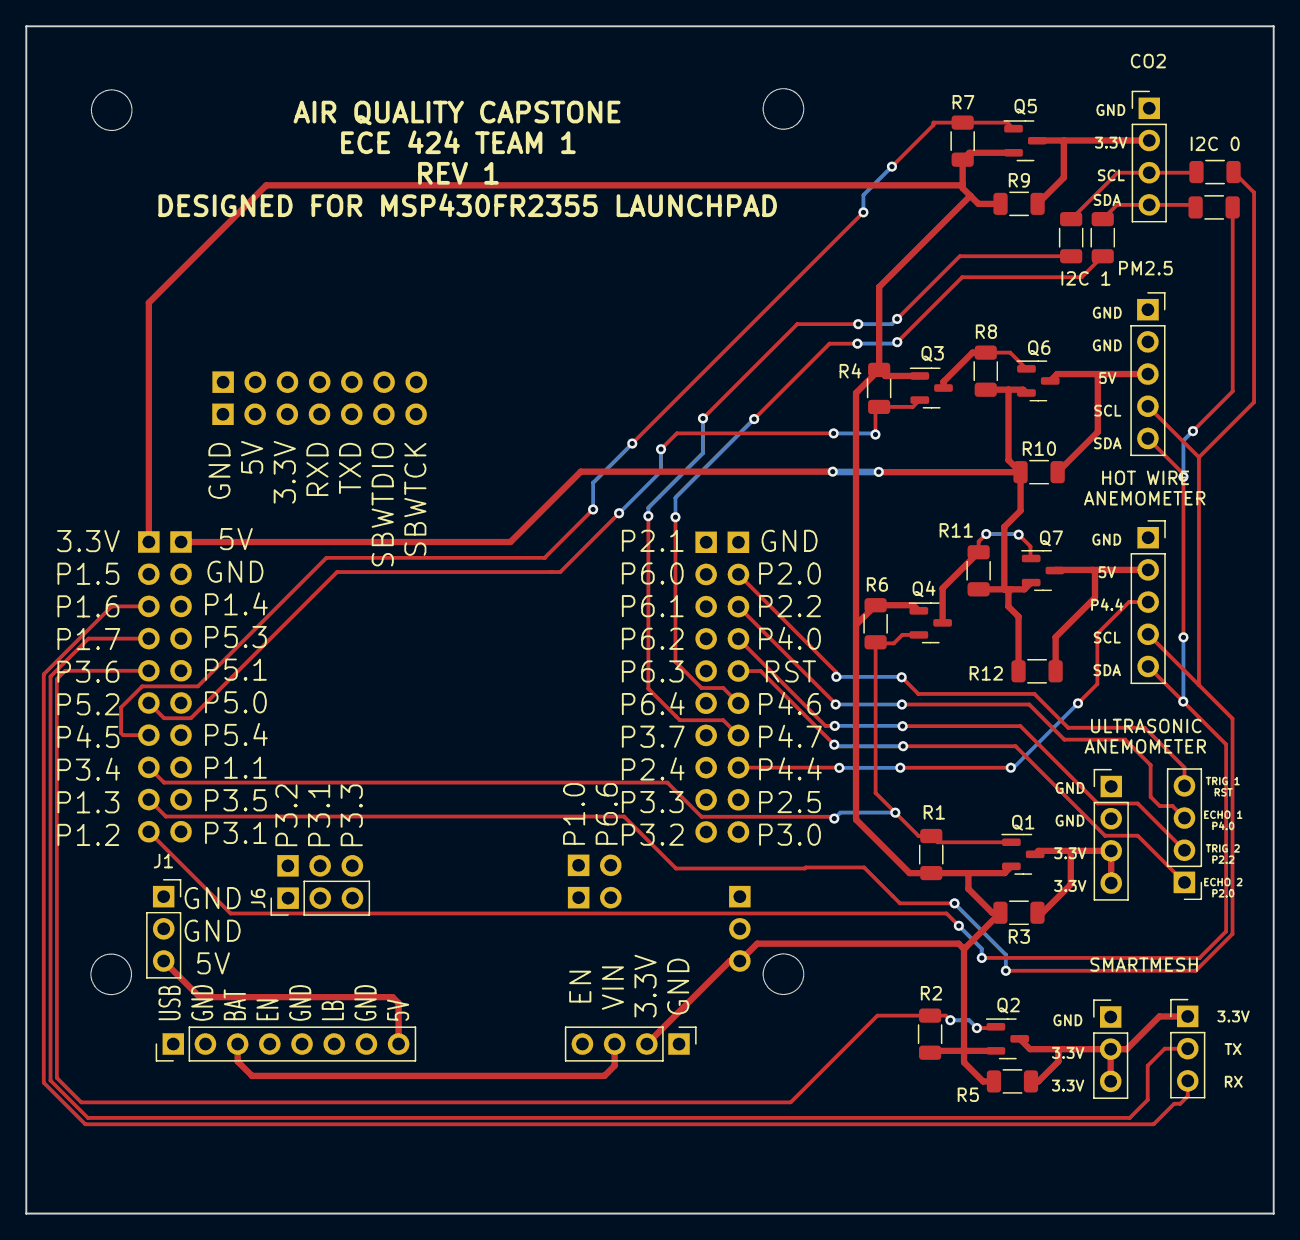
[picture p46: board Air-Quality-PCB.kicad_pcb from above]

Board: 2 copper layers, 98.4 x 93.7 mm, 48 parts (0 on the bottom side), 29 nets.

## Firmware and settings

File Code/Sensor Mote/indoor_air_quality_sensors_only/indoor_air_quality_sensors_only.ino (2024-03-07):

#include <sgp30.h>
#include <sps30.h>


#define powerTest false


#define SCL 9
#define SDA 10
#define LB 27


#define ANEM_SLEEP_PIN 5   // Set Anemometer sleep pin to 5 to enable, 0 to disable
#define PM_SLEEP_PIN 6    // Set PM sleep pin to 6 to enable, 0 to disable
#define CO2_SLEEP_PIN 7   // Set CO2 sleep pin to 7 to enable, 0 to disable


#define BATTERY_LIFE 2    // Set to 0 for 1 year, 1 for 6 months, or 2 for 3 months


#define SPS_FP true		// Set to true for PM sensor floating point values, false for 16-bit unsigned integers

/*// Uncomment this section for Climate Guard Anemometer
  #include <cgAnem.h>
  CG_Anem anem;
  #define ANEM_OFFSET 0
  //*/


// Uncomment this section for Ultrasonic Anemometer
#include <UltrasonicAnem.h>
UltrasonicAnem anem;
#define ANEM_OFFSET 1
//*/


#define debug true


uint64_t time_ms, nextTime;


SGP30 co2;
SPS30 pm;


uint8_t nextDevice;
#define CO2 0
#define PM 1
#define ANEM 2
#define TEST 3


bool anem_present;


const uint64_t pm_periods[3][3] =   {{4320000, 15600000, 6300000},
                                     {2040000,  6600000, 2880000},
                                     { 960000,  2820000, 1320000}};
                                  
const uint64_t co2_periods[3][3] =  {{2220000, 13200000, 3060000},
                                     {1080000,  5400000, 1500000},
                                     { 510000,  2400000,  720000}};
                                  
const uint64_t anem_periods[3][3] = {{0xFFFFFFFFFFFFFFFF, 5160000, 40000},
                                     {0xFFFFFFFFFFFFFFFF, 2160000, 20000},
                                     {0xFFFFFFFFFFFFFFFF,  960000, 10000}};


bool alertSent = false;


void nextDev() {
  nextTime = co2.time_ms;
  nextDevice = CO2;

  if (pm.time_ms < nextTime) {
    nextTime = pm.time_ms;
    nextDevice = PM;
  }

  if (anem_present && anem.time_ms < nextTime) {
    nextTime = anem.time_ms;
    nextDevice = ANEM;
  }

  if (nextTime == 0xFFFFFFFFFFFFFFFF) {
    Serial.println("TEST DEV");
    nextTime = millis() + 10000;
    nextDevice = TEST;
  }
}


void setup() {
  Serial.begin(9600);
  Serial.println("Starting");
  
  for (int i = 1; i <= 40; i++) {
    digitalWrite(i, LOW);
    pinMode(i, OUTPUT);
  }

  pinMode(1, INPUT);
  pinMode(21, INPUT);

  pinMode(SCL, INPUT_PULLUP);
  pinMode(SDA, INPUT_PULLUP);
  pinMode(LB, INPUT_PULLUP);

  int max_clock = 400000;
  if (co2.max_clock < max_clock) {
    max_clock = co2.max_clock;
  }

  if (pm.max_clock < max_clock) {
    max_clock = pm.max_clock;
  }

  if (anem.max_clock < max_clock) {
    max_clock = anem.max_clock;
  }

  Wire.setModule(0);
  Wire.begin();
  Wire.setClock(max_clock);

  bool sensed = false;

  // Initialize PM Sensor
  sensed = pm.begin(MCPM2p5, SPS_FP, debug, PM_SLEEP_PIN);
  if (!sensed) {
    if (debug) Serial.println("ERROR: PM sensor not connected!");
    while (!powerTest);
  }

  // Initialize CO2 Sensor
  sensed = co2.begin(debug, CO2_SLEEP_PIN);
  if (!sensed) {
    if (debug) Serial.println("ERROR: CO2 sensor not connected!");
    while (!powerTest);
  }

  // Initialize Anemometer, if present
  anem_present = anem.begin(ANEM_SLEEP_PIN, debug);
  if (anem_present) {
    if (debug) Serial.println("Anemometer connected!");
  } else {
    if (debug) Serial.println("Anemometer not connected!");
    anem.time_ms = 0xFFFFFFFFFFFFFFFF;
  }

  // Set Measurement Periods
  if (!powerTest) {
    if (anem_present) {
      pm.period_ms = pm_periods[BATTERY_LIFE][1 + ANEM_OFFSET];
      co2.period_ms = co2_periods[BATTERY_LIFE][1 + ANEM_OFFSET];
      anem.period_ms = anem_periods[BATTERY_LIFE][1 + ANEM_OFFSET];
      Serial.println((uint32_t)pm.period_ms);
      Serial.println((uint32_t)co2.period_ms);
      Serial.println((uint32_t)anem.period_ms);
    } else {
      pm.period_ms = pm_periods[BATTERY_LIFE][0];
      co2.period_ms = co2_periods[BATTERY_LIFE][0];
      anem.period_ms = anem_periods[BATTERY_LIFE][0];
      Serial.println((uint32_t)pm.period_ms);
      Serial.println((uint32_t)co2.period_ms);
    }
  }

  if (debug) Serial.println("Sleeping to first device function");
  nextDev();
  time_ms = nextTime;
  if (time_ms > millis()) {
    sleep(time_ms - millis());
  }
}

void loop() {
  if (digitalRead(LB) && alertSent) {
    alertSent = false;
    if (debug) Serial.println("Battery Charged");
  }
  
  if (!digitalRead(LB) && !alertSent) {
    alertSent = true;
    if (debug) Serial.println("ALERT: LOW BATTERY");
  } else {
    // Execute next function
    Serial.println("Started loop execution");
    uint32_t startTime = millis();
  
    if (debug) Serial.println("Performing device function");
    switch (nextDevice) {
      case CO2:
        if (debug) Serial.println("eCO2");
  
        if (anem_present && ANEM_SLEEP_PIN != 0 && ANEM_OFFSET == 0) anem.cg_wakeup();
        co2.startNextFunc(time_ms + startTime - millis());
        if (co2.measurement_ready && anem_present && ANEM_SLEEP_PIN != 0 && ANEM_OFFSET == 0) anem.cg_sleep();
  
        break;
      case PM:
        if (debug) Serial.println("PM");
  
        if (anem_present && ANEM_SLEEP_PIN != 0 && ANEM_OFFSET == 0) anem.cg_wakeup();
        if (CO2_SLEEP_PIN != 0) co2.sgp30_wakeup_transistor();
        pm.startNextFunc(time_ms + startTime - millis());
        if (pm.measurement_ready && anem_present && ANEM_SLEEP_PIN != 0 && ANEM_OFFSET == 0) anem.cg_sleep();
        if (pm.measurement_ready && CO2_SLEEP_PIN != 0) co2.sgp30_sleep_transistor();
        break;
      case ANEM:
        if (debug) Serial.println("Anemometer");
  
        if (CO2_SLEEP_PIN != 0) co2.sgp30_wakeup_transistor();
        anem.startNextFunc(time_ms + startTime - millis());
        if (anem.measurement_ready && CO2_SLEEP_PIN != 0) co2.sgp30_sleep_transistor();
  
        break;
    }
  }

  // Print out measurements
  if (debug) {
    Serial.println("Device Function Finished");
    switch (nextDevice) {
      case CO2:
        if (co2.measurement_ready) {
          Serial.print("eCO2: ");
          Serial.print(co2.co2);
          Serial.println(" ppm");
        }
        break;
      case PM:
        if (pm.measurement_ready) {
          switch (pm.measurementIx) {
            case MCPM2p5:
              Serial.print("PM2.5 ");
              if (pm.fp) {
                Serial.print(pm.pm2p5_float);
              } else {
                Serial.print(pm.pm2p5_int);
              }
              Serial.println(" ug/m3");
              break;
            case NCPM2p5:
              Serial.print("PM2.5 ");
              if (pm.fp) {
                Serial.print(pm.pm2p5_float);
              } else {
                Serial.print(pm.pm2p5_int);
              }
              Serial.println(" per cm3");
              break;
          }
        }
        break;
      case ANEM:
        if (anem.measurement_ready) {
          Serial.print("Airflow: ");
          Serial.print(anem.airflowRate);
          Serial.println(" m/s");
        }
        break;
    }
  }

  // Execution finished, find next function
  if (debug) Serial.println("Finding next function");
  nextDev();
  // Calculate time until next function
  // Check if millis() has overflowed
  uint32_t currTime_32 = millis();
  uint64_t currTime_ms = (time_ms & 0xFFFFFFFF00000000) + currTime_32;
  if (currTime_ms < time_ms) {
    if (debug) Serial.println("millis() overflowed!");
    currTime_ms += 0x0000000100000000;
  }

  // If next time hasn't passed, sleep until then
  if (debug) Serial.println("Sleeping\n");
  if (nextTime > currTime_ms + (millis() - currTime_32)) {
    uint32_t sleepTime = nextTime - (currTime_ms + (millis() - currTime_32));
    if (debug) Serial.println(sleepTime);
    uint64_t i;
    for (i = 0xFFFFFFFFFFFFFFFF; (i + 65536) < sleepTime && (digitalRead(LB) || alertSent); i += 65536) {
      if (debug) Serial.println((uint32_t)i);
      sleep(65536);
    }

    if (i + 65536 < sleepTime) {
      time_ms = nextTime - sleepTime + i + 1;
    } else {
      sleep(sleepTime % 65536);
      time_ms = nextTime;
    }
  } else {
    time_ms = currTime_ms + (millis() - currTime_32);
  }

  Serial.println();
}

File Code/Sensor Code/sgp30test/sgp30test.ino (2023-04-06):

#include <sgp30.h>
#include <Wire.h>


uint64_t time_ms;


SGP30 sgp30;


void setup() {
  for (int i = 0; i < 40; i++) {
    digitalWrite(i, LOW);
    pinMode(i, OUTPUT);
  }

  Serial.begin(9600);
  Wire.begin();
  sgp30.begin(millis());

  // Set time_ms and delay to start time
  time_ms = sgp30.time_ms;
  while (millis() < time_ms);
}

void loop() {
  // Execute next function
  sgp30.startNextFunc(millis());

  // Sleep until next function
  sleep(sgp30.time_ms - millis());
}

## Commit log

2023-01-08 Configuration power consumption calculator added
2023-01-09 Added battery capacity calculations
2023-01-13 Added input and output files
    [Power Consumption Test - Power Consumption.csv]
2023-01-16 Added Excel file of Gantt Chart
    Does need to be updated after meeting with team
    [412_GanttChart.xlsx]
2023-01-19 Ultrasonic Anemometer
2023-01-19 Graphing added
    [Power Consumption Test - Power Consumption.csv]
2023-01-22 Added Period Calculation
    [Power Consumption Test - Power Consumption.csv]
2023-01-22 Ultrasonic Sensor Testing
2023-01-25 Add files via upload
    uploaded power consumption test for all possible sensors
2023-02-01 added spring and winter timelines
2023-02-10 Updated Power Consumption Calculations
    [Power Consumption Test - Power Consumption.csv]
2023-02-10 Added Ultrasonic Anemometer Test Code
2023-02-14 Modified Graph and Text Output Formatting
    [Power Consumption Test - Power Consumption.csv]
2023-03-27 I2C Test
2023-03-27 Modified ultrasonic pulse generation code
2023-04-06 Refactor CO2 and PM Sensor libraries to use non-blocking code compatible with sleep Added example code for CO2 and PM sensors
2023-04-12 Moved sensor test code into library example folders
2023-04-12 SPS30 UART Test
2023-04-13 Added sensor spoofing
2023-04-13 Fixed I2C initialization
2023-04-15 Added New Wire library, with larger rx/tx buffer size
2023-04-15 Update main code with sensor fixes and begin anemometer implementation
2023-04-17 Full hardware prototype (minus SmartMesh and Anemometer testing) finished
2023-04-17 Breadboard prototype image
2023-04-19 Added Ultrasonic Anemometer Library
2023-04-19 Relocated Power Testing Data/Code
    [Power Consumption Test - Power Consumption.csv, Power Consumption Test Results - Power Consumption.csv]
2023-04-28 Started power consumption testing
    [Power Consumption Test Results - Power Consumption.csv, Power Estimation - Power Consumption.csv]
2023-04-28 Period changes for power consumption testing
2023-05-01 Ki-Cad first round
    [Air-Quality-PCB.kicad_pcb, Air-Quality-PCB.kicad_sch]
2023-05-08 Created Sensor Mote code folder
2023-05-08 Added initial enclosure CAD files
    [2holeLid.FCStd, 4holeLid.FCStd, EnclosurePrintWHoles.FCStd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]
2023-05-08 Store received data in log as single integer, rather than (sensor, value) pair
2023-05-08 Fixed receiver printing out example log file as a known mote
2023-05-09 Switched to Hex representation in log file
2023-05-12 Laser Cutting file added
    [box.dxf]
2023-05-16 Convert enclosure files to STL and add laser cutting DXF file
    [2holeLid.FCStd, 2holeLid.stl, 4holeLid.FCStd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]
2023-05-16 Initial power testing data added and periods modified
    [Power Consumption Test Results - Power Consumption.csv]
2023-05-16 V2 Laser cutting
    [box_v2.dxf]
2023-05-18 Library fixes for PCB
    [indoor_air_quality_sensors_only.ino]
2023-06-03 Power testing completed
    [Power Consumption Test Results - Power Consumption - Ultrasonic.csv, Power Consumption Test Results - Power Consumption.csv]
2023-06-03 Sensor fixes, add low battery alert, add battery life configuration
    [indoor_air_quality_sensors_only.ino]
2023-06-03 Low Battery alert start
2023-06-03 SGP30 Calibration stopped
2023-06-03 Removed calibration
2023-06-05 Fixed lines for same sensor node on different plots to be the same color
2023-06-05 Added Low Battery Alert
2023-06-07 Attempt to get Ultrasonic Anemometer functioning
2023-06-09 Added timestamp to low battery alert
2023-06-09 Recalculate Hotwire Anemometer periods and change hotwire anemometer to take data when turned on to run another sensor
2023-06-19 # This is a combination of 5 commits. # This is the 1st commit message:
    Added average/max select
    # This is the commit message #2:
    Upload Google Drive Files
    # This is the commit message #3:
    Added Final Report and fixed anemometer only mode
    # This is the commit message #4:
    Revert "Upload Google Drive Files"
    This reverts commit cf6523294dbf64ac466843ab0e1e2c67d2094a8c.
    # This is the commit message #5:
    Fixed google drive upload
    [Battery management Indoor Air Quality Monitor Order.xlsx, Capstone Project Equipment Checkout.xlsx, Gantt Chart 412.xlsx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]
2023-08-08 Fixed motes failing power-on
2023-08-18 Removed example button, plotted example data by default, and fixed background color
2023-10-23 PurpleAir Data
    [94449 2023-08-19 2023-08-22 0-Minute Average.csv, 94449 2023-08-19 2023-08-22 10-Minute Average.csv, 94449 2023-08-19 2023-08-22 30-Minute Average.csv]
2023-10-23 SCD41 Power Testing
    [Power Consumption Test Results - Power Consumption - Hotwire SGP30.csv, Power Consumption Test Results - Power Consumption - SCD41 LP.csv, Power Consumption Te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]
